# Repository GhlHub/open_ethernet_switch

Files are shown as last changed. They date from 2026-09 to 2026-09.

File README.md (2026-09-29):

# Open Ethernet Switch

A work-in-progress FPGA Ethernet switch for the AMD Kria KR260, with an initial R5
FreeRTOS control plane. The current RTL joins port adapters, MAC
learning/lookup/aging, and a shared DDR packet-buffer architecture under
the reusable blocks described in [`ip_repo`](ip_repo/README.md), with
`rtl/switch_top.sv` retaining the native simulation assembly.

The source now adds [classic STP/RSTP selection and persistent web controls](docs/spanning-tree.md).
Fabric/management 2.1 and the matching firmware are deployed with STP disabled;
STP/RSTP board qualification is deferred.

The current 2026-09-27 lab build uses fabric/management 2.1 and GEM 2.0,
with the switch fabric at 125 MHz. Independent statistics mailboxes provide
per-bank clock/freshness reporting (ABI 2). PL MAC 1.2 and PHY-management 1.1 support full-duplex
10/100/1000 Mb/s on both PL copper ports. SFP 1.1 remains 1G.
Production uses nine catalog instances from six reusable IP kinds.
It includes [CPU TX frame metadata](docs/cpu-tx-metadata.md), pipelined CPU DDR
writes and a [low-priority MAC-table dump master](docs/mac-table-dump.md).
The public `/mac-table` web page displays MAC addresses, ports and ages; its
**Refresh MAC table** button requests a scan. Opening/reloading the page uses
cached data; no automatic scans are scheduled. The latest firmware source also
adds [passive IPv4 discovery](docs/web-interface.md#passive-ipv4-discovery-2026-09-27-deployed)
to this page; it is deployed and verified on the board.

The matching FPGA and R5 firmware are deployed over JTAG at DHCP address
`10.0.1.104`. Routed timing passes (fabric +1.710 ns setup; overall +0.018 ns
setup / +0.010 ns hold). Earlier speed qualification passed both PL ports at
10, 100 and 1000 Mb/s. The current image adds stopped-clock isolation and
public SNMP/web bank availability reporting.
See [deployment evidence](docs/verification.md#2026-09-27-interrupt-driven-cpu-packet-dma)
and the [current backlog](docs/inventory.md#current-remaining-work).

CPU TX/RX completion is interrupt-driven, with blocked-task wakeups and bounded
RX batches. Hardware verification passed 2,000 CPU and 100 forwarded full-size
pings without loss, concurrent HTTP/SNMP, and zero DMA errors or TX timeouts.
The configuration page shows the active IPv4 address, netmask and default gateway
above the saved settings, and uses wider address and credential fields. See
[web interface](docs/web-interface.md).

A [screw-fastened KR260 clamshell](mechanical/kr260-enclosure/README.md) includes
print-ready STLs, assembly STEP, source and a measured carrier-fit report.
Its CAD checks pass; physical print fit and enclosed cooling remain untested.

The intended port map is two PS GEM ports, two PL Ethernet ports, one SFP port,
and one virtual CPU port. The default SFP build is 1G 1000BASE-X.
A [selectable 10GBASE-R MAC/PCS and 128-bit SFP datapath](docs/sfp-10g.md)
is available with `KR260_SFP_MODE=10g`. A [runtime dual-rate build](docs/sfp-dual.md)
uses `KR260_SFP_MODE=dual` for 1G/10G selection without reloading the FPGA.
The dual-rate image is currently running through volatile JTAG. Hardware tests
verified 1G forwarding, Auto recovery, and a hot swap to an XZSNET copper
module with a 10G host link through a 2.5G-capable switch. Small packet losses
also appeared on copper-only controls; loss-free operation, sustained rate
conversion and actual copper-rate confirmation remain open. See the
[verification record](docs/verification.md). Boot flash was not changed.

The board top includes automatic PL PHY initialization and link polling,
RGMII receive clock adaptation, calibration gating, link-event interrupts,
software-controlled port flushing, and SFP I²C/sideband control. The GEM bridges
carry whole 16-bit words across the clock boundary and use buffered TX start
permits. The switch fabric now runs at 125 MHz; MAC adapters transfer whole
words and the egress frame RAM is prefetched for continuous streaming. The board top connects the digital switch to the PS external GEM FIFOs,
DDR interconnect, CPU-facing AXI DMA, two RGMII ports, and the SFP GTH path.
Vivado build scripts and three IP configurations are included. Existing local
implementation reports show a generated bitstream and positive setup/hold
slack under the current constraints. R5 hardware bring-up now demonstrates UART, timers, DHCP acquisition and ping through all four copper Ethernet ports via
the fabric CPU port. Cable moves retained reachability at `10.0.1.214` on the
running debug image. See the [four-port results](docs/verification.md#four-copper-ports-passing-dhcp-address-ping-2026-09-20).
The SFP path now acquires the same DHCP address through an Ipolex copper SFP
and passes settled small/full-MTU ping tests on the debug image; startup loss
and isolated bring-up errors remain under investigation. The managed switch
RX-error counter subsequently remained stable at 803. Together with the
four copper-port results, this establishes the
`20260920-all_ports_passing_dhcp_ping` basic-connectivity milestone.
A subsequent intermittent-loss investigation captured SFP GTH decoder errors;
the receiver now explicitly uses LPM equalization. Initial LPM testing passed
300/300 full-MTU pings to an endpoint through GEM0 and 300/300 patterned
full-MTU CPU pings, with no SFP MAC receive errors. A brief post-boot
interruption in that debug run remains unexplained. The normal image now
runs without ILAs or a debug hub and includes ingress-port exclusion on MAC
lookup hits; it passed DHCP and 300/300 full-MTU pings to both CPU and GEM0
endpoint with zero SFP receive errors. See [SFP results](docs/sfp-debug.md).
**Sustained throughput, fault recovery, remaining CDC review and complete SFP
hardware validation remain pending.**

- [IP partitioning, packaging and verification](docs/ip-partitioning.md)
- [Architecture diagrams and packet flow](docs/architecture.md)
- [Memory map, cache policy and ownership](docs/memory-map.md)
- [Statistics and environmental monitoring](docs/statistics.md)
- [SNMP counter and sensor access](docs/snmp.md)
- [MAC-table dump registers, records and DMA ownership](docs/mac-table-dump.md)
- [Web port configuration, statistics and manual MAC-table view](docs/web-interface.md)
- [PL copper full-duplex 10/100/1000 implementation](docs/pl-ethernet-speeds.md)
- [PS Ethernet speeds and full-duplex advertisement](docs/ps-ethernet-speeds.md)
- [R5 FreeRTOS startup, timers and networking](software/r5/README.md)
- [Minimal A53 Linux boot alongside the R5 switch](software/linux/README.md)
- [Resume point for Linux and AI telemetry work](docs/resume-ai-telemetry.md)
- [Persistent settings and administrator authentication](docs/configuration.md)
- [Standalone R5 USB microSD storage](docs/usb-storage.md)
- [Source inventory and development backlog](docs/inventory.md)
- [Board wiring, clock plan, and integration gaps](docs/board-integration.md)
- [GEM1 ILA debugging and transmit fixes](docs/gem1-debug.md)
- [SFP module, GTH clock/reset and receive-status investigation](docs/sfp-debug.md)
- [Simulation and lint results](docs/verification.md)
- [CDC review and remaining assumptions](docs/cdc-review.md)
- [Imported source and license notices](docs/source-notices.md)

## Current management interface

The current DHCP address is **10.0.1.104**. Viewing
[port configuration](http://10.0.1.104/configuration) and
[live statistics](http://10.0.1.104/statistics) stays public; configuration
changes require administrator authentication (default `admin` / `admin`).
Statistics refresh every second and are also available through SNMP.
Settings are saved on the FAT32 microSD card through the standalone R5 USB
host stack. Missing cards or records select defaults; saves require a card.
See [configuration](docs/configuration.md) for the stored settings and
supported port capabilities.

The digital and PL PHY-management partitions are deployed with all counter
groups enabled. Both PL PHY controllers report successful initialization and
valid polling; live packet tests cover the connected GEM1 uplink and PL0 miner.
RGMII and SFP physical-shell packaging, complete CDC review and broader traffic
qualification remain pending. DHCP waits one second after admitted-link
readiness before its first attempt. Four HTTP workers handle concurrent clients.
See [startup and HTTP findings](docs/startup-and-http-investigation.md) and
[current verification](docs/verification.md) for historical issues and test limits.
See [interface contracts](ip_repo/INTERFACES.md),
[partitioning](docs/ip-partitioning.md) and
[verification](docs/verification.md) for scope and evidence.

## Source layout

| Directory | Contents |
| --- | --- |
| `ip_repo/` | Six IP manifests including PL PHY management, extracted fabric/GEM wrappers, packaging and validation scripts; generated catalog lives in `build/ip_catalog/` |
| `rtl/board/` | Static KR260 board top and PL assembly joining the generated PS block design |
| `rtl/switch_top.sv` | Compatibility wiring assembly around the fabric and physical endpoints |
| `rtl/ps_eth/` | PS GEM external-FIFO to/from AXI-Stream adapters |
| `rtl/pl_gmii/` | PL 1G MAC, stream/RGMII adapters, Clocking Wizard configuration and behavioral models |
| `rtl/sfp_pcs/` | 1000BASE-X PCS and auto-negotiation, SFP MAC/PCS wrapper, GTH wrapper/configuration and behavioral model |
| `rtl/mdio/` | Clause 22 MDIO master, automatic DP83867 setup, AXI-Lite wrapper and portable pin model |
| `rtl/mac_table/` | Header parsing, forwarding decisions, MAC learning, lookup, and aging |
| `rtl/buf_mgr/` | Buffer allocation, reference counts, and destination queues |
| `rtl/dma/` | Physical-port ingress/egress front ends and shared DDR DMA |
| `rtl/cpu_port/` | CPU stream port and dedicated switch-pool DMA |
| `rtl/common/` | FIFOs, reset and port-link synchronizers, and round-robin arbitration |
| `constraints/` | PL RGMII and SFP pins, primary clocks, and implementation CDC path bounds |
| `tb/` | Portable and XSim testbenches, including DMA pipeline/statistics regressions, and an AXI memory model |
| `build/` | Vivado block-design/synthesis/implementation scripts and digital-switch source list |
| `third_party/` | FreeRTOS-LTS submodule (`202604-LTS`), libpayload USB subset, FatFs and SHA-256; provenance retained with each dependency |
| `sim/Makefile` | Icarus simulation, Verilator lint, and XSim targets |

## Run the existing simulations

The inventory baseline was tested with Icarus Verilog 13.0. Run the 25 portable
testbenches from the repository root:

```bash
make -B -C sim sim-mac sim-bufmgr sim-ingress sim-egress \
    sim-ps-eth sim-integ sim-async-fifo sim-pl-gmii \
    sim-sfp-pcs sim-sfp-port sim-cpu-port \
    sim-mac-fwd sim-switch-top sim-gth-sim \
    sim-rgmii-sim sim-pl-clkgen-sim sim-mdio sim-autoneg \
    sim-mac-reset sim-rx-elastic sim-rx-diag sim-mac-adapters sim-pl-linerate
```

Check the final `=== ALL TESTS PASSED ===` or `PASS: errors=0` marker
without any `FAIL:` messages; compound targets must pass every subtest. The existing benches use `$finish` even on failure, so a zero process
exit status alone is not sufficient. Plain `make -C sim sim` runs only the MAC
table test.

The complete inventory includes 26 testbenches: 25 portable benches and one
XSim-only IDELAY calibration bench. See [verification](docs/verification.md)
for fresh results, vendor-FIFO checks and known lint warnings.
[Board build instructions](docs/board-integration.md#board-build-and-implementation-results)
cover Vivado; [third-party setup](third_party/README.md) covers recursive
FreeRTOS-LTS initialization.

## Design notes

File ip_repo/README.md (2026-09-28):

# Open Ethernet Switch IP repository

The eight `manifest.json` files are the source of truth for the reusable
digital blocks and PHY management. `board.json` lists the KR260 physical shell, vendor IP and
constraints. Paths are relative to the repository root. Existing leaf RTL
stays in `rtl/`; each dependency has one editable source copy.

The production fabric clock is 125 MHz. The production BD audit checks its
frequency metadata, and the routed audit checks the actual 8 ns period.
MAC aging remains 4 Hz. See [deployed validation](../docs/verification.md#2026-09-26-125-mhz-fabric-board-deployment)
the [selectable 128-bit 10G SFP interface](../docs/sfp-10g.md),
and the [runtime dual-rate SFP port](../docs/sfp-dual.md).

| Catalog IP (`ghlhub.org:ethernet:<name>:<version>`) | Top module | Responsibility |
| --- | --- | --- |
| `switch_fabric` (2.1) | `switch_fabric` | Five physical packet streams, CPU virtual port, forwarding, shared buffers, DDR masters, fabric counters |
| `gem_port` | `switch_gem_port` | One PS external-FIFO bridge, RX/TX CDC and local packet counters |
| `pl_port` | `pl_gmii_mac_top` | One GMII MAC, packet-stream adapters, local counters and AXI-Lite registers |
| `sfp_port` | `sfp_port_top` | Default 1000BASE-X MAC/PCS, negotiation, packet adapters and counters |
| `sfp_dual_port` (1.0) | `sfp_dual_port` | Runtime 1G/10G MAC/PCS selection, 128-bit streams, mode control and persistent counters; external shared GTH |
| `sfp_10g_port` (1.0) | `sfp_dual_port` (1.0) | `sfp_dual_port` | Runtime 1G/10G MAC/PCS selection, 128-bit streams, mode control and persistent counters; external shared GTH |
| `sfp_10g_port` | Optional 10GBASE-R MAC/PCS, 128-bit packet streams and counters; external GTH |
| `pl_phy_mdio` (1.1) | `switch_pl_phy_mdio` | One PL PHY: AXI-Lite MDIO, DP83867 initialization, link polling and reset-release CDC |
| `management` (2.1) | `switch_management` | Existing AXI-Lite configuration, link control, status and statistics mailbox |

The current partition retains RGMII I/O, GTH/clock generation and SFP
sideband handling in the board layer. These physical shells are **not yet
inside the port IPs**. The production `system.bd` instantiates nine catalog cells
through `production.tcl`. `rtl/switch_top.sv` remains the native simulation
assembly. Management 2.0 owns independent pending mailboxes for all 13 banks,
with source-clock activity monitoring. Fabric and GEM 2.0 use per-bank select
buses; PL MAC 1.2 and SFP 1.1 add clock-progress outputs. PL PHY management
remains 1.1. These source versions require matching statistics ABI-2 firmware;
the matching image and firmware were deployed and tested on 2026-09-26. See [interface contracts](INTERFACES.md).

## Generate and validate a catalog

Run from the repository root, with Vivado 2026.1 on `PATH`:

```sh
vivado -mode batch -nolog -nojournal -source ip_repo/package.tcl
python3 scripts/check_ip_catalog.py build/ip_catalog
vivado -mode batch -nolog -nojournal -source ip_repo/validate.tcl -tclargs build/ip_catalog
python3 scripts/check_ip_catalog.py build/ip_catalog --bd build/ip_refactor/partition_validation
python3 scripts/check_ip_equivalence.py --packaged-bd build/ip_refactor/partition_validation --catalog build/ip_catalog
```

Packaging produces relocatable `component.xml` files and source snapshots
under `build/ip_catalog/`. Add that generated directory to Vivado's
`ip_repo_paths`. Generated source copies are not editable inputs. Packaging
refuses to overwrite an existing catalog; supply a fresh output directory
with `-tclargs build/ip_refactor/catalog_name` when rebuilding it.

`validate.tcl` creates a separate `partition_validation.bd` with nine
instances (fabric, two GEM, two PL MAC, SFP, management and two PHY MDIO). All ten
physical packet-stream connections are present. The remaining interfaces
are exposed as external test boundaries. Its fabric uses both optional
counter groups and a short aging divider for the simulation fixture.
Its automatically assigned addresses and external clocks are **not a KR260
deployment configuration**.

## Build and simulation

```sh
python3 scripts/ip_sources.py --board-only
make -C sim sim-switch-top sim-ingress sim-bufmgr sim-statistics
make -C sim sim-ip-equivalence
KR260_PROJECT_DIR="$PWD/build/ip_refactor/production_bd/project" STATS_DDR=1 STATS_DEBUG=1 \
  vivado -mode batch -nolog -nojournal -source build/build_kr260.tcl -tclargs impl
vivado -mode batch -nolog -nojournal -source ip_repo/review_board.tcl -tclargs \
  build/ip_refactor/production_bd/project/kr260_switch.runs/impl_1/kr260_top_routed.dcp \
  build/ip_refactor/production_bd/reports
```

The board build checks catalog source hashes before using its staged RTL.
Only physical-shell RTL is added directly; digital
RTL comes from the catalog cells. Simulation resolves the same manifests.
`KR260_IP_CATALOG` selects an alternative generated catalog directory.
The board script retains its usual `build/vivado_kr260` default; the
explicit output override preserves the existing project during migration.
Firmware retains the existing matching `STATS_DDR`/`STATS_DEBUG` options
and register ABI. No firmware changes are required by this partition.

## Independent IP regression suites

Each package owns a `tests.json` list, run by `scripts/check_ip_tests.py`.
The runner compiles only that IP's manifest dependencies plus explicitly
listed test-boundary support. Suite-level `simulation_support` supplies only
external primitives (currently IOBUF) for public-top elaboration and tests;
these models are never packaged as synthesis RTL. It independently elaborates the public top,
then runs the behavioral cases. `--catalog` uses the staged RTL of that
specific package after auditing its metadata and source hashes.

```sh
# All six IPs, from editable sources:
make -C sim sim-ip-tests
# One IP while developing it:
python3 scripts/check_ip_tests.py --core gem_port
# Run against a generated catalog:
make -C sim sim-ip-tests-packaged IP_CATALOG=../build/ip_catalog
# Native + packaged suites, followed by all four whole-switch comparisons:
make -C sim sim-ip-regression
```

| Package | Behavioral coverage |
| --- | --- |
| GEM | Public wrapper packet/CDC regression at 125/25/2.5 MHz; RX/TX counter accounting |
| PL | Public MAC loopback/line-rate/counters; adapters, reset/reclock |
| SFP | Public MAC/PCS loopback; negotiation, clock correction, TX alignment, RX preamble |
| Fabric | DMA burst pipeline/backpressure/reset; buffer ownership; forwarding/learning/control traffic; CPU DDR transfers; AXI counters |
| Management | AXI-Lite controls/diagnostics; mailbox CDC, clear races, saturation, response backpressure and stopped-clock retry; public wrapper bank routing across all 256 indices |
| PL PHY MDIO | Actual IOBUF-backed controller; read/write/status; DP83867 setup, polling and recovery at PHY addresses 2 and 3 |

The 30 cases reuse the established self-checking benches. The GEM bench can
select the public `switch_gem_port` wrapper instead of its bridge leaf.
Fabric cases exercise constituent blocks; the retained whole-switch miter
checks their assembly. They do not constitute a new randomized six-port
concurrent scoreboard or physical timing/CDC sign-off.

Each compile/simulation has a wall-clock timeout. Nonzero exits, explicit
FAIL/FATAL/ERROR messages, failed test summaries and missing success markers
fail the runner, including legacy benches that report failure via `$finish`.
Per-case logs and a completion-marked JSON report live under
`build/ip_refactor/ip_tests/{native,packaged}/`. Running a selected core
replaces that mode's report with the selected run only.

The catalog audit checks VLNV identity, source contents and relocatable
paths, clock associations, complete AXI/AXI-Stream port mappings and modes,
and packet-stream widths/directions. Generate a fresh catalog using
`package.tcl` before testing changed RTL; stale snapshots deliberately fail.
The existing `validate.tcl` and generated-production-BD equivalence checks
remain integration gates after packaging or connectivity changes.

## Contracts and fresh acceptance flow

[Interface contracts](INTERFACES.md) define clock/reset ownership, packet and
DDR interfaces, register ownership, parameters, bank routing and versioning.
Management 1.1 replaces the old external raw mailbox with per-bank request,
acknowledgment and value pins; firmware addresses and bank numbers are unchanged.
Existing generated catalogs must be regenerated after this change.

From a checkout (the production fixture also reads historical board wiring),
Vivado 2026.1, Python 3 and Icarus Verilog available:

```sh
python3 scripts/verify_ip_flow.py
# Or: make -C sim verify-ip-flow
# Optionally include implementation, bitstream and routed reports:
python3 scripts/verify_ip_flow.py --implement
```

The default uses a new directory under `build/ip_refactor/acceptance_*` and
preserves existing projects/catalogs. `--output` accepts only a new directory;
`--vivado` selects the Vivado executable. It packages the catalog, audits it,
generates and audits the production BD with all counters, runs native and
packaged IP suites, and compares all four native counter combinations plus
the generated production datapath. Every stage has a log, a timeout and a
record in `results.json`; `complete` becomes true only after all stages pass.
Default execution stops before synthesis. The optional routed report stage
collects timing/CDC findings; report generation alone is not timing sign-off.
Board programming and traffic checks remain separate hardware acceptance.

## CPU TX ABI change (2026-09-26)

See [CPU transmit metadata](../docs/cpu-tx-metadata.md). Native counter-option
runs now exercise the current functional regression; generated/native assembly
miters compare the current contract. They do not claim raw-stream historical
equivalence across this intentional ABI change.

Fabric 1.2 adds a lowest-priority MAC-table dump writer on HP0 and a control
slave at 0x80110000. Both use the fabric clock. See the
[register, burst and ownership contract](../docs/mac-table-dump.md).

Fabric/management 2.1 add [STP destination gating, tag backpressure and capability identification](../docs/spanning-tree.md).
Version 2.1 was routed and deployed on 2026-09-27. Basic forwarding and management
were checked with STP disabled; protocol board qualification is deferred.

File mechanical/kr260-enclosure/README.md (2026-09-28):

# KR260 A02 screw-fastened clamshell — revision 2

This revision is built around the **supplied carrier STEP assembly**, including
its connectors, SOM, heatsink and fan. It replaces the previous adjustable-rail
prototype with four fixed PCB mounting posts, mostly closed side walls, measured
connector openings and a microSD finger recess.

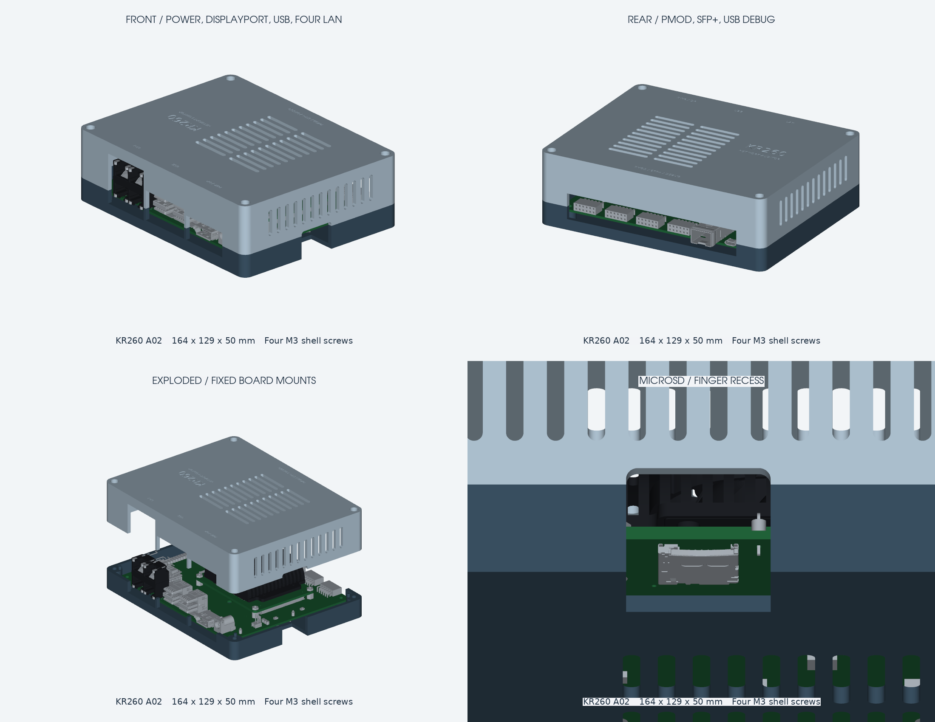
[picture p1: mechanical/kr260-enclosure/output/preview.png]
Enclosure and carrier, front, rear, exploded and microSD views


## Print files

| File | Use |
| --- | --- |
| [base.stl](output/base.stl) | Lower shell with four integral PCB mounting posts; print 1 |
| [lid.stl](output/lid.stl) | Upper shell, already rotated roof-down for printing; print 1 |
| [fit_frame.stl](output/fit_frame.stl) | Optional reduced-material check of the exact four mounting positions |
| [fit_coupon.stl](output/fit_coupon.stl) | Insert and screw-hole sizing sample; print first |
| [clamshell.step](output/clamshell.step) | Both shells in assembled coordinates, without vendor board geometry |
| [reference_measurements.json](output/reference_measurements.json) | Extracted source dimensions and interface bounds |
| [validation.json](output/validation.json) | Geometry, reference collision and exported mesh checks |
| [kr260-enclosure.zip](kr260-enclosure.zip) | Current print files, STEP, preview, source and this guide |

Only **two printed parts** are needed for the finished enclosure. There are no
sliding rails, loose spacers or hinge. The shells lift apart after removing four
screws. The old prototype is preserved in `archive/` and is not in the current ZIP.

## Geometry and connector access

* Body: **164 × 129 × 50 mm**, excluding feet and the projecting SFP cage.
* Walls, floor and roof: 3 mm; shell seam: z=16 mm.
* PCB top: z=12 mm; underside/support plane: z=10.414532 mm.
* PCB posts: 8.5 mm diameter, approximately 7.415 mm above the inside floor.
* Stock fan cover: z=40.75 mm; inside roof: z=47 mm, giving **6.25 mm clearance**.
* Four locating pins align the shells. Corner screw wells accept M3 socket heads.
* 22 roof slots over the fan, 18 floor slots and 13 exhaust slots on each side.

The edge with the barrel jack and RJ45s is called the **front** here; it is +Y in
CAD coordinates. The rear is the Pmod/SFP/debug edge. The SD edge is -X.

| Interface | Access provided |
| --- | --- |
| Four RJ45 network ports | One front opening around the measured 2 × 2 jack assembly, with extra vertical room for latches |
| Four USB-A ports | Front opening spanning both stacked USB housings, sized for an 18 mm plug-body width target |
| Power and DisplayPort | Shared front opening so the power plug body can enter the recessed jack |
| SFP, Pmods and micro-USB debug | Continuous rear service opening; the SFP cage projects through it |
| microSD | Dedicated left-side opening and a rounded recess through the floor below the socket, for finger access |

The rear SFP cage extends about 4.14 mm beyond the body. Its opening and the front
connector openings cross the seam, allowing vertical installation/removal of the
board. No cable needs to pass through a closed hole during assembly. The model
contains connector bodies, not your cable overmoulds, SFP module/bail or removable
SD card; check insertion, removal and latch operation with your actual parts.
Internal HAT/JTAG headers require lid removal.
The webs separating the three front openings remain at least 2 mm thick.

## Measured mounting pattern

The four carrier mounting holes have nominal diameter **3.4036 mm** in the STEP.
The following coordinates are preserved from the source instead of rounding the
pattern to a perfect rectangle:

| Hole | Source X / Y (mm) | Enclosure X / Y (mm) |
| --- | --- | --- |
| Rear left | 0 / 0 | 17 / 10 |
| Front left | 0 / 109.0000081 | 17 / 119.0000081 |
| Rear right | 130.0033011 / 0.0149860 | 147.0033011 / 10.0149860 |
| Front right | 130.0033011 / 108.9820528 | 147.0033011 / 118.9820528 |

The source PCB outline is approximately 140 × 119 mm with approximately 1.585 mm
thickness. The source origin is a mounting-hole centre, not the PCB corner. The
whole reference is translated by **(+17, +10, +12) mm**, without rotating or
rescaling it.

**Remove the four stock rubber bumpers before mounting the carrier.** They occupy
the same locations as the new integral PCB posts. The collision check explicitly
removes these four solids, and retains every other source solid. Leave the SOM,
heatsink, fan and their attachment hardware assembled.

## Hardware

| Quantity | Item |
| --- | --- |
| 4 | M3 × 10 mm socket-head screws, joining the shells |
| 4 | M3 × 6 mm screws, fastening the carrier to its posts |
| 4 | Thin insulating M3 washers for the carrier screws, about 0.5 mm thick |
| 8 | M3 heat-set inserts, nominal 4.5–4.6 mm OD × 5 mm long |
| 4 | Adhesive rubber feet, at least 3 mm tall, to let air reach the floor vents |

Four inserts fit the PCB posts; four fit the shell corner posts. The printed
pilot bores are **4.2 mm diameter × 6 mm deep**. Verify the bore size with the
coupon and your insert supplier's requirements; adjust `INSERT_BORE` before
printing if needed. In the coupon, x=8 is the blind insert hole and x=22 is the
3.4 mm through-hole for an M3 screw.

Shell screw heads sit on a 4 mm thick seat at z=20 mm, down a 6.6 mm diameter
well. Use a straight hex driver with at least 35 mm reach. With the stated screws,
there is 6 mm insertion below the shell seat and approximately 3.9 mm insertion
below the PCB and washer. Confirm actual screw lengths and insert seating; do not
bottom screws or distort the PCB.

## Print and assembly

1. Print the insert coupon. Optionally print the fit frame to check all four
   mounting points cheaply against your actual carrier. The frame is a test
   piece, not a part to install in the finished enclosure.
2. Print the base and lid using the supplied orientations: base floor-down and
   lid roof-down. The lid is rotated, **not mirrored**. Main port openings meet
   the seam; side vent bridges span only 3 mm.
3. Suggested starting settings: PETG, 0.2 mm layers, 0.4 mm nozzle, four walls,
   five top/bottom layers and 30% infill. Inspect the slicer preview, especially
   the engraved first layers of the lid and the small alignment pins.
4. Install the eight inserts with the carrier removed. Seat each flush with its
   post and let it cool completely.
5. Remove the four stock rubber bumpers. Lower the carrier onto the four PCB
   posts with the SFP cage pointing through the rear opening. Confirm all four
   holes align and the board sits flat before tightening the M3 × 6 screws with
   insulating washers. Do not disturb the SOM mounting hardware.
6. Fit your cables, SFP module and SD card and check their release mechanisms.
   The SD card should be reachable through the left opening and bottom recess.
7. Lower the lid onto the locating pins. Insert the four M3 × 10 screws down the
   corner wells and tighten gently. Add rubber feet near the underside corners.
8. Check fan operation and operating temperature under your intended workload.
   Printed fit, plug compatibility and enclosed thermal performance have not
   been physically tested.

## Source and validation

Reference: `KR260-startkit-A02.stp`, from the user-provided
`xtp744-kr260-carrier-card-3d-cad-model` package. Downloaded reference packages
are kept local and are not redistributed in this repository. To regenerate,
place that STEP at
`docs/xtp744-kr260-carrier-card-3d-cad-model/KR260-startkit-A02.stp`.
The exported enclosure STEP contains only the newly designed shells. The STEP
header is dated 2021-10-15 and identifies the KR260 starter-kit assembly. SHA-256:

```text
e0f0c13cc73c76044cc1f1fdcb342210f86a7b1b683ed856eb87fc75d8a040e0
```

`reference.py` extracts mounting circles from the PCB geometry, locates the four
rubber bumpers, and records connector bounds. The source hash guards the component
mapping against accidental use with a different STEP revision. Hole centres use
the analytic circle centre, not the centre of mass of a semicircular edge.

`build.py` checks:

* Valid, single-solid CAD parts and zero shell-to-shell intersection.
* No obstruction of the intended access-opening volumes by either shell.
* Each shell against **all 6,949 installed reference solids**. A conservative
  bounding-box filter excludes components wholly in free space; remaining
  candidates receive exact solid intersection checks. Only the four removed
  rubber bumpers are excluded. Intentional PCB contact on the standoffs has zero
  intersection volume.
* Watertight STL meshes, consistent winding, one connected component per part,
  positive volume, and correct placement on the print bed.

These are CAD fit checks against the supplied A02 assembly, not a physical fit
certification for another board revision. Small components may be omitted in the
preview for readability; they are still included in collision checking. The ZIP
and enclosure STEP do not duplicate the supplied vendor STEP geometry.

## Regenerate

Keep the supplied STEP in its current `docs` location, then run from the repo root:

```sh
python3 -m venv /tmp/kr260-cad
/tmp/kr260-cad/bin/pip install -r mechanical/kr260-enclosure/requirements.txt
/tmp/kr260-cad/bin/python mechanical/kr260-enclosure/build.py
```

The first run imports the 94 MB STEP and caches its BREP in the temporary
directory under a source-hash-specific filename. Regeneration exports the current
STLs, STEP, measurement report, validation report, four-view preview and ZIP.

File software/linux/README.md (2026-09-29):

# Minimal A53 Linux alongside the R5 switch

This is a **volatile JTAG development boot**, with an uncompressed arm64 kernel,
static BusyBox initramfs and a serial root shell. The RAM filesystem is disposable.
QSPI, microSD configuration, and the existing FPGA design are not changed.

Linux owns the four A53 cores, their GIC/timer, and UART1. R5-0 continues to own
switch management, GEM0/GEM1, the PL CPU DMA and MACs, USB0 storage, I2C1/sensors,
and TTC0/TTC1. R5-1 stays reset. Build R5 with `LINUX_CONSOLE=1` to relinquish
UART1: its wrapped output still goes to `board_log`, and its web interface remains
available. The default `LINUX_CONSOLE=0` keeps the existing standalone behaviour.

The deliberately small device tree omits R5-owned peripherals and Linux PS power
management. Clocks are established by the design's FSBL and left running. This
is a first-boot ownership contract, not a complete Linux board-support package.
It does not provide a Linux network interface, persistent storage, remoteproc,
RPMsg, telemetry DMA, CPU frequency scaling, or suspend. Adding those requires
an explicit ownership/power-management review; do not substitute a stock KR260
device tree because it would claim peripherals already used by R5.

## Memory and boot chain

Linux initially uses only the low 2 GiB of DDR. Both existing reservations are
marked `no-map`: the 512 KiB PL packet pool at `0x10000000`, and all 32 MiB of R5
DDR at `0x20000000` (including USB and Ethernet DMA regions).

| Payload | Load address | Lifetime |
| --- | --- | --- |
| Linux `Image` | `0x00200000` | Kernel; runtime extent checked against DTB |
| Device tree | `0x04000000` | Linux boot data |
| Compressed initramfs | `0x06000000` | Linux unpacks into RAM |
| BL33 entry shim | Entry `0x08000000` | Temporary; ELF LOAD includes header page below entry |
| TF-A BL31 | OCM, entry `0xFFFEA000` in tested build | Secure monitor/PSCI |
| R5 ELF | R5 local ATCM and reserved DDR | Existing application |

Boot order: system reset with temporary JTAG boot-mode override, PMU firmware,
the **current switch XSA's FSBL**, existing switch bitstream, halted R5 ELF,
Linux payloads, then TF-A. TF-A enters a tiny BL33 shim at EL2; it passes the DTB
and branches to Linux following the [arm64 boot protocol](https://docs.kernel.org/arch/arm64/booting.html).
R5 starts 15 seconds later. That delay is sequencing, not proof of Linux readiness;
the UART readiness marker and hardware checks below establish success. No U-Boot
is needed for this RAM-only experiment. The boot-mode override is restored on exit.

## Build and stage

Prerequisites: Vitis 2026.1 cross tools and XSDB, Python 3, `dtc`, host C compiler,
GNU make, curl, tar, and the existing R5 BSP/FSBL plus routed switch bitstream.

```sh
bash software/linux/build_busybox.sh /tmp/kr260-linux-boot
make -C software/r5 -j16 LINUX_CONSOLE=1 STATS_DDR=1 STATS_DEBUG=1
python3 software/linux/prepare.py \
  --kernel /path/to/Image \
  --atf /path/to/bl31.elf \
  --pmufw /path/to/pmufw.elf \
  --busybox /tmp/kr260-linux-boot/busybox-1.37.0/busybox \
  --r5 software/r5/out/kr260_r5.elf
python3 software/linux/verify.py
```

The statistics flags above match the current dual-rate FPGA image; always match
them to the chosen bitstream's capabilities. A mismatch disables statistics.

`prepare.py` takes external kernel/firmware explicitly and writes hashes and input
paths to `build/linux/manifest.json`. It requires a little-endian arm64 `Image`
with zero text offset, static BusyBox, and the Linux-console R5 ELF marker.
The preboot verifier checks hashes, memory reservations and payload placement.
BusyBox 1.37.0 is downloaded from its official site and SHA-256 checked before
building; the build script includes the AMD compiler-wrapper workaround.

The initial components come from locally built AMD EDF 2026.1 artifacts:

- Linux 6.18.10, `Xilinx/linux-xlnx` revision
  `4f7afe14f7246986ca858d9a0880f5db6ba02a4b`.
- TF-A 2.14.0, `Xilinx/arm-trusted-firmware` revision
  `501fae71936c40f59b493b76fb41f4d0fbb1b139`, built with
  `PLAT=zynqmp ZYNQMP_CONSOLE=cadence1 PRELOADED_BL33_BASE=0x08000000`.
- PMU firmware from `Xilinx/embeddedsw` revision
  `2177ef5d0e8bc6049d59034377c3c9afc9dbb21a`, with PM support enabled.

Their local deploy root is `/tmp/kv260-yocto-2026.1/tmp/deploy/images/`:
`amd-cortexa53-mali-common/Image`, and `k26-smk-kv-sdt/arm-trusted-firmware.elf`
plus `k26-smk-kv-sdt/pmu-firmware-k26-smk-kv-sdt.elf`. Only these components are
reused; the KV260 FSBL, board device tree and U-Boot are **not** used. The kernel
is an existing general AMD kernel; the userspace and exposed hardware are minimal.
Rebuilding that kernel/firmware uses their pinned EDF recipes, not this script.

## Boot and verify

Connect the UART bridge with `telnet 10.0.1.109 2323`, then run:

```sh
/tools/Xilinx/2026.1/Vitis/bin/xsdb software/linux/boot_jtag.tcl \
  tcp:10.0.1.109:3121 \
  build/ip_refactor/sfpdual_release3/project/kr260_switch.runs/impl_dual_timing2/kr260_top.bit
```

This replaces the running volatile session. Expect several minutes for JTAG
transfers. Success requires `KR260_MINIMAL_LINUX_READY` on UART, followed by:

```sh
uname -a
cat /sys/devices/system/cpu/online
cat /proc/meminfo
cat /proc/iomem
cat /proc/interrupts
```

Check four CPUs (`0-3`), both reserved memory ranges, shell input/interrupts,
and the R5 webpage/statistics while Linux runs. Test endpoint forwarding under
A53 memory/CPU activity. A boot message alone is not a coexistence test.
The console is an unauthenticated development root shell, not a deployed service.
Press Enter for the `~ #` prompt. To disconnect from the command-line Telnet
client, press Ctrl+] and enter `quit`. Linux has no SSH or network interface in
this image; `10.0.1.104` remains the R5 management address.

### Telnet inserts `?` before the next command

An older UART Telnet bridge forwards Telnet's `CR NUL` directly to the UART.
BusyBox then shows `~ # ?`, and the next command fails as `?command: not found`.
This was reproduced on the running board; it is a bridge input-decoding issue.

The fixed bridge has now been restarted on the Windows host, and the user
confirmed that the Linux console works correctly. No client workaround is needed
with the updated bridge.

For older bridge deployments, a workaround with the command-line Telnet client is
to press
**Ctrl+]**, enter `toggle crlf`, then press **Ctrl+C** at the Linux console to
clear the corrupted input. Subsequent commands work, though the old bridge may
show an extra blank prompt. Toggle only when needed: the client should report
`Will send carriage returns as telnet <CR><LF>`.

The permanent fix is in the separate `uart_telnet_bridge` project: retain
Telnet parsing state across TCP receives and convert both `CR NUL` and `CR LF`
to one UART CR. Updating/restarting that bridge does not require a Linux or
FPGA rebuild. The fix passed all ten bridge tests on 2026-09-28; deployment
to the bridge host is separate from the KR260 boot image.

## Hardware qualification — 2026-09-28

The final JTAG boot completed on the KR260 with Linux 6.18.10 and all four A53
cores online. `/proc/iomem` confirmed both `no-map` reservations. The serial
shell worked, and the interrupt report showed activity on all four CPUs with
`Err: 0`. Linux reported 1,946 MiB usable memory from the initial low-DDR bank.

While four CPU-pinned processes each hashed the same 128 MiB RAM file five
times, all **20 hashes matched** the host-computed value. All **16 concurrent
R5 statistics requests succeeded**; the statistics poll count advanced from
28 to 98 with zero read/release/response timeouts. Sensors remained valid with
zero reported errors. R5 configuration reported its saved settings present
and storage writable; no configuration write was performed.

| Full-size ICMP check | Result |
| --- | --- |
| R5 management `10.0.1.104`, during A53 load | 200/200 replies |
| SFP endpoint `10.0.1.135`, during A53 load | 200/200 replies |
| PL1 endpoint `10.0.1.140`, during A53 load | 199/200 replies |
| PL1 endpoint, subsequent idle-A53 control | 497/500 replies |

PL1's intermittent packet loss remains unresolved. Loss also occurred with
Linux idle; these short tests do not establish its cause or qualify line-rate
forwarding. The SFP host interface reported 10G; this does not measure the
copper module's cable-side negotiated rate.

Both R5 console variants built, the existing R5 regression suite passed, and
the boot checker rejected a standalone-console ELF, a changed kernel hash,
and a shortened R5 reservation. An initial boot exposed a statistics build-flag
mismatch and incorrect early-console baud programming; both were corrected
before the final boot and tests above.

Local evidence is under `build/linux/`: `boot-final.log`, `uart-final.log`,
`linux-final-check.log`, `live-results.json`, `stats-final-{before,after}.json`,
`http-during-load.json`, ping logs, and the artifact manifest. Final tested hashes:

| Artifact | SHA-256 |
| --- | --- |
| `Image` | `4e5ae9e5fb8f1f3317636ce2788af06ff91af514848a80527a7facaebefd3ddc` |
| `r5-linux.elf` | `97fd5b350fc455b3ab70fcf9b22c4e08aeacbcf6a3bdd6ff1c600869d095be28` |
| `system.dtb` | `593176acb5ca220a6c547e2dede07ef361a8215821ddfbda4c599effc7eab8a2` |
| `rootfs.cpio.gz` | `daf7a39d96a61e7739482bbe0d899c12ce2386961515b569e84a2315c59f7154` |

## Return to standalone R5

```sh
make -C software/r5 -j16 LINUX_CONSOLE=0 STATS_DDR=1 STATS_DEBUG=1
/tools/Xilinx/2026.1/Vitis/bin/xsdb software/r5/boot_jtag.tcl \
  tcp:10.0.1.109:3121 \
  build/ip_refactor/sfpdual_release3/project/kr260_switch.runs/impl_dual_timing2/kr260_top.bit
```

This resets the A53/Linux session and restores the R5 serial console without
writing persistent media.

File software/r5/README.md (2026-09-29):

# R5 FreeRTOS bring-up

Initial firmware for **R5-0 in split mode**. The kernel (11.3.1), GCC ARM_CR5
port and FreeRTOS+TCP come directly from the pinned `third_party/FreeRTOS-LTS`
checkout. The Vitis standalone BSP supplies startup, GIC/TTC drivers and formatting;
its FreeRTOS distribution is not linked. R5-1 must remain parked.

For the optional [A53 Linux JTAG boot](../linux/README.md), build with
`LINUX_CONSOLE=1`. R5 then leaves UART1 entirely to Linux and retains its RAM
diagnostic log and web interface. The default `LINUX_CONSOLE=0` preserves the
standalone console. Linux must reserve the R5/PL DDR ranges and leave all other
R5-owned peripherals untouched; use the dedicated minimal device tree.

Implemented:

- Hardware initialization of the RPU GIC, two TTC counters, fabric MACs,
  GEM external-FIFO mode, PS PHY management and CPU-port AXI DMA SG rings.
- TTC0 counter 0 (`0xff110000`, IRQ 68): 1000 Hz RTOS tick. TTC1 counter 0
  (`0xff120000`): continuous timestamp counter, input clock divided by 128.
  The generated BSP reports 100 MHz input, giving 781250 timestamp counts/s.
  `board_timestamp()` extends the 32-bit counter to 64 bits; the tick samples
  wraps without resetting it. Interrupts must not be masked for a full counter
  wrap (~91.6 minutes). Resolution is 1.28 microseconds, not one microsecond.
- A single `fabric0` network interface through virtual switch port 5 and AXI
  DMA at `0x80000000`. The GEMs are physical switch ports, not FreeRTOS NICs.
  RX uses 16 SG descriptors and interrupt-driven task notifications; TX uses
  two alternating descriptors and blocks on an interrupt semaphore (100 ms
  timeout). MM2S/S2MM use level-high GIC IRQs 127/128, priority `0xa0`,
  completion threshold one, with completion and error interrupts enabled. Buffers are copied; D-cache is enabled for application memory, while DMA
  descriptors and bounce buffers occupy a reserved non-cacheable MPU region.
- A 250 ms `vTaskDelayUntil` task samples all five physical ports. GEM0/GEM1
  DP83867 PHYs (addresses 4/9, verified on the development carrier) are read
  over GEM1's shared MDIO bus. PL0/PL1
  PHYs (addresses 2/3) are read through their hardware-maintained PHYSTS
  snapshots: the RTL pollers run about every 10 ms. Firmware pauses new polls
  and waits for idle before changing full-duplex advertisements. SFP uses PCS state and module/LOS/fault
  signals, since it has no copper MDIO PHY.
- GEM1 and both PL ports support 10/100/1000 full duplex; GEM0 and SFP
  admit only 1 Gb/s full duplex. PL rate changes quiesce and flush before
  selecting independent RX/TX byte pacing. PHY read
  failures disable the affected link; failed PL hardware polls now invalidate
  their cached state. PS PHY initialization failures are retried on later polls.
- Link-down writes `LINK_CLR` once per transition. Re-enable waits at least
  one poll interval and for flush busy to clear. The CPU port remains enabled
  while all physical ports are down. A DMA fault disables all destinations and
  requires reboot; descriptors possibly owned by DMA are never reused.
- DHCP starts after any admitted physical link has remained available for at
  least one second (evaluated on the 250 ms poll). This does not hold physical
  forwarding. FreeRTOS+TCP handles discovery, request, renewal and rebinding.
  Its maximum retransmission period is 32 seconds, allowing retries after the
  initial 5-second interval; the previous 8-second ceiling suppressed every
  Discover retransmission. After an acquisition attempt
  fails, the firmware waits **60 seconds from failure** and requests another
  attempt through `FreeRTOS_NetworkDown()` in task context. Each subsequent
  failure schedules another 60-second wait. No static fallback address is
  assigned (defaults are zero). The stack may report its default-address event;
  firmware does not treat that event as a DHCP lease. Link recovery starts a
  fresh attempt. Retry policy uses the stack's success/failure trace callbacks.

## Persistent settings

The CPU uses the first of five allocated board MACs, `00:0a:35:0f:37:45`.
microSD settings include the full allocation, administrator password verifier,
port preferences and DHCP/static IPv4. The configuration webpage and
`scripts/configure_switch.py` save them. See [configuration](../../docs/configuration.md)
for supported speeds, storage ownership, authentication status and recovery.
Build with `CONFIG_RECOVERY=1` only for a deliberate JTAG recovery session;
it bypasses saved settings without automatic card writes.

Storage stays entirely on R5: USB0 xHCI, the onboard hub/card reader, and FatFs.
No card or no valid configuration selects defaults; saves require a FAT card.
Viewing stays public, and configuration writes require `admin` / `admin` by
factory default. USB DMA has a separate 1 MiB non-cacheable reservation.
See [USB implementation and board verification](../../docs/usb-storage.md).
The saved DHCP configuration currently acquires `10.0.1.104`.

## Build

Vitis/Vivado 2026.1 and their R5 GCC toolchain are the tested tools. From the
repository root, with the existing Vivado board project generated:

```sh
git submodule update --init --recursive -- third_party/FreeRTOS-LTS
mkdir -p build/r5
source /tools/Xilinx/2026.1/Vivado/settings64.sh
vivado -mode batch -source software/r5/export_hardware.tcl -nolog -nojournal
/tools/Xilinx/2026.1/Vitis/bin/vitis -s software/r5/create_platform.py
make -C software/r5 -j8
make -C software/r5 test
```

Output: `software/r5/out/kr260_r5.elf` and `.map`. Generated XSA, BSP and FSBL
are under `build/r5/`. The platform script reuses its workspace and updates
its hardware on subsequent runs. `XILINX` and `BSP` can be overridden for Make.
The linker script is adapted from AMD's MIT-licensed `lscript_r5.ld.in`.

## Boot and memory contract

Boot through an appropriate ZynqMP FSBL/PMU firmware flow before starting the
ELF: PS clock/reset, DDR, MIO, PS-GTR and carrier PHY reset initialization must
already be complete, and the fabric must be programmed and clocked. Calling
`main()` alone on an uninitialized PS is not supported. Platform creation also
generates an FSBL, but this change does not package or flash a BOOT.BIN.

The development board's hardware server is `10.0.1.107:3121`; its UART telnet
bridge is `10.0.1.107:2323`. After building the platform, firmware and bitstream,
start a volatile JTAG session from the repository root:

```sh
/tools/Xilinx/2026.1/Vitis/bin/xsdb software/r5/boot_jtag.tcl tcp:10.0.1.107:3121 \
  build/ip_refactor/fabric125_impl/project/kr260_switch.runs/impl_1/kr260_top.bit
/tools/Xilinx/2026.1/Vitis/bin/xsdb software/r5/status_jtag.tcl
```

This resets the PS, runs the A53 FSBL, selects R5 split mode, programs the PL,
releases PS/PL isolation and starts R5-0. A53-0 stays halted and R5-1 stays in
reset. It replaces the current session but does not write flash. An optional
argument overrides the hardware-server URL. The temporary JTAG boot override
is restored even if FSBL initialization fails. Use `xsdb`; Vitis 2026.1 disables
the older `xsct` entry point.

The platform script selects UART1 for both the application BSP and FSBL BSP,
and refreshes the FSBL's local `psu_init.c/h` from the exported hardware.
Vitis hardware updates alone can retain stale FSBL initialization files.

Use a newly built bitstream containing `PCS_STATUS` at diagnostic offset
`0x20`; the previous bitstream reads zero there and cannot admit SFP traffic.
The exported XSA describes the BD; exporting it does not rebuild the PL RTL.

See the [complete memory map and ownership contract](../../docs/memory-map.md)
for DMA handoffs, register windows and internal FPGA memories.

| Region | Owner |
| --- | --- |
| `0x00000000–0x0000ffff` | R5-0 ATCM reset/startup vectors |
| `0x10000000–0x1007ffff` | Fabric packet pool, exclusively reserved |
| `0x20000000–0x21ff7fff` | R5 firmware and RTOS heap/stacks; cacheable DDR |
| `0x21ff8000–0x21ffffff` | 32 KiB DMA region; normal non-cacheable, shareable, execute-never |

Other processors, boot payloads and OS memory maps must reserve both DDR
reservations (the R5 reservation includes both cacheable and DMA subregions).
D-cache is enabled after a higher-priority MPU region is installed for
`.dma_nocache`. All 18 descriptors and 18 bounce buffers live there, aligned
to 64 bytes; driver state, FreeRTOS heap and stacks retain the BSP's cacheable
DDR mapping. MMIO retains the BSP's non-cacheable attributes.
The DMA section is NOLOAD and explicitly cleared after DMA reset, before
ownership is handed to hardware. The driver still uses memory barriers;
per-packet cache maintenance is unnecessary because DMA never accesses the
cacheable application buffers directly. Instruction caching is unchanged.
The ELF audit checks DMA placement/alignment and application-memory separation.
Startup checks read back MPU registers and confirm SCTLR MPU/D-cache enable bits.

**Future work: review the DMA descriptor and packet-buffer cache policy.**
Keeping both non-cacheable is the initial implementation, not a final performance
decision. Measure CPU cost and throughput, then evaluate descriptor and payload
policies separately, including keeping descriptors uncached while caching packet
buffers. Any cached DMA storage requires explicit clean/invalidate operations at
ownership transfers, cache-line isolation, and tests for ring reuse, reset and
error recovery. Retain the current policy until a replacement is validated.

JTAG reads through the PSU see DDR, not necessarily dirty R5 cache contents.
Values such as `xTickCount`, driver state and the UART software log can therefore
appear stale in `status_jtag.tcl`. Use UART output and live network traffic for
firmware liveness; MMIO and the non-cacheable DMA region remain directly readable.

Board CPU MAC: `00:0a:35:0f:37:45`; use a separate allocation per board before
connecting multiple boards. DHCP transaction/TCP sequence randomness is a
noncryptographic timestamp-seeded PRNG; do not use it for security keys.
The regenerated design enables **PS UART1 at `0xff010000`**, on MIO36/MIO37
through the carrier FTDI console. The platform script selects UART1 for BSP
stdin/stdout. Firmware initializes it to **115200 baud, 8 data bits, no parity,
one stop bit, no hardware flow control** before other board initialization.
Use the carrier UART serial device with those settings.

`console.c` wraps `outbyte` to send output to UART1 and mirror every character
into the 4096-byte RAM log. UART writes use bounded polling; characters that
cannot be sent within the polling limit increment `board_uart_dropped` and
remain in RAM. Before UART initialization, logging uses RAM only. Inspect
`board_log` and `board_log_written` with the debugger (oldest character after
wrap is at `board_log_written & 4095`). The firmware rejects an outdated BSP
that does not select UART1 at build time. Regenerate the XSA/BSP and use the
matching FSBL so the MIO routing, UART reference clock and resets are configured.
Fatal assertions park the CPU and
log the source location; exception vectors park at `r5_fault_handler` for
inspection in a debugger.

## Validation and remaining work

The R5 ELF cross-compiles and links against the generated board BSP. A link-time
audit checks the entry point, ATCM IRQ/SVC targets, resolved symbols and DDR
load ranges. Host tests
exercise link admission/flush delay, tick wrap, DHCP retry scheduling, DMA
padding, descriptor rotation, RX ring wrap, malformed RX, and fail-closed TX
error/timeout behavior. These tests model registers and descriptors, not AXI
hardware or DHCP packets. RTL diagnostics/PHY benches test the read-only PCS
register and poll-failure invalidation/recovery.

JTAG bring-up on 2026-09-20 demonstrated FSBL/DDR initialization, R5 split-mode
startup, physical UART output, advancing RTOS/timestamp counters, both PS PHY
initializations, GEM1 link admission and reception of real Ethernet packets
through the fabric CPU port. A five-second JTAG sample measured 5024 ticks and
3925577 timestamp counts (5041 ms wall time, including read skew), consistent
with the configured rates; this is not precision clock calibration. The PL PHYs
were initialized but disconnected; SFP was absent.

GEM1 ILA debugging corrected the PS FIFO clock selection and a spurious
underrun on the read immediately after EOP. The R5 acquired DHCP address
`10.0.1.214`; five host pings succeeded with zero loss, and GEM1 reported four
successful TX frames and zero underruns before the ping test. See
[ILA captures and regression](../../docs/gem1-debug.md). Sequential cable moves to GEM0, PL1 and PL0 also passed ping at the same
address (15/15, 20/20 and 20/20 in the final samples). See the
[four-port results](../../docs/verification.md#four-copper-ports-passing-dhcp-address-ping-2026-09-20).
Lossless handover, minute-retry timing on the wire, lease renewal, and DMA
stress remain pending.
The JTAG session runs without PMU firmware (the FSBL reports this); full boot
packaging and power-management integration are still pending. PS PHY strap/SGMII and
RGMII delay assumptions require board confirmation. Existing SFP negotiation
simulation-scale timers and interoperability gaps remain; do not treat this
firmware as SFP hardware sign-off. The unacknowledged link-flush protocol still
needs stronger RTL completion semantics; the current guard assumes a running
125 MHz fabric. DMA automatic restart, cache-enabled throughput and production
entropy provisioning are later work.

Register references: [AMD GEM external FIFO register](https://docs.amd.com/r/en-US/ug1087-zynq-ultrascale-registers/external_fifo_interface-GEM-Register),
[AMD TTC driver](https://xilinx.github.io/embeddedsw.github.io/ttcps/doc/html/api/index.html),
and the generated BSP headers/configuration tables. The upstream kernel/TCP
sources in `third_party` define the RTOS port and network-interface contracts.

## SNMP

Read-only SNMPv2c on UDP 161 exposes all compiled-in counters and environmental
readings. Default lab community: `public`; example PEN: `32473`. Configure
`include/snmp.h`; see [SNMP documentation](../../docs/snmp.md) and the supplied
[MIB](../../docs/mibs/KR260-SWITCH-MIB.txt). `make test` exercises the BER engine
and MIB with all four statistics build combinations.

## Statistics and sensors

The standard firmware reads per-port packet/byte counters every 250 ms and
accumulates 64-bit totals. `STATS_DDR=1` and `STATS_DEBUG=1` enable the optional
DDR and debug collectors; use matching FPGA synthesis options. An ABI/options
mismatch disables collection with a UART diagnostic. A separate task samples
PS/PL SYSMON and the carrier's INA260 SOM power monitor every second.

See [statistics.md](../../docs/statistics.md) for the counter definitions,
register protocol, widths, ownership, snapshot API, build examples and
validation limits. The all-counter build was loaded through JTAG on 2026-09-21;
DHCP and full-MTU pings to the R5 and forwarded endpoint passed.

## Web management

The firmware serves `/configuration` and `/statistics` on HTTP port 80.
Viewing is public; configuration changes require administrator credentials
and persist on microSD. Statistics refresh every second. Four HTTP workers
with independent buffers serve parallel browser requests; USB-backed
configuration operations remain serialized.
See [web interface](../../docs/web-interface.md) for API, behavior, and tests.

GEM1 (right lower, RGMII) supports 10/100/1000 full duplex with selectable
PHY advertisement on the web page. GEM0 (right upper, PS SGMII) remains
1000-only due to the PS interface restriction. Both interfaces report
physical speed via HTTP and SNMP. PL0/PL1 also support selectable 10/100/1000
full duplex; see [PL speeds](../../docs/pl-ethernet-speeds.md). See [PS speeds](../../docs/ps-ethernet-speeds.md).

Startup timing and the confirmed HTTP connection-capacity limitation are
documented in [the investigation](../../docs/startup-and-http-investigation.md).

## CPU TX stream ABI

This firmware requires fabric 1.1 / management 1.2. Every CPU DMA transfer
includes a private two-byte header, constructed atomically with the frame.
Directed sends use `fabric_dma_send_directed()` rather than arming a register.
See [metadata contract and matching-image requirement](../../docs/cpu-tx-metadata.md).

The 2026-09-26 deployment uses `STATS_DDR=1 STATS_DEBUG=1`, includes the
pipelined CPU DDR writer, and passed DHCP, CPU/forwarded ping and HTTP tests.
See [deployment evidence](../../docs/verification.md#2026-09-26-cpu-tx-metadata-and-dma-pipeline-board-deployment).

The current board runs the 125 MHz build. `FABRIC_HZ` is exposed through HTTP
`fabric_hz` and SNMP `krFabricHz`; DDR/debug cycles are 8 ns. MAC aging remains
250 ms and the TTC timestamp stays at 781,250 Hz. See [125 MHz board validation](../../docs/verification.md#2026-09-26-125-mhz-fabric-board-deployment).

CPU DMA interrupt diagnostics can be read while R5 runs with
`xsdb software/r5/dma_status_jtag.tcl tcp:10.0.1.109:3121`. The script uses
the current ELF to locate non-cacheable IRQ, completion, drop and timeout
counters; use the ELF actually deployed. DMA errors wake both packet tasks
and fail closed without restarting hardware or reusing outstanding buffers.

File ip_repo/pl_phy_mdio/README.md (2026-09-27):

# PL PHY MDIO management

`ghlhub.org:ethernet:pl_phy_mdio:1.1` packages one independent PHY-management
bus. The public top is `switch_pl_phy_mdio`; `manifest.json` owns its source
closure. It includes the real IOBUF, Clause 22 master, register shim and
DP83867 startup/link-polling sequencer.

Connect `s_axi`, `clk` and `rst_n` to the same control domain. Connect
`phy_reset_released_i` to the board's PHY-reset-release request; the IP owns
the two-stage crossing into `clk`. Keep `mdio_io` bidirectional through the
board top and route `mdc_o` to its PHY. Board pin assignments and external
MDIO timing budgets belong to the board constraint set. The package does
not generate RGMII clocks or drive the PHY reset pin.

KR260 uses one instance per PL port, at PHY addresses 2 and 3. Default
startup and polling counts assume the existing 142.857 MHz control clock;
review these parameters and the software-programmed MDC divider when
reusing the block at another frequency. The initializer specifically
configures the DP83867; it is not a generic PHY initialization sequence.

Version 1.1 adds poll hold at `0x18` and resolved link status at STATUS bit 10.
Software pauses polls, waits for idle, performs its transactions, and resumes
polling on both success and failure. This supports R5 full-duplex capability
selection without racing the hardware poller.

See the [interface contract](../INTERFACES.md#pl-phy-management-pl_phy_mdio-11)
and [MDIO register map](../../docs/board-integration.md#mdio-management-interface).

Run the actual public-wrapper tests with:

```sh
python3 scripts/check_ip_tests.py --core pl_phy_mdio
python3 scripts/check_ip_tests.py --core pl_phy_mdio --catalog build/ip_catalog
```

Only the pad primitive is modeled for simulation. The controller and
sequencer under test are the same source files packaged for synthesis.

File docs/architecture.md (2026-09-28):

# Overall architecture

The latest source adds [STP/RSTP and safe port-state integration](spanning-tree.md),
superseding the historical partial-STP description below. It requires a new
fabric/management 2.1 bitstream and is not yet deployed.

The digital modules now have [IP repository boundaries](ip-partitioning.md)
with an extracted `switch_fabric`, local GEM counters and reproducible
Vivado packaging. The diagram below shows the board-level packet flow;
`switch_top` is the compatibility wiring assembly around these blocks.

Production assembly updated: 2026-09-26. The design is a store-and-forward switch
using a shared PS DDR packet pool. PS GEM traffic enters PL through the GEM
external FIFO interface, bypassing the GEM's built-in DMA. The switch's own
PL DMA engines then store packets in DDR.

The source now also includes a [low-priority MAC-table dump DMA](mac-table-dump.md)
inside fabric 1.2. It reads table port A in 16-entry chunks and writes 256-byte
bursts to host DDR through HP0. Its CPU control slave is at 0x80110000. This
addition is deployed with the public manual-refresh web view. The current
125 MHz image includes full-duplex PL 10/100/1000 operation;
see [deployment results](verification.md#2026-09-26-pl-101001000-implementation-validation).

## System view

The board assembly and generated block design now connect the port hardware,
switch, and PS memory interfaces. The nine catalog cells are inside
`system.bd`; physical shells remain outside. A connection means wiring exists,
not that every operating condition has been verified on hardware. Remaining
packaging and verification work is listed in [partitioning](ip-partitioning.md).

```mermaid
flowchart TB
    subgraph board[kr260_top — board assembly]
        subgraph shell[kr260_pl_top — physical shell]
            RGMII[Two multirate RGMII adapters and RX FIFOs]
            GT[GTH, SFP sideband and status]
            CLOCK[PL and SFP clocks, GEM reset synchronizers]
        end
        subgraph bd[system.bd — production IP Integrator assembly]
            PS[Zynq PS: GEM0, GEM1, R5 and DDR]
            GEM[gem_port ×2]
            PL[pl_port ×2]
            MDIO[pl_phy_mdio ×2: MDIO, PHY initialization and polling]
            SFP[sfp_port: 1000BASE-X MAC and PCS]
            FAB[switch_fabric: forwarding, buffer manager,<br/>ingress/egress DMA, CPU virtual port and MAC dump]
            MGMT[management 1.2: registers, snapshot mailbox and bank decoder]
            CTL[Control SmartConnect]
            HP0[DDR SmartConnect → PS HP0]
            DMA[CPU AXI DMA]
            HP1[DMA SmartConnect → PS HP1]
            IIC[SFP I2C and interrupt aggregation]
            PS <-->|GEM external FIFOs| GEM
            GEM <-->|16-bit AXI-S| FAB
            PL <-->|16-bit AXI-S| FAB
            SFP <-->|16-bit AXI-S| FAB
            FAB <-->|Four 128-bit AXI masters| HP0
            HP0 <--> PS
            FAB <-->|16-bit CPU streams| DMA
            DMA <--> HP1
            HP1 <--> PS
            PS --> CTL
            CTL -->|MAC dump commands| FAB
            CTL --> MGMT
            CTL --> PL
            CTL --> SFP
            CTL --> DMA
            CTL --> IIC
            MGMT <--> GEM
            MGMT <--> PL
            MGMT <--> SFP
            MGMT <--> FAB
            MGMT <-->|Link, forwarding and CPU controls| FAB
        end
        RGMII <-->|GMII| PL
        GT <-->|16-bit decoded data and K flags| SFP
        GT <--> MGMT
        RGMII -. diagnostics .-> MGMT
        CTL --> MDIO
        MDIO -. link events .-> MGMT
        CLOCK -. clocks and resets .-> bd
    end
    PHY[Two PL copper PHYs] <--> RGMII
    PHY <--> MDIO
    CAGE[SFP cage] <--> GT
    CAGE <--> IIC
    RTOS[R5 FreeRTOS: network stack, SNMP, web and USB storage] -.-> PS
```

The preceding native assembly passed board DHCP, CPU ping, settled endpoint
forwarding, SNMP/web and SD-storage checks. The production catalog assembly
has separate build and simulation evidence in [verification](verification.md)
and has passed JTAG deployment and settled GEM1/PL0 connectivity checks.
Complete external timing, CDC sign-off and
all-port concurrent traffic qualification remain pending.

## Physical-port boundaries

| Index | Port | Digital-switch boundary and board connection |
| --- | --- | --- |
| 0–1 | PS GEM0 / GEM1 | External FIFO signals, separate RX/TX clocks and synchronized resets per GEM; connected to PS FIFO ports by the block design and static top |
| 2–3 | PL GMII0 / GMII1 | Paced GMII to two 10/100/1000 RGMII adapters; each has a local 125 MHz MAC clock, PHY RX clock, MDIO controller and reset request |
| 4 | SFP 1G | Decoded 16-bit GTH interface; board wrapper joins the transceiver and a new 125/62.5 MHz PCS clock generator |
| 5 | Virtual CPU | 16-bit AXI-S pair connected to vendor AXI DMA MM2S/S2MM |

`switch_fabric` exposes four AXI masters: physical ingress writes,
physical egress reads, the combined CPU pool write/read interface, and the
low-priority MAC-table dump writer.
They connect directly to `sc_ddr` inside the block design.
The separate CPU-facing AXI DMA has three memory masters through `sc_dma`.
Both paths reach PS DDR, through HP0 and HP1 respectively.

The control interconnect has nine targets: three MACs, two MDIO controllers,
CPU DMA, SFP IIC, diagnostics and MAC-table dump control. Eight MAC/DMA interrupts use PS IRQ0;
IIC uses IRQ1 bit 0; link events use IRQ1 bit 1. `default_age_i` remains tied to its package default.
SFP sync/negotiation status drives LEDs; sideband status and laser force-off/
fault-lockout controls are CPU-accessible. See the [register map](board-integration.md).

Each MDIO controller runs an automatic DP83867 initialization sequence after
PHY reset release. The RGMII RX data/control pins have 700 ps (PL0) and 750 ps (PL1)
IDELAYE3 delays;
the 300 MHz clock outputs now supply active delay calibration. PHY internal
RX/TX delays are configured for 2.00/1.75 ns. The optional FPGA RX-clock delay
remains disabled because its IDELAYE3-to-BUFG path cannot be implemented.

`rgmii_rate_adapter` reconstructs received bytes at all three copper rates
and transfers valid bytes plus explicit frame-end/error tokens through a
2048-entry FIFO36E2. Independent receive/transmit byte strobes keep the MAC
and fabric clocks at 125 MHz. The legacy matched-rate elastic module remains
for its older tests; production no longer uses it. Overflow reaches the
sticky diagnostic; empty between received bytes is normal, so underrun is
held zero. See [PL speed control and verification](pl-ethernet-speeds.md).

`async_fifo` now selects XPM in synthesis and the portable Gray-pointer model
otherwise. Their reset/capacity details differ. The MAC now synchronizes resets
per domain and publishes data read pointers one word per clock. See
[CDC review](cdc-review.md) for assumptions and remaining verification.

The SFP uses 1000BASE-X at 1.25 Gb/s serial rate. Its 125 MHz codec and
62.5 MHz gearbox clocks now come from one MMCM driven by GTH TXUSRCLK2.
The gearbox now transfers complete words across these related clocks and
passes four-phase simulation. GTH startup is verified; receive clock correction
and hardware packet operation are under [investigation](sfp-debug.md). This is not a 10G datapath.

Experimental Clause 37 negotiation overrides transmitted MAC symbols and
exports link/duplex/pause/fault status. It does not gate frame admission;
frames accepted during negotiation/restart can be lost or truncated. The board
overrides short simulation timers with 10 ms restart and 10 ms acknowledge/idle
intervals; compatibility, fault, idle stability and pause rules remain incomplete. Two-PCS tests share clocks and the same RTL; they
do not establish independent-peer interoperability. See the
[development backlog](inventory.md#modules-and-integration-still-pending).

## Packet lifetime

1. A port adapter supplies a frame to `ingress_port_wr` over 16-bit AXI-S.
   The frame is collected in local RAM. An error on the final transfer drops
   it before allocation. Only one frame is in flight per front end.
2. The front end allocates a buffer ID from `buf_mgr_core`. The appropriate
   write DMA copies the frame into `DDR_BASE_ADDR + bufid * BUFFER_BYTES`.
3. In parallel with frame reception, each `mac_addr_resolver` snoops accepted
   words to capture destination/source MACs and request lookup/learning. A hit
   returns the learned mask with the ingress port removed; a same-port-only
   hit drops the frame rather than flooding. A miss floods all other ports
   (including CPU for physical ingress).
   `mac_forwarding_top` supplies `dest_mask_i` / `dest_mask_valid_i`; ingress
   waits for a valid decision before enqueue. Learning currently precedes
   final frame validation; see the [resolver gaps](inventory.md#known-gaps-in-existing-rtl).
4. `queue_mgr` masks the forwarding decision with the CPU-maintained link-up
   bits, then records the length and links the buffer ID into each selected
   destination queue. `free_list_mgr` tracks the number of destinations. A
   zero mask frees the allocation without forwarding.
5. Each egress front end dequeues a buffer ID and uses its read DMA to copy
   the frame into local RAM. It releases its reference to the DDR slot once
   that copy completes, then streams the local copy to its MAC or CPU endpoint.
6. The shared DDR allocation returns to the free list after the final
   destination releases it. Multicast therefore shares one stored payload,
   with a separate read and local copy for each destination.

The CPU port uses the same front ends and buffer manager, but dedicated
`cpu_dma_wr` / `cpu_dma_rd` engines. The block design instantiates a separate AXI DMA
SG block to move data between FreeRTOS-owned buffers and this port's streams.
MM2S/S2MM completion and error interrupts (GIC 127/128) wake the sending
task and RX service respectively; packet completion is not periodically polled.
The current CPU design therefore copies between software buffers and the
switch pool; it is not a direct zero-copy software interface to pool buffers.

## Current interface contract

| Interface | Current RTL contract |
| --- | --- |
| Switch packet streams | 16-bit `TDATA`, two-bit `TKEEP`, `TVALID`, `TREADY`, `TLAST`; low byte first |
| Partial final word | `TKEEP=01`; otherwise `TKEEP=11`. Sparse/empty keep patterns are not supported by the front ends. |
| Ingress error | `TUSER` sampled on the accepted final transfer; PL MAC adapters currently tie it low because the MAC filters bad frames. |
| Frame content | Ethernet header and payload; FCS excluded from switch streams. PS GEM receive configuration must match this convention. |
| Physical DDR access | One shared 128-bit write engine and one shared 128-bit read engine, each arbitrating five ports and allowing one outstanding frame burst |
| CPU switch-pool access | Dedicated 128-bit write/read engines; same pool geometry as physical ports |
| Port mask | Six bits in the buffer manager; eight bits in MAC-table results. `mac_forwarding_top` uses bits 0–5 and disables request ports 6–7. |

The GEM RX bridge packs bytes before crossing into the fabric; TX unpacks
after crossing into the GEM clock domain. TX starts after 128 words or the
frame's final word is buffered. Both PL/SFP adapters now transfer one 16-bit
word per cycle, with 256-word (512-byte payload) FIFOs. The physical ingress
DMA now sustains one 128-bit beat per cycle after pipeline fill when AXI
is ready. Two buffered words with reserved space for each pending RAM read
keep data stable during backpressure. CPU ingress remains three cycles per
beat. Egress
prefetches the next RAM beat to stream without the former beat-boundary gaps.

## Port state and link-down handling

`rx_diag_regs` resets the six-bit link mask to CPU-only (`0x20`): **all physical
ports are excluded as enqueue destinations until software marks them up**.
MDIO polls report physical link, speed and duplex; SFP sources report changes.
These events raise a maskable interrupt but do not automatically modify the
software link mask. Firmware must evaluate status and use LINK_SET/LINK_CLR.

`port_link_ctrl` synchronizes levels/toggles into the fabric and delays each
flush pulse four cycles. `queue_mgr` masks new destinations and drains queued
references through the free-list arbiter. The MAC-table sweep removes the
port's bits and expires entries whose masks become empty. Already-dequeued
frames and MAC/GEM FIFO contents are not aborted; ingress and learning are
not disabled by this output mask. Busy is status, not a command acknowledgement.
Rapid repeated toggles, link-up before flush completes, ongoing learning and
in-flight traffic need further testing. The register map is in
[board integration](board-integration.md#link-control-and-events).

### Control-protocol hooks (STP/LACP/LLDP) and the STP implementation

The hardware traps and gates traffic needed to run STP (and, generically,
any other IEEE 802.1D "Slow Protocol" that addresses frames to the reserved
Bridge Group block) as protocol-agnostic primitives — none of the hardware
described in this subsection parses a BPDU, elects a root, or runs a timer.
As of 2026-09-23 those primitives ARE used by a real classic (802.1D-1998,
not RSTP/MSTP) STP implementation in firmware (`software/r5/src/stp.c` +
`stp_task.c`), described in its own subsection below. LACP and LLDP remain
unimplemented; the same hooks are available for a future task to use the
same way.

**Reserved address trap.** Each per-port `mac_addr_resolver` instance
(inside `mac_forwarding_top`) compares every frame's destination MAC
against the fixed 44-bit prefix `01:80:C2:00:00:0x` (IEEE 802.1D's
Bridge Group Address block, covering STP/RSTP/MSTP, LACP/OAM Slow
Protocols, LLDP nearest-bridge and others in one compare). A match forces
`dest_mask` to the CPU port only, regardless of the MAC table, and asserts
a per-port `ctrl_frame_o`. This trap is unconditional — not gated by
`fwd_en_i`/`learn_en_i` below, and not software-disableable — since the
reserved range has no legitimate reason to ever be flooded or forwarded to
another port.

**`fwd_en_i` / `learn_en_i` (per physical port, `mac_forwarding_top` /
`switch_top`).** These add the two 802.1D port-state gates the existing
`link_up_i`/link-flush mechanism above does not provide:

- `fwd_en_i[n]=0` makes port `n`'s resolver return an empty `dest_mask` for
  ordinary traffic (nothing is relayed from or to that port), independent
  of physical link state.
- `learn_en_i[n]=0` suppresses `learn_req_o` for that port (source MACs
  are not entered into the table), also independent of link state.
- Both gates are bypassed for control-block frames — a "blocking" port
  under `fwd_en_i=0` still delivers its BPDUs/LACPDUs/LLDPDUs to the CPU,
  which is required for STP to ever transition a blocked port back to
  forwarding.

Firmware controls these through four new `rx_diag_regs` write-1-to-set /
write-1-to-clear registers (`FWD_SET`/`FWD_CLR`/`LEARN_SET`/`LEARN_CLR` at
offsets `0x38`/`0x3C`/`0x40`/`0x44`) and reads combined status back from
`PORT_CTRL_STATUS` (`0x48`). Both default to all-ports-enabled out of
reset, so the system behaves exactly as before this feature on any
firmware that never touches these registers. The bits cross into the
fabric clock domain through a plain double-flop synchronizer (level
signals, not pulsed), matching this design's existing CDC conventions —
see [cdc-review](cdc-review.md).

**CPU TX destination metadata (`switch_fabric` 1.1).** Every CPU MM2S
frame now carries a private two-byte header identifying ordinary forwarding
or a software-selected physical destination mask. `cpu_tx_framer` strips the
header before Ethernet parsing, statistics and DDR storage, and holds its mask
until enqueue completes. The next header is backpressured until then. This
replaces the separate CSR arm and metadata CDC; no legacy transmit mode is
supported. Management 1.2 exposes the ABI identifier checked by firmware.
See [CPU TX metadata](cpu-tx-metadata.md) for the format and reset contract.
This revision was rebuilt and deployed with matching firmware on 2026-09-26;
see [board verification](verification.md#2026-09-26-cpu-tx-metadata-and-dma-pipeline-board-deployment).

**Firmware plumbing (`software/r5/src/pstate.c`, `pstate.h`).** Thin
register-access wrappers only — `pstate_fwd_set/clear`,
`pstate_learn_set/clear`, `pstate_get`, and `pstate_cpu_tx_raw` (calls
`fabric_dma_send_directed`, with header and payload under one TX mutex). `network.c`'s RX
loop pre-filters frames addressed to the reserved block before they reach
`eConsiderFrameForProcessing` (which would otherwise silently discard
them, since they don't match the board's own MAC or IP/ARP EtherTypes) and
hands them to a weak, default-no-op hook, `fabric_ctrl_frame_rx` — now
overridden by `stp_task.c` (see below); LACP/LLDP remain unimplemented and
would need their own override of the same weak hook.

**CPU RX ingress-port tag.** The one hardware gap STP genuinely needed:
the CPU's inbound frame path (`buf_mgr_core`/`queue_mgr` → `egress_top` →
the shared CPU AXI DMA) had no way to tell software which of the 5
physical ports a delivered frame actually arrived on — all of them funnel
into one shared CPU RX queue. `buf_mgr_pkg`'s per-buffer metadata (already
carrying `length` end-to-end) now also carries a 3-bit ingress-port tag,
set to each physical port's own fixed `PORT_ID` at enqueue time
(`ingress_top.sv`) and read back at CPU dequeue time. `switch_top.sv`
pushes it into a small `async_fifo` (`clk` → `axis_clk`, depth 16, one
entry per frame handed to the CPU, in delivery order) that
`rx_diag_regs`'s new `CPU_RX_TAG` register (`0x50`) pops on every read.
`fabric_dma.c` reads this register exactly once per RX descriptor it
retires (well-formed or not) to stay in lockstep, and exposes it as
`fabric_dma_last_rx_tag()`. This is a generically useful hook (works for
any CPU-delivered frame, not just trapped control-block ones), not
STP-specific.

#### STP implementation (firmware, 2026-09-23)

`software/r5/src/stp.c`/`include/stp.h` implement the classic 802.1D-1998
Spanning Tree Protocol: Config/TCN BPDU encode-decode, the fixed-
configuration root/designated/blocking election (comparing
{root ID, root path cost, sender bridge ID, sender port ID} tuples), and
the Blocking → Listening → Learning → Forwarding progression driven by the
four standard timers (Hello 2s, Max Age 20s, Forward Delay 15s, inherited
from the root once one is known). It has no `board.h`/FreeRTOS dependency
— host-testable like `policy.c`. A three-bridge triangle regression
(`tests/test_stp.c`) elects one root and blocks one port in that topology;
this does not establish general protocol conformance. A deliberate
simplification: TCN BPDUs are counted but not propagated (no network-wide
fast-aging on topology change) — see `stp.h`'s header for why.

`stp_task.c` is the hardware glue: a 1 Hz FreeRTOS task that polls
`board_ports_get()`/`board_ports_snapshot()` for per-port admission and
speed (mapped to 802.1D path cost: 4/19/100 for 1000/100/10 Mb/s), drives
`FWD_EN`/`LEARN_EN` through `pstate.c` from each recompute's desired mask
(diffed against the last-applied mask, so an unchanged port is never
re-written — `FWD_CLR`/`LEARN_CLR` also flush the port, so a spurious
repeated write would flush it every second and prevent MAC learning from
ever settling), and transmits BPDUs via `pstate_cpu_tx_raw`. It supplies
the strong override of `fabric_ctrl_frame_rx`, reads the frame's ingress
port via `fabric_dma_last_rx_tag()`, and feeds it to `stp_rx_bpdu()`. Live
status (bridge/root IDs, root path cost, and per-port role/state/BPDU
counters) is exposed through `/api/statistics`'s new `"stp"` JSON object
and rendered on the web statistics page — the way to visually confirm STP
is running and converged on real hardware.

**Defaults disabled (2026-09-23).** `stp_task.c`'s `stp_enabled` static
starts `false` and there is currently no web control or persistent
configuration to change it (both explicitly future work) — the only way
to turn it on today is editing that initializer and rebuilding. While
disabled the task touches no hardware at all (no `FWD_EN`/`LEARN_EN`
writes, no BPDU transmit/receive processing), ordinary forwarding remains enabled, while reserved control frames
are still trapped to the CPU and discarded; `stp_get_enabled()`/
`stp_set_enabled()` exist as the entry point the pending web control will
call, restoring all-enabled hardware state on disable and reinitializing
the engine fresh on enable. A real bug was found exercising this feature
against a genuine STP-speaking neighbor switch and is worth knowing about
if extending `stp_task.c` further: `fabric_dma_send()` needed a mutex once
a second CPU-TX caller (BPDU transmission) existed alongside the IP
stack's own output path — see [verification](verification.md)'s
"real bug: CPU TX race" entry.

The separate TX-override serialization/CDC path is removed by the new stream
ABI. Shared STP task-state and CPU RX tag risks remain recorded in [verification](verification.md#2026-09-23-check-in-review-remaining-stp-limitations).

## Switch-fabric bandwidth limitations and areas to investigate

Status: updated 2026-09-26 for the pipelined physical and CPU ingress write
engines (one beat per cycle after fill). Fabric clock is 125 MHz, and per-port stream
stages transfer one word per cycle. **The DDR throughput estimates below are analytical, not measured system
performance.** A single-port MAC loopback bench measures frame integrity and
GMII gaps; no bench exercises sustained traffic on several ports through a
realistic shared-memory model. The previous 100 MHz estimates based on an
assumed fixed 30-cycle memory latency are retired: DDR and interconnect delays
must be remeasured at 125 MHz rather than presumed to shrink with the clock.

### Raw capacity (128-bit AXI, 125 MHz fabric)

| Path | Data-phase ceiling | Notes |
| --- | --- | --- |
| HP0 port, per direction | 16 Gbit/s (2 GB/s) | Shared by ingress writes, egress reads and the CPU-port master; DDR is also shared with the PS |
| Ingress write master | 16 Gbit/s (2 GB/s) | 1 cycle per 16-byte beat after pipeline fill, with AXI ready; one burst outstanding |
| Egress read master | 16 Gbit/s | 1 beat per cycle; one burst outstanding |
| Per-port egress stream out of `egress_port_rd` | 2 Gbit/s | One word per cycle; the next 128-bit beat is prefetched while the current one drains (it was 8 words per 10 cycles) |
| PL/SFP port adapters, each direction | 2 Gbit/s | Word-wide FIFOs (`switch_egress_to_mac_txd.sv`, `mac_rxd_to_switch_ingress.sv`): one 16-bit word per fabric cycle on the fabric side and per MAC-clock cycle on the MAC side (2.3 Gbit/s). This replaced a byte-serial version that limited each port to 0.8 Gbit/s (0.5 Gbit/s at 62.5 MHz). |
| CPU-port AXI DMA (32-bit) | 4 Gbit/s | Separate HP1 path |
| `cpu_dma_wr.sv` | 16 Gbit/s | Two-word read pipeline; 1 cycle per 16-byte beat after fill, with AXI ready; one burst outstanding. Simulation verified and board deployed 2026-09-26 |
| Aggregate offered load | 5 Gbit/s | 5 physical ports at 1 Gbit/s; flooded frames multiply the egress side |

### Ingress limitations

0. **(Fixed) byte-serial MAC receive adapter**: `mac_rxd_to_switch_ingress.sv` used to
   move one byte per cycle (0.8 Gbit/s per port at 100 MHz, 0.5 at 62.5 MHz) and could
   not sustain the wire rate. It is now word-wide, and `tb_mac_adapters.sv` checks one
   word per fabric cycle. The MAC's data path itself is 32 bits at 142.86 MHz.
1. **Store-and-forward, one frame in flight per port** (`ingress_port_wr.sv`):
   `s_axis_tready` is low from the end of a frame until its DMA and enqueue finish.
   The adapter FIFO (`mac_rxd_to_switch_ingress.sv`) holds 256 16-bit words
   (512 payload bytes, about 4.1 us at 1 Gb/s), in addition to the MAC
   packet/descriptor storage. A minimum-size frame is 0.67 us on the wire, and the port's turnaround
   (buffer allocation, waiting for the shared write master, the burst, the write
   response, the enqueue) is likely several us when other ports are also waiting,
   so back-to-back small frames or a busy master can exhaust the available
   receive buffering. The adapter honors full by deasserting MAC-stream ready;
   validate the MAC's whole-frame drop behavior once its own storage fills.
2. **One shared write master** serves all five ports and holds the bus for a whole
   frame burst; other ports wait. One burst outstanding means every frame pays the
   write-response latency.
3. **Beat cadence (improved)**: the physical ingress engine now transfers one
   beat per cycle after filling its two-word buffer, rather than alternating
   RAM read and AXI write cycles. For 1,500 bytes (94 beats), the no-stall
   simulation measures 96 cycles from AW acceptance to the final W handshake,
   versus 188 before. This excludes address waiting, response latency and
   frame arbitration/enqueue overhead. Small-frame throughput remains sensitive
   to these fixed costs; sustained multiport bandwidth remains unmeasured.
4. **Buffer pool**: `NUM_BUFFERS = 256` buffers of 2 KiB (512 KiB). The buffer test verifies all 256 slots can be allocated after flush/release
   races. Sustained traffic through pool exhaustion and recovery remains untested.
5. **Serialized control plane**: `queue_mgr` and `free_list_mgr` each process one
   operation at a time (enqueue, dequeue, flush, alloc, release). My estimate is
   about 8 cycles for a unicast enqueue plus about 3 per extra flood destination.
   At small-frame line rate with flooding this may not keep up; unmeasured.
6. **MAC table**: one lookup engine, one learn engine; a link-down flush sweeps all
   four banks (about 2,950 cycles) and an aging tick arriving meanwhile is skipped.

### Egress limitations

0. **(Fixed) byte-serial MAC transmit adapter** (`switch_egress_to_mac_txd.sv`) and
   two idle cycles between 128-bit beats in `egress_port_rd.sv`: both are gone. The
   adapter is word-wide and the port streams one word per cycle with the next beat
   prefetched (`tb_egress_top.sv` case C and `tb_mac_adapters.sv` check the rate).
   `tb_pl_mac_linerate.sv` runs the real MAC in GMII loopback with back-to-back
   frames at wire rate (12 x 1518 B, 24 x 64 B, 60 x 100 B): every frame arrives
   intact and the gap between frames on the GMII pins stays at 14 clocks or less
   (the MAC's own inter-frame gap is 12).
1. **Store-and-forward, one frame per port** (`egress_port_rd.sv`): the next
   frame is not fetched until the current one has been streamed out.
2. **Transmit buffering** (PL and SFP ports): the fabric stream goes through the
   256-word (512-byte payload) FIFO in `switch_egress_to_mac_txd.sv` and into the MAC's own
   4 KiB transmit buffer (1024 x 32-bit, up to 8 frame descriptors), and the MAC
   starts a frame on the wire only once the whole frame has been committed (TLAST).
   So the MAC's buffer decouples the wire from the fetch: the next frame can be
   fetched and streamed while the current one is on the wire, as long as the buffer
   has room for it (about two maximum-size frames). PS GEM ports have only the
   512-byte bridge FIFO (`axis_to_gem_tx_r.sv`) with its start-permit scheme.
   (An earlier version of these notes predicted a gap between back-to-back large
   frames from the 128-byte FIFO alone; that ignored the MAC's buffer and is
   withdrawn.)
3. **One shared read master, one burst outstanding**: each frame pays the full read
   latency. The idealized frame rate is fabric frequency divided by the sum
   of data beats, memory latency cycles and state overhead. Small frames remain
   especially sensitive to memory latency and flooding; sustainable throughput
   at 125 MHz must be measured.
5. **Shared HP0**: ingress, egress and the CPU-port master contend for one HP port
   and for DDR with the rest of the PS.

### Areas for investigation and improvement, roughly by expected value

1. **Measure first.** Add an AXI memory model with realistic read/write latency to
   the integration benches; run sustained five-port line-rate traffic (large, small
   and mixed sizes, with floods); add hardware counters (ingress FIFO overrun,
   no-buffer stalls, per-port frames and bytes, master busy cycles) readable over
   AXI-Lite; capture with an ILA on the AXI masters.
2. **Ingress buffering**: double-buffer the port frame RAM and/or deepen the MAC-side
   RX FIFO so a port can receive while the previous frame drains; define and test
   overflow behaviour (clean drop plus a counter).
3. **Ingress write engine**: physical-port beat pipelining is implemented and
   simulation-tested. Allowing several bursts in flight to hide response latency
   remains future work and requires updating the statistics monitor
   single-outstanding contract. The CPU write engine uses the same two-word pipeline.
4. **Egress read engine**: allow several outstanding reads and overlap the next
   frame's fetch with the current stream (double-buffered frame RAM or a larger
   transmit FIFO). Beat-boundary prefetch is already implemented.
5. **Control plane**: pipeline `queue_mgr` and `free_list_mgr` or split enqueue and
   dequeue engines if the counters show them saturating; check flood cost.
6. **Memory system**: consider a second HP port for egress (HP0 is shared by four
   masters), larger bursts across frames, cache/DDR-controller QoS settings, and the
   pool location relative to other PS traffic.
7. **Clock**: the source fabric target is now 125 MHz. Review per-domain timing and
   resource use before any further increase; global routed slack is dominated
   by other paths and does not establish performance headroom.

8. **High-speed SFP trunk:** widen the SFP packet interface to **128 bits**,
   including byte enables and packet boundaries, for the eventual
   1/2.5/5/10 Gb/s trunk. The current 16-bit interface has only 2 Gb/s raw
   capacity at 125 MHz; 128 bits provides 16 Gb/s before overhead. This requires
   adapting the SFP ingress/egress buffering, parser and DDR transfer boundaries,
   plus revisiting statistics widths for higher byte rates. Higher-rate MAC/PCS,
   transceiver configuration and module interoperability are separate future work.

### Bug found while building the wire-rate test

`open_eth_mac_1g_switch.sv` (the MAC fork) computed "descriptor ring full" as
`(wr_bin - rd_bin) == DEPTH` for both the transmit ring (depth 8) and the receive
ring (depth 16). That expression is evaluated in 32 bits, so once the write pointer
had wrapped past the read pointer the difference went negative and "full" was never
detected: an unsent transmit descriptor could be overwritten (frames on the wire
carried a later frame's data). It only appears with the ring nearly full after
16 descriptors, i.e. sustained bursts of small frames. Both compares now use the
pointer width. The frames-at-wire-rate bench exposes it and passes after the fix.

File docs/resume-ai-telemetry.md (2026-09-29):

# Resume point: A53 Linux and AI traffic telemetry

Saved after the minimal Linux boot and Telnet console fix. No telemetry hardware
or Linux DMA driver has been implemented yet. The user requested this handoff
note; the next implementation step was recommended but has not yet been started.

## Intended direction

Monitor switch traffic with FPGA header parsing and flow statistics, then use
inference/anomaly detection to identify interesting conversations and trigger
selective captures. A53 software performs correlation, baseline/model updates,
and postprocessing. Keep monitoring off the forwarding critical path: a full
telemetry queue or stopped Linux reader must never stall normal forwarding.

The K26 has four A53 cores and two R5 cores. The selected architecture is Linux
on the A53 cluster alongside the existing R5-0 FreeRTOS switch application.
Inference applies a model; learning/model updates are a separate activity.
Start with flow features and a software baseline before selecting a PL model.

## Completed and checked in

- Main repository: `/raid/work/kr260-smart-network-auditor`.
  Commit `a6b7f26`: minimal A53 Linux JTAG boot alongside R5 switch firmware.
- Bridge repository: `/raid/work/uart_telnet_bridge`.
  Commit `638c1fb`: stateful Telnet input decoding and carriage-return fix.
- These two commits were **not pushed**. The main worktree was clean after
  committing; this handoff note is a subsequent documentation change.
- The bridge repository has unrelated untracked `node_modules/`, `package.json`,
  `package-lock.json`, and `__pycache__/`; do not include or delete them as part
  of this work.

See [Linux boot instructions and qualification](../software/linux/README.md)
and [memory ownership](memory-map.md) for authoritative details.

## Last verified hardware state

- Linux 6.18.10 booted on all four A53 cores, with a static BusyBox RAM filesystem.
- R5-0 continues running FreeRTOS; R5-1 remains reset.
- Existing dual-rate SFP FPGA image is retained. SFP host link reported 10G;
  the attached unmanaged switch has a 2.5G-capable port. Cable-side negotiated
  speed has not been independently measured.
- Volatile JTAG boot only; QSPI and microSD contents were not changed.
- UART console: `telnet 10.0.1.109 2323`, then Enter for `~ #`.
  No login is required. Ctrl+] then `quit` disconnects the Telnet client.
- Linux has no network interface or SSH yet. R5 management is `10.0.1.104`.
- Hardware server: `tcp:10.0.1.109:3121`.
- The Windows-hosted UART bridge serves one client: a new connection disconnects
  the existing console client. Warn before reconnecting during user interaction.
- The bridge previously passed Telnet `CR NUL` through to BusyBox, causing `?`
  before the next command. The fix handles `CR NUL`, `CR LF`, and fragmented
  negotiation. All ten bridge tests passed. The user restarted the bridge in
  Windows Terminal and confirmed it works. No workaround is now needed.

This describes the last observed state; check board liveness before assuming
that the volatile image survived a later reset or power cycle.

## Ownership and boot constraints

- Linux currently sees only low 2 GiB DDR. Its device tree reserves, with
  `no-map`, the PL packet pool `0x10000000–0x1007FFFF` and the entire R5 region
  `0x20000000–0x21FFFFFF`.
- R5 owns switch management, GEM0/GEM1, PL MAC/control/DMA, USB0 storage,
  I2C1/sensors, and TTC0/TTC1. Linux owns UART1 in the coexistence build.
- R5 build must use `LINUX_CONSOLE=1 STATS_DDR=1 STATS_DEBUG=1` with the currently
  deployed dual-rate bitstream. Incorrect statistics flags disable collection.
  `LINUX_CONSOLE=0` restores standalone UART ownership.
- The minimal Linux DT omits R5-owned peripherals and Linux PS power management.
  FSBL establishes clocks, which remain running. Do not substitute a stock board
  DT or enable clock/power management without reviewing ownership.
- No Linux remoteproc/RPMsg, telemetry driver, coherent DMA, persistent rootfs,
  or suspend support has been added.
- Current packet DMA uses noncoherent HP0 (fabric) and HP1 (R5 CPU-port DMA).
  R5 DMA buffers retain their existing noncacheable policy.

## Build and evidence locations

- Checked-in boot/staging sources: `software/linux/`.
- Checked-in R5 build/console changes: `software/r5/Makefile`, `src/console.c`.
- Generated payloads and evidence: ignored `build/linux/`, including
  `manifest.json`, `boot-final.log`, `uart-final.log`, `linux-final-check.log`,
  `live-results.json`, statistics snapshots, and ping logs.
- BusyBox source/build: `/tmp/kr260-linux-boot/busybox-1.37.0`.
- External kernel/TF-A/PMU artifacts: local AMD EDF 2026.1 deploy directory
  `/tmp/kv260-yocto-2026.1/tmp/deploy/images/`. Source revisions and exact input
  paths are documented in the Linux README. Temporary inputs may need rebuilding
  if cleaned; the scripts do not build the full EDF kernel/firmware themselves.
- Use the switch's own FSBL and PS initialization, not KV260 board boot files.
- Bitstream:
  `build/ip_refactor/sfpdual_release3/project/kr260_switch.runs/impl_dual_timing2/kr260_top.bit`.
- Tools: `/tools/Xilinx/2026.1/`. XSDB is available; the older XSCT entry point
  is disabled in this release. JTAG Linux transfers took several minutes.

## Verification already completed

- Both R5 console configurations built; existing R5 regression suite passed.
- Boot checker validated hashes, ELF load extents and PL/R5 reservations, and
  rejected corrupted hashes, undersized reservations, and a standalone-console
  R5 ELF.
- Linux reported CPUs `0-3`; `/proc/iomem` confirmed both reservations.
- Four CPU-pinned processes hashed a 128 MiB RAM file five times each: 20/20
  matched the host-computed hash. Linux interrupt error count was zero.
- During that load, all 16 R5 statistics HTTP requests succeeded; statistics
  advanced with no read/release/response timeouts. Sensors reported no errors.
- Full-size concurrent pings: R5 `.104` 200/200; SFP endpoint `.135` 200/200;
  PL1 endpoint `.140` 199/200. An idle-A53 PL1 control returned 497/500.
- Intermittent PL1 packet loss remains unresolved. These tests neither establish
  its cause nor prove line-rate forwarding. Do not attribute it to Linux solely
  from this observation; losses existed before the Linux work too.

## Recommended next milestone

Build and verify a **synthetic FPGA-to-Linux telemetry channel first**, then
attach the real header parser/flow tracker. On a user instruction to continue:

1. Review the current block design, PS configuration, address map and minimal
   Linux DT. Define a new analytics-owned DMA interface, interrupt, DDR buffer
   allocation, and software ownership contract without disturbing R5 resources.
2. Add a bounded synthetic record generator with sequence number, timestamp,
   and known test pattern. Specify overflow behaviour and counters. Its output
   must be independent of switch forwarding backpressure.
3. Route analytics DMA through `S_AXI_HPC0_FPD` or HPC1. Hardware coherency needs
   correct AXI attributes, CCI snooping and software memory/DMA configuration;
   merely wiring HPC or setting `dma-coherent` does not establish coherency.
   Review the currently minimal firmware/clock setup before adding Linux drivers.
4. Implement the Linux DMA/ring driver and userspace reader, with interrupts,
   explicit producer/consumer ownership and barriers. Validate data while the
   A53 caches are enabled and under CPU/memory load.
5. Verify sequence integrity, throughput, overruns, ring wrap, reader stop/start,
   and that stopping Linux consumption cannot stall forwarding. Preserve R5
   web/statistics/USB operation during these checks.
6. Replace the generator with bounded Ethernet/VLAN/IPv4/TCP/UDP parsing and
   bidirectional flow aggregation. Handle fragments and unsupported headers
   explicitly. Use flow statistics rather than exporting every packet to Linux.

Later work: statistical baseline/model evaluation, selective capture into a
separate bounded DDR ring, then optional FPGA inference acceleration based on
measured workload. Pre-trigger capture requires a history buffer. The existing
512 KiB forwarding pool is recycled and cannot retain captures indefinitely.

Continue tracking the independent PL1 loss issue before treating traffic-loss
features as reliable training data. Do not begin AI/model work by changing the
forwarding datapath or allocating from R5/PL reserved memory.

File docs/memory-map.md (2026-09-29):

# Memory map, usage and ownership

Updated 2026-09-28 for the R5-0 split-mode FreeRTOS firmware with data cache
enabled, the normal FPGA image without ILAs, and optional minimal A53 Linux.

This document describes the application's memory contract and the register
windows it uses. It is not a complete Zynq UltraScale+ address map. R5-1 is
held in reset; the A53 runs the FSBL during JTAG initialization and is then
left stopped in the standalone boot flow. The optional
[minimal Linux JTAG boot](../software/linux/README.md) starts Linux on the four
A53 cores, reserves both PL/R5 DDR regions below as `no-map`, and transfers
UART1 ownership to Linux using an R5 build with `LINUX_CONSOLE=1`. Its initial
device tree exposes only A53-owned devices and uses the low 2 GiB of DDR.
Any second R5 application or other boot payload must honor these reservations.

Addresses are hexadecimal; range endpoints are inclusive unless explicitly
identified as end symbols. MiB/KiB mean powers of two.

## Reserved memory

| Address range | Size | Usage | Owner and access rules |
| --- | ---: | --- | --- |
| `0x00000000–0x0000FFFF` in the R5-0 local view | 64 KiB | ATCM vectors, boot code and boot data | R5-0 startup and exception handling. This is local TCM, not a DMA buffer address. |
| `0x10000000–0x1007FFFF` in DDR | 512 KiB | Switch packet pool: 256 slots × 2048 bytes | PL buffer manager owns allocation and lifetime. PL ingress/egress and CPU-port RTL DMA engines access payloads through HP0. R5 firmware does not directly access this pool. |
| `0x20000000–0x21DFFFFF` in DDR | 30 MiB | R5 code, constants, data, FreeRTOS heap, stacks and driver state | R5-0 application reservation. The unused portion is reserved capacity, not available to other software without changing this contract. |
| `0x21E00000–0x21EFFFFF` in DDR | 1 MiB | USB host heap, rings, contexts and DMA bounce buffer | R5 USB stack; separate non-cacheable, shareable, execute-never MPU region, single owner; PS USB0 DMA accesses it |
| `0x21F00000–0x21FF7FFF` in DDR | 992 KiB | Reserved gap | Not allocated by firmware |
| `0x21FF8000–0x21FFFFFF` in DDR | 32 KiB | CPU virtual-port AXI DMA descriptors and RX/TX bounce buffers | R5 DMA driver controls ownership transfers to/from AXI DMA. AXI DMA accesses this storage through HP1. |
| Other DDR addresses | Not assigned here | Outside the application's explicit reservations | Do not assume these are free: boot software, other processors and future operating systems require their own allocation review. |

The last two rows of allocated DDR form one contiguous 32 MiB R5 reservation,
`0x20000000–0x21FFFFFF`. The linker excludes the separate fabric packet pool.

R5 local address zero resolves to ATCM for this firmware. It must not be
interpreted as the same storage seen by a PL AXI master at address zero.
DMA pointers are identity-mapped DDR addresses; descriptors never point into
R5-local TCM.

The linker does not allocate R5 BTCM, other-core TCM or OCM for application
sections. Their absence from the linker does not establish that they are
unused by boot software or available for shared DMA storage.

## Cache and memory attributes

| Region | R5 policy |
| --- | --- |
| Application DDR | BSP normal, non-shareable, write-back/write-allocate mapping; D-cache enabled |
| DMA DDR reservation | Higher-priority MPU override: normal, shareable, non-cacheable, execute-never, full read/write access |
| PL register windows | BSP strongly ordered, non-cacheable mapping |
| PS peripheral registers used below | BSP device, non-cacheable mapping |
| Fabric packet pool | No dedicated R5 MPU override; falls within the general DDR mapping, but R5 does not access it |
| ATCM | Tightly coupled storage; not serviced as cached DDR |

Startup flushes/disables D-cache before installing the DMA override, checks
the actual MPU registers, then enables D-cache. The verified boot used MPU
region 10 with attributes `0x0000130C`; the region number is allocated by the
BSP and is not a fixed software interface.

The MPU policy controls R5 accesses. It does not restrict the addresses that
a PL DMA master can generate, and shareable memory does not make the R5 cache
hardware-coherent with DMA. Application-level reservation and ownership rules
remain necessary.

DMA descriptors and payloads are non-cacheable, so the current driver needs
ownership barriers but no per-packet cache clean/invalidate operations.
Cacheable FreeRTOS packet buffers are copied into/out of the DMA buffers;
their addresses are never handed directly to AXI DMA.

**Future work:** review descriptor and payload cache policies separately
after measuring CPU cost and throughput. Cached DMA storage would require
cache-line isolation, explicit maintenance at ownership transfers, and
ring-reuse/reset/error-recovery verification.

PSU JTAG reads see DDR and may miss dirty R5 cache contents. Reading a stale
`xTickCount` or software diagnostic variable through JTAG does not prove the
R5 has stopped. MMIO and the non-cacheable DMA region remain directly readable.

## R5 application allocations

Within cacheable DDR, the linker places executable code and constants,
initialized data, BSS, a C-library heap, and startup/exception stacks.

| Allocation | Current configured size | Usage and ownership |
| --- | ---: | --- |
| FreeRTOS `ucHeap` | 512 KiB | Static array in BSS used by `heap_4`; supplies dynamic RTOS allocations, task stacks and network buffers. Owned by the RTOS allocator and its clients. |
| Linker C-library heap | 16 KiB | Separate from `ucHeap`; reserved for C-library allocation support. |
| Main/startup stack | 16 KiB | R5 startup/application execution before or outside task stack use, as defined by the startup code. |
| IRQ, abort, FIQ and undefined-mode stacks | 1 KiB each | R5 exception-mode storage. |
| Supervisor-mode stack | 2 KiB | Supervisor-mode exception/startup storage. |

Task stacks are not separate fixed DDR address windows: FreeRTOS allocates
them from its heap. Exact code, data, heap and stack addresses change when
the firmware is linked. The authoritative current layout is
`software/r5/out/kr260_r5.map`; the reservation boundaries above are fixed
by the checked-in linker script.

## Non-cacheable DMA allocation

The driver has 16 RX descriptors, two TX descriptors, and one 1536-byte
bounce buffer per descriptor. Each descriptor occupies 64 bytes; all arrays
are 64-byte aligned. Total allocated storage is 28,800 bytes, leaving
3,968 bytes reserved within the MPU region.

This is the allocation in the cache-enabled ELF verified on 2026-09-21.
Individual array addresses can change with compiler/linker layout; software
uses symbols, not these literal addresses.

| Address range | Bytes | Object | Usage |
| --- | ---: | --- | --- |
| `0x21FF8000–0x21FF8BFF` | 3,072 | `tx_data[2][1536]` | CPU writes outgoing frames; DMA reads them |
| `0x21FF8C00–0x21FFEBFF` | 24,576 | `rx_data[16][1536]` | DMA writes received frames; CPU reads them after completion |
| `0x21FFEC00–0x21FFEC7F` | 128 | `tx[2]` | TX descriptor rotation |
| `0x21FFEC80–0x21FFF07F` | 1,024 | `rx[16]` | RX descriptor ring |
| `0x21FFF080–0x21FFFFFF` | 3,968 | Reserved slack | Not allocated to ordinary application data |

The section is `.dma_nocache (NOLOAD)`, outside startup BSS clearing.
After successfully resetting AXI DMA, `fabric_dma_init` explicitly clears
descriptors and buffers, initializes links/control fields, and publishes them
to DMA. This prevents stale contents from a prior boot becoming valid work.
ELF checks enforce array placement, alignment and separation from BSS/stacks.

## Packet ownership and data flow

The fabric pool and R5 DMA buffers are separate stores, connected by the
CPU port's AXI streams:

```mermaid
flowchart LR
    P["Physical ports"] <--> F["PL switch and CPU-port RTL"]
    F <-->|"HP0: RTL DMA"| D["DDR fabric packet pool<br/>0x10000000–0x1007FFFF"]
    F <-->|"CPU AXI streams"| A["AXI DMA<br/>MM2S / S2MM / SG"]
    A <-->|"HP1"| B["Non-cacheable R5 DMA storage<br/>0x21FF8000–0x21FFFFFF"]
    B <-->|"CPU copies"| N["Cacheable FreeRTOS buffers<br/>R5 application DDR"]
```

The CPU-port RTL reads/writes the fabric pool through HP0. The vendor AXI DMA
reads/writes R5 descriptors and bounce buffers through HP1. Neither the
FreeRTOS allocator nor the vendor AXI DMA owns fabric-pool allocation.
PS GEMs use external FIFO interfaces; their internal DMA engines do not
manage these DDR regions.

### Fabric packet pool

1. An ingress engine obtains a buffer ID from the PL free-list manager.
2. The payload is written at
   `0x10000000 + buffer_id × 2048`.
3. Queue metadata records frame length and destinations. A flooded frame
   shares one payload slot among its destination queues.
4. The slot remains allocated while destinations retain references.
   Completion or queue flush releases references; the free-list manager
   returns the slot when no references remain.

A CPU-originated frame also obtains a fabric-pool slot. A frame delivered
to the CPU is copied from the pool over AXI-stream into an R5 RX buffer.
These ownership transitions are distinct from the R5 DMA ring lifecycle.

### R5 transmit

1. R5 places the private two-byte CPU TX metadata header and Ethernet frame
   in an available TX bounce buffer, padding the Ethernet portion to 60 bytes.
   DMA length includes the header; fabric DDR storage excludes it. See
   [CPU transmit ABI](cpu-tx-metadata.md).
2. It initializes the TX descriptor, executes the ownership barrier and
   writes AXI DMA's tail descriptor register.
3. DMA owns the submitted descriptor/buffer until completion. The sending
   task blocks on a binary semaphore signaled by the MM2S completion/error
   interrupt (GIC IRQ 127), with a 100 ms timeout. It never overwrites
   submitted data while DMA may own it.
4. After completion and error checks, the driver can reuse the storage.
   Two descriptors alternate so consecutive submissions have different
   tail addresses. This driver sends synchronously.

### R5 receive

1. R5 submits initialized RX descriptors/buffers to DMA.
2. DMA fills a buffer, writes completion/status, and raises S2MM IRQ 128.
   The ISR acknowledges the interrupt and notifies the network service task.
3. The notified task drains completed descriptors (including malformed ones),
   executes the barrier, validates status/length,
   and copies the packet into software-owned storage. The network service
   then allocates/copies into the FreeRTOS network buffer.
4. R5 clears status and republishes the descriptor after a barrier.
   DMA can reuse the buffer only after that handoff.

RX notifications coalesce: the descriptor ring remains the source of truth.
The task drains at most 16 descriptors per batch and yields one tick only
when more work remains, allowing link management to run under load. While
idle it blocks on notifications; a one-second timeout services DHCP policy
without polling packet descriptors. Initial draining covers arrivals before
the task handle exists.

A DMA error or TX timeout masks both DMA interrupt sources and marks the driver failed. It does not reuse storage
that hardware might still own. Firmware disables ports; automatic DMA restart
remains future work.
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

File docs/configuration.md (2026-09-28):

# Persistent board configuration

The R5 configuration record reserves five permanent MAC addresses for this board:

| Use | Address |
| --- | --- |
| CPU management interface and STP bridge identity | `00:0a:35:0f:37:45` |
| Reserved | `00:0a:35:0f:37:46` |
| Reserved | `00:0a:35:0f:37:47` |
| Reserved | `00:0a:35:0f:37:48` |
| Reserved | `00:0a:35:0f:37:49` |
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

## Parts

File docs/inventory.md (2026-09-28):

# Design inventory and pending development

## Current remaining work

This list is the current backlog; dated sections below preserve earlier
milestones and may describe issues subsequently fixed.

| Priority | Work | Completion criteria |
| --- | --- | --- |
| 1 | Timing and CDC closure | [Current review](timing-cdc-review-20260928.md): routed setup margin is 18 ps under a provisional RGMII model. Complete carrier/connector/PHY bounds and reconcile XTP688 package delay; define a stable supported MDIO divider and constrain its read/write paths; qualify coordinated reset recovery across SmartConnect and fabric targets. Mailbox delays reviewed; Gray audit expanded to all 196 bits, including six optimized MSBs previously missed. |
| 2 | Sustained-load qualification | Exercise simultaneous ports, minimum-size frames, flooding and buffer exhaustion. Measure throughput, latency and loss, plus MAC-dump completion time and forwarding impact under contention. Add pool occupancy/high-water marks, per-ingress allocation waits/failures, and DMA request-to-completion latency including arbitration. Dump starvation under continuous traffic is permitted by its priority policy. |
| 3 | Recovery and fault injection | Extend the passing GEM1 stopped/resumed-clock test to cable flaps and other banks; test independent resets, AXI errors, queue flushes and recovery without reboot. A timed-out dump must retain buffer ownership until hardware completion or coordinated reset. |
| 4 | Remaining physical IP partitioning | Package RGMII and SFP transceiver/clock/reset shells with owned constraints, reset contracts and reusable verification. |
| 5 | Speed expansion | PL copper 10/100/1000 full-duplex functional qualification passes on both ports (see [speed support](pl-ethernet-speeds.md)). Widen the SFP packet interface to 128 bits before faster MAC/PCS/transceiver development for 1/2.5/5/10G. GEM0 remains board-limited to 1G. |
| 6 | STP completion | STP/RSTP engine, single-owner task, persistent web controls, destination blocking and RX-tag backpressure are deployed with matching fabric/management 2.1; basic forwarding/management checks passed. Qualification of loops, topology changes and mixed vendors on hardware is deferred. The running image remains STP-disabled. See [spanning tree](spanning-tree.md). |
| 7 | Boot and storage reliability | Package persistent boot artifacts and validate cold boot, restart, SD removal, failed writes and interrupted saves. Current FPGA/firmware deployment is volatile JTAG. |
| 8 | DMA cache optimization | Measure CPU cost/throughput before revisiting the non-cacheable HP1 descriptors and packet bounce buffers. Validate ownership, cache-line isolation, ring reuse and error recovery for any change. |

Completed: CPU TX frame metadata/override CDC removal, pipelined CPU DDR writes,
125 MHz fabric, HTTP worker concurrency, MAC dump DMA, and the manual-refresh
MAC-table web page, packaged PL PHY management, and full-duplex PL 10/100/1000.
Both PL ports pass CPU/forwarded ping, HTTP and SNMP checks at every speed;
long-duration, congested mixed-speed and simultaneous-all-port qualification
remain open. Unplugged GEM1 RX timeouts are consistent with intermittent receive-clock
pauses. Independent-bank mailboxes, Gray clock-progress monitoring, and R5 /
SNMP / web availability reporting are deployed as ABI 2. Full-board
implementation and routed timing review pass. Controlled GEM1 PHY power-down
confirms that bank 2 becomes stale while the other twelve banks continue, then
recovers without reboot. Both the CPU and forwarded miner passed 450/450
full-size pings across linked, stopped-clock and recovered windows. See
[statistics](statistics.md) and [deployment evidence](verification.md#2026-09-26-independent-statistics-bank-mailboxes-deployed). Broader management
features such as LLDP/LACP and SNMPv3 are separate feature work.

## CPU interrupts, configuration display and enclosure (2026-09-27)

CPU packet TX/RX now use DMA completion/error interrupts. A fresh FPGA build,
routed timing checks and hardware deployment passed; 2,000 CPU and 100 forwarded
full-size pings had no loss and DMA counters reported no errors/timeouts.
The configuration page displays active IPv4 settings separately from saved
preferences and has readable address and credential fields on desktop/mobile.
See [verification](verification.md#2026-09-27-interrupt-driven-cpu-packet-dma).

The [KR260 clamshell](../mechanical/kr260-enclosure/README.md) provides fixed
mounts, screw closure and measured port/SD access from the supplied A02 carrier
assembly. Geometry/interference and STL checks pass. Printed fit, cable release
access with actual plugs and enclosed thermal testing remain outstanding.

## Passive IPv4 discovery (2026-09-27 deployed)

The R5 and MAC-table web page now support passive ARP sender observations,
multiple IPv4 addresses per MAC, observation age, and stack ARP-cache fallback.
Host/browser tests and the all-counter firmware build pass. The firmware is
deployed; live discovery identifies the workstation, miner and other observed
ARP senders. There are no RTL changes.
See [web behavior](web-interface.md#passive-ipv4-discovery-2026-09-27-deployed).

## PL PHY-management catalog partition (2026-09-26 deployed)

`pl_phy_mdio` 1.0 packages the real MDIO controller, DP83867 initializer,
link poller, IOBUF and two-stage PHY-reset-release crossing. Production
`system.bd` now contains nine custom catalog cells from six IP kinds.
The two instances retain PHY addresses 2/3 and CPU windows 0x80010000/0x80020000.
No firmware change is required. Native/packaged regressions and synthesis/PNR
pass; setup WNS is +0.019 ns, hold +0.010 ns. JTAG deployment passed DHCP,
1,000/1,000 full-size pings each to the CPU and PL0 miner, HTTP concurrency,
SNMP and manual MAC-table refresh. Both packaged PHY controllers report
successful initialization and valid polling. RGMII I/O, clocks, physical reset requests,
GTH and SFP sideband remain in the board shell. External MDIO timing and
broader physical-shell migration remain pending. See [partitioning](ip-partitioning.md)
and [interface contract](../ip_repo/INTERFACES.md#pl-phy-management-pl_phy_mdio-11).

## MAC-table dump DMA and manual web view (2026-09-26 deployed)

Fabric 1.2 adds a fourth HP0 master and a CPU AXI-Lite command window at
0x80110000. It scans all MAC entries and ages into a caller-owned 32 KiB DDR
buffer using 16-beat bursts, yielding to packet DMA and table learning/aging.
The R5 helper handles cache ownership. The public `/mac-table` page provides
manual refresh only, with no startup/page-load/periodic scan. The design is
routed and deployed: +0.018 ns setup / +0.010 ns hold; simultaneous CPU/miner
pings each passed 1,000/1,000, with live manual dumps and HTTP tests passing.
See [deployment evidence](verification.md#2026-09-26-mac-table-dma-and-manual-web-view-deployed). See [interface contract](mac-table-dump.md).

## 125 MHz fabric and trunk preparation (2026-09-26 deployed)

The fabric target is now 125 MHz, with 250 ms MAC aging preserved. The hardware
frequency register drives new HTTP/SNMP frequency reporting. Current counter
widths still cover half a second at the higher rate. The 125 MHz build passes
routed timing (fabric +1.655 ns setup; overall +0.018 ns setup / +0.010 ns hold)
and is deployed with matching R5 firmware. DHCP, HTTP/SNMP frequency reporting,
and 1,000 full-size pings each to CPU and forwarded miner passed. See
[board validation](verification.md#2026-09-26-125-mhz-fabric-board-deployment).

Future work: **widen the SFP packet interface to 128 bits** for a high-speed
1/2.5/5/10 Gb/s trunk. Keep byte enables and frame boundaries, adapt buffering
and parsing, revisit byte-counter widths and qualify DDR throughput. The current
SFP remains 1 Gb/s; its 16-bit fabric interface is limited to 2 Gb/s raw at
125 MHz. Faster MAC/PCS and transceiver support remain separate work.

## CPU TX metadata and pipelined CPU DDR writes (2026-09-26 deployed)

Fabric 1.1 / management 1.2 replace the CPU override CDC/register with a
mandatory per-frame DMA header. Firmware uses one atomic header/payload send
path and rejects mismatched hardware. See [contract and validation](cpu-tx-metadata.md).
The matching FPGA/firmware, including the two-word CPU write pipeline, are
now deployed over JTAG. Fresh route passes +0.018 ns setup / +0.010 ns hold;
CPU and forwarded miner tests each passed 1,000 full-size pings with no loss.
See [deployment evidence](verification.md#2026-09-26-cpu-tx-metadata-and-dma-pipeline-board-deployment).
The previous routed review below remains historical evidence.

## Routed timing and CDC review (2026-09-26)

Fresh reports confirm setup WNS +0.018 ns and hold WHS +0.010 ns. All 2,632
CDC-1 rows trace to statistics selector logic and require the documented
mailbox protocol, rather than blanket waivers. The CPU TX override crossing
was subsequently removed. MDIO timing, RGMII board/PHY margins and reset
recovery remain sign-off items.
See [review and closure order](timing-cdc-review-20260926.md). RTL, constraints
and the running board image were not changed by this review.

## Management 1.1 and interface contracts (2026-09-25)

Current source packages the statistics decoder inside management, with a
versioned `switch_management` top and unchanged firmware ABI. The fresh
acceptance flow passes catalog/BD audits, 20 focused native and packaged cases,
and whole-switch comparisons. [Interface contracts](../ip_repo/INTERFACES.md)
now define ownership and integration requirements. This source revision has
passed synthesis, PNR and bitstream generation (WNS +0.018 ns, hold
+0.010 ns) and was downloaded with matching firmware. Sustained GEM1/PL0
CPU/endpoint pings and SNMP passed. The DHCP single-Discover failure is fixed
with a readiness delay and corrected retransmission ceiling. Intermittent R5
and forwarded endpoint ping loss remains unresolved. HTTP now uses four workers with independent
buffers and serialized configuration access; parallel-client/browser tests
pass. See [startup investigation](startup-and-http-investigation.md) and
[verification](verification.md).
Physical copper/SFP packaging remains pending.

## IP repository verification suites (2026-09-25)

All five digital packages own focused test manifests. The runner checks
native or packaged dependencies, elaborates public tops and rejects legacy
simulator failure messages as well as nonzero exits and timeouts. Catalog
audits also check identity, relocation and bus mappings. Whole-switch
counter-option equivalence remains required. See
[IP repository commands and coverage](../ip_repo/README.md#independent-ip-regression-suites).

## IP repository partitioning (2026-09-25)

Five digital IP manifests and reproducible Vivado packaging now live in
[`ip_repo`](../ip_repo/README.md). The extracted fabric owns shared buffer
management, forwarding and DDR engines; GEM endpoints own their local
counters. All four counter-option combinations pass the old/new RTL
comparison. See [partitioning](ip-partitioning.md) for the diagram, interfaces,
validation evidence and remaining physical-shell migration. Production
`system.bd` now instantiates all seven catalog cells directly; that newer
assembly passed generated-datapath simulation and bitstream generation
(WNS +0.018 ns, hold +0.011 ns) and passed JTAG deployment with matching
R5 firmware, settled GEM1/PL0 connectivity, SNMP and HTTP checks.
The preceding native all-counter image was routed and loaded over JTAG with matching
R5 firmware. DHCP assigned `10.0.1.104`; CPU and settled endpoint pings,
web access and SNMP passed on the connected GEM1/PL0 path. Initial DHCP
and endpoint losses recovered but remain unexplained. Routed WNS is
+0.018 ns and hold slack is +0.010 ns; CDC sign-off remains incomplete.

## Persistent configuration (2026-09-24, save/reload verified on board)

Added five permanent board MACs (`00:0a:35:0f:37:45` through `:49`), first-MAC
CPU/STP identity, an admin/admin password verifier, and redundant microSD configuration files.
The web form saves copper/SFP preferences and DHCP/static IPv4 for next startup.
Port admission follows current hardware support; this does not implement PL
10/100 or SFP rates above 1G. Configuration writes now require administrator authentication; viewing stays public. See
[configuration](configuration.md) for storage layout, recovery and validation.
R5 USB0 host/hub/mass-storage and FAT support are deployed. FAT-card detection,
authenticated save/readback and retention across full PS resets passed. All
ports are restored enabled; DHCP is `10.0.1.104`. USB2244 unsupported cache flush
is handled by a guarded write-through compatibility path. Physical power-cycle
and hotplug checks remain pending, as does investigation of a transient ping
outage that self-recovered. See [USB storage](usb-storage.md).

## 2026-09-23 counter observation and open issues

The 30-second SNMP observation found no packet/AXI errors or collector
timeouts; physical ingress still recorded two write-data stall cycles per
burst. See [verification](verification.md) for measurements and the pending
STP TX-override, task-serialization, CDC and RX-tag alignment issues. These
remain open with STP disabled by default.

## 2026-09-23 STP defaults disabled; web control and persistence pending

Real-hardware testing against a genuine adjacent STP switch surfaced a real
concurrency bug (see verification.md) and confirmed classic-BPDU interop
works. Per direction, STP now defaults OFF (`stp_task.c`'s `stp_enabled`
starts `false`; no hardware is touched while disabled) until web control
and persistent configuration exist -- both explicitly noted as pending,
not yet implemented. `stp_get_enabled()`/`stp_set_enabled()` are the entry
point for that future work.

## 2026-09-23 STP protocol implementation

Building on the same-day hooks below, `software/r5/src/stp.c`/`include/stp.h`
now implement an initial subset of classic 802.1D-1998 STP (BPDU codec, root/designated/
blocking election, Blocking→Listening→Learning→Forwarding timers), exercised
with a three-bridge triangle-topology host test that elects one root and
blocks exactly one port (`tests/test_stp.c`). `stp_task.c` is the hardware
glue (1 Hz task, drives FWD_EN/LEARN_EN and CPU TX via `pstate.c`, overrides
`fabric_ctrl_frame_rx`). A new hardware feature was needed to make this
correct: a per-frame CPU RX ingress-port tag (`buf_mgr_pkg`'s per-buffer
metadata, `switch_top.sv`'s `cpu_rx_ingress_*` ports, `rx_diag_regs`'s new
`CPU_RX_TAG` register at `0x50`) — see
[architecture: STP implementation](architecture.md#stp-implementation-firmware-2026-09-23).
Live status is on the web statistics page (`/api/statistics`'s `"stp"`
object). LACP/LLDP remain unimplemented hooks only.

## 2026-09-23 STP hardware/software hooks (no protocol logic)

Added hardware and firmware hooks for future control-protocol support
(STP, and generically LACP/LLDP/other 802.1D Slow Protocols), without
implementing any protocol itself. `mac_addr_resolver.sv` now traps the
reserved `01:80:C2:00:00:0x` block to the CPU port unconditionally;
new per-port `fwd_en_i`/`learn_en_i` inputs (threaded through
`mac_forwarding_top.sv` and `switch_top.sv`) add forwarding/learning gates
independent of physical link state; trapped control frames bypass forwarding
but source learning remains gated; a new CPU TX destination override lets firmware target one
specific egress port for a single CPU-originated frame via a new generic
`ctrl_value_xdomain.sv` CDC module. Six new `rx_diag_regs` registers
(`0x38`-`0x4C`) expose these to software; `software/r5/src/pstate.c`
provides thin register wrappers and a weak `fabric_ctrl_frame_rx` RX hook
that `network.c` calls for reserved-block frames instead of dropping them
in the IP stack. See
[architecture: control-protocol hooks](architecture.md#control-protocol-hooks-stplacplldp-no-protocol-logic)
and [cdc-review: STP/control-protocol hardware hooks](cdc-review.md#stpcontrol-protocol-hardware-hooks-2026-09-23).
This describes the initial hooks stage. The STP implementation above now
supersedes its original scope; LACP/LLDP algorithms remain unimplemented.

## 2026-09-22 PS Ethernet speed control

R5 firmware now supports selectable 10/100/1000 full-duplex advertisement on
GEM1 (right lower, RGMII), speed-aware MAC/clock changes after a port flush,
and physical speed reporting in HTTP/SNMP. GEM0 remains 1000-only: the PS
SGMII path does not support lower rates. The web page disables unsupported
GEM0 options and validates that GEM1 retains at least one advertised speed.
Sensor voltages and current display three decimal places and temperatures one.
GEM1 passed full-MTU pings at all three speeds using the managed-switch
uplink; GEM0 connects to the gigabit-only endpoint and SFP is disconnected.
See [PS speed implementation and limitations](ps-ethernet-speeds.md).

## 2026-09-22 R5 web management

`software/r5/src/web_task.c` serves HTTP port 80; `web_protocol.c` provides
bounded request parsing and snapshot JSON serialization. The embedded
`software/r5/web/index.html` has separate configuration/statistics pages,
initially unauthenticated port controls, and one-second statistics refresh. The link
task combines an administrative mask with observed PHY/PCS links and controls
MAC receive enables. That deployed version has volatile settings; the pending
2026-09-23 build adds authenticated, persistent settings. See
[web-interface.md](web-interface.md).

Deployed at `http://10.0.1.214/`. Browser polling, GEM0 disable/enable,
management continuity over SFP, and restored endpoint pings passed. The user
confirmed the SFP uplink and GEM0 endpoint connections were unchanged at
that validation; the later speed tests above moved the uplink to GEM1. All ports
were left enabled. Persistent configuration and automatic SFP startup recovery
remain future work.

## 2026-09-22 timeout location diagnostics

Added per-bank/slot counters for both timeout classes and the latest snapshot
index plus release active/target indices. SNMP provides a two-index timeout
table and three new health scalars; the reader script labels nonzero locations.
Host tests verify attribution when active and next indices differ, a nonzero
DDR bank/slot response timeout, retry behavior, and table walking for all build
options. The all-counter R5 application is built and deployed on the existing
bitstream; live SNMP queries and full-MTU pings pass. Hardware signal capture
and root-cause diagnosis remain future work.

## 2026-09-22 physical ingress DMA pipeline

The shared physical-port write DMA now overlaps packet-RAM reads and AXI writes
using a two-word buffer with explicit reservation for in-flight reads. It
sustains one accepted 128-bit beat per cycle after fill with WREADY high,
while retaining one outstanding frame burst. The dedicated
`tb_ingress_dma_pipeline.sv` covers all 1–2,048-byte lengths, five ports,
backpressure, delayed AW/B handshakes and reset recovery. Existing ingress,
switch forwarding and statistics regressions pass before hardware build.
The all-counter bitstream and XSA are built with WNS +0.018 ns and WHS
+0.010 ns. The optimized image is now loaded and passed DHCP, SNMP, and
100/100 full-MTU pings to each of the R5 and GEM0 endpoint. See
[verification](verification.md) for measured cycle counts and build results.

## 2026-09-22 timeout diagnostics

The R5 collector now separates mailbox-release wait timeouts from hardware
snapshot-response timeouts, preserving the combined total. Both are exposed
as additional SNMP health scalars and by the reader script. Timeout bank/index
logging is now implemented (see the location diagnostics above); root-cause
diagnosis remains pending. A later live query recorded
one snapshot-response timeout and zero mailbox-release timeouts. This firmware change requires
no FPGA rebuild and does not alter the deadlines or retry behavior.

## 2026-09-21 SNMP management

Read-only SNMPv2c now exposes all compiled-in counters, collection health,
link status and environmental readings. Added a bounded BER engine, R5 UDP
agent, custom [MIB](mibs/KR260-SWITCH-MIB.txt), [query guide](snmp.md), and
host tests for all four counter builds. The
[reader script](../scripts/read_snmp_counters.py) provides labeled snapshots,
periodic polling and JSON output. Net-SNMP GET, GETNEXT and GETBULK
work on the board; SET is rejected. All sensors report valid samples.
The current all-counter firmware passed repeated walks and full-MTU pings.
Follow up the SFP negotiation stall after JTAG boot (recovered with a
TX_DISABLE pulse) and recurring statistics mailbox timeouts (2 since restart
at the latest observation, with no increase during the 30-second sample).
Timeout bank/index and reason diagnostics are now implemented; short samples show no packet
or AXI errors, but sustained-load validation remains pending. SNMPv3 and traps remain unimplemented; the example PEN is for
this lab only. See [verification](verification.md).

## 2026-09-21 statistics extension

Added standard per-port read/clear packet/byte counters; optional `STATS_DDR`
and `STATS_DEBUG` monitors; R5 250 ms collection into 64-bit DDR totals; and
PS/PL SYSMON plus INA260 SOM power sampling. Definitions, build options and
register ownership are in [statistics.md](statistics.md). This extension is
implemented through place-and-route/bitstream generation with all counters
enabled (WNS +0.018 ns, WHS +0.010 ns), with matching R5 firmware built;
JTAG deployment, DHCP and full-MTU ping checks passed. SNMP now verifies
live increasing totals and numerical sensor readings; detailed accuracy,
sustained-load and fault-injection validation remain pending. Earlier
board-test results below apply to the previous image.

Baseline: 2026-09-22. The repository contains **67 SystemVerilog files under
`rtl/`** (63 logical modules, including four simulation-only behavioral models --
GTH, RGMII, PL Ethernet clock generation, and MDIO -- and four packages),
**35 testbenches** (34 portable and one XSim-only), one AXI memory BFM, three Vivado IP `.xci` configurations
(GTH, PL Ethernet clocks and SFP PCS clocks), four XDC constraint files,
seven Vivado Tcl scripts, a paired-ILA capture analyzer, one synthesis source list and `sim/Makefile`. The inventory follows actual module instantiations and
interfaces; some source comments describe older stages of development.

The target software environment is **FreeRTOS**. Existing CPU-port comments
mention Linux socket buffers. The FreeRTOS-LTS source reference is now present,
and an initial [R5 firmware](../software/r5/README.md) now builds with a generated
standalone BSP, upstream kernel/TCP, TTC timers and virtual-port DMA driver.
Initial JTAG execution now verifies UART, timer progress, all four copper links and
CPU-port reception/transmission, DHCP acquisition and same-address ping after cable moves (see
[verification](verification.md#first-live-r5-bring-up-2026-09-20)). Counts above exclude
the third-party checkout.
The initial driver implements that interface with copied DMA buffers.
The `20260920-all_ports_passing_dhcp_ping` milestone adds SFP DHCP and settled
small/full-MTU ping to the earlier four-copper-port results. The managed
switch RX-error counter remained at 803 on the operator's follow-up check;
startup losses and isolated bring-up errors remain documented in
[verification](verification.md#all-ports-passing-dhcp-and-ping-milestone-2026-09-20).

See the [overall architecture diagrams](architecture.md) and the
[verification report](verification.md). "Present" below means source exists;
it does not mean the block is integrated on the board or production-ready.

The copper-tested milestone is `29aea8f`. The subsequent [SFP investigation](sfp-debug.md)
adds module/PHY IIC diagnostics, two SFP ILAs and capture scripts, a GTH receive-flag
wiring regression, corrected RXCTRL mapping and TX-derived common user clocks.
RTL module counts are unchanged. PL1 RX IDELAY is 750 ps; PL0 source remains
700 ps, with a 900 ps override in the earlier copper-tested/debug images.
The current normal image uses the source's 700/750 ps delays, explicitly
selects GTH LPM equalization and contains no ILAs or debug hub. It also
excludes the ingress port from destination lookup hits. Setup/hold slack
is +0.018/+0.010 ns; DHCP and 300/300 full-MTU pings to each of the CPU and
GEM0 endpoint passed, with zero SFP receive errors. See
[normal-image validation](verification.md#normal-image-without-debug-ilas-2026-09-21).
The optional debug scripts and historical captures remain available.
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

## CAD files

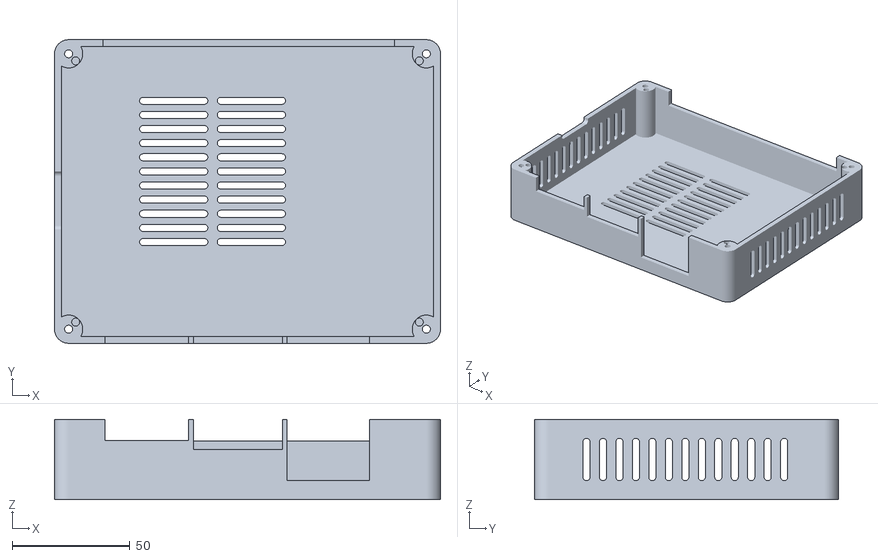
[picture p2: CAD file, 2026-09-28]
mechanical/kr260-enclosure/output/lid.stl
164.0 x 129.0 x 34.0

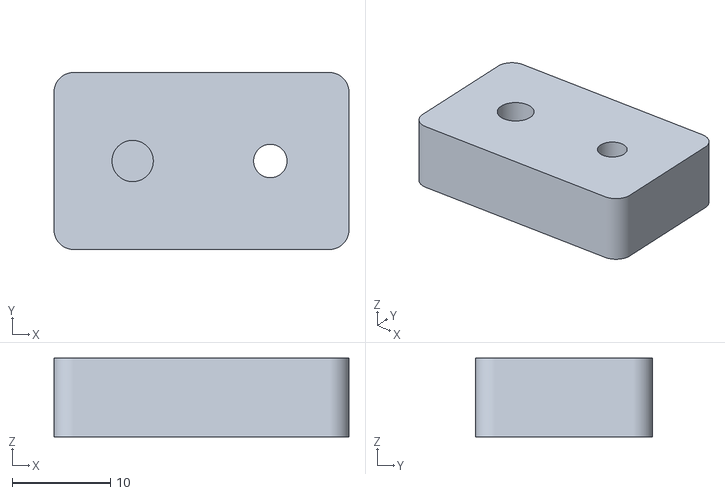
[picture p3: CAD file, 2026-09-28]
mechanical/kr260-enclosure/output/fit_coupon.stl
30.0 x 18.0 x 8.00

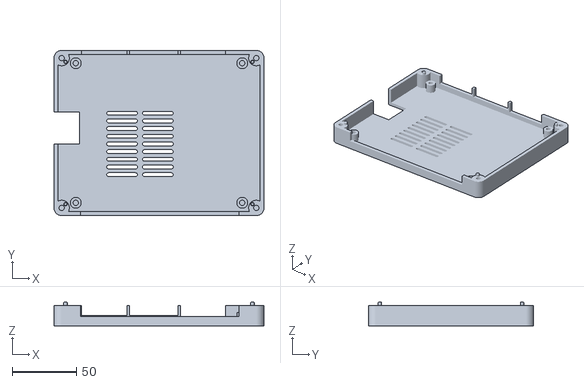
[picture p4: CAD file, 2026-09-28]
mechanical/kr260-enclosure/output/base.stl
164.0 x 129.0 x 18.6

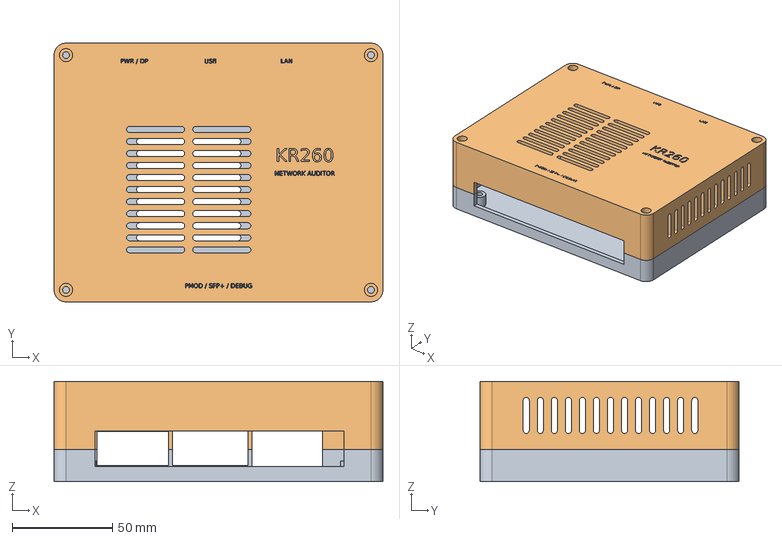
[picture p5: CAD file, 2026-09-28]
mechanical/kr260-enclosure/output/clamshell.step
164.0 x 129.0 x 50.0 mm

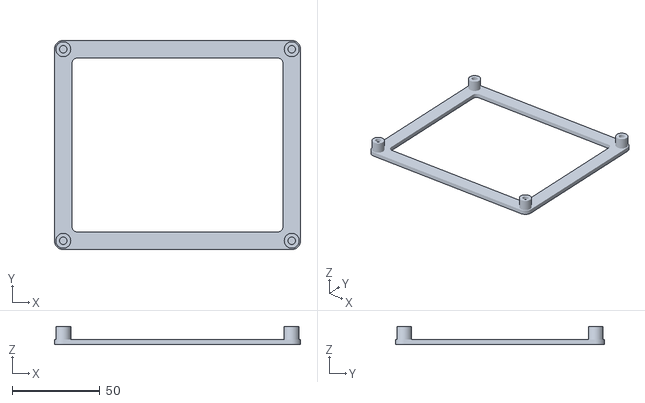
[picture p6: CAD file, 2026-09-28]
mechanical/kr260-enclosure/output/fit_frame.stl
140.0 x 119.0 x 10.4

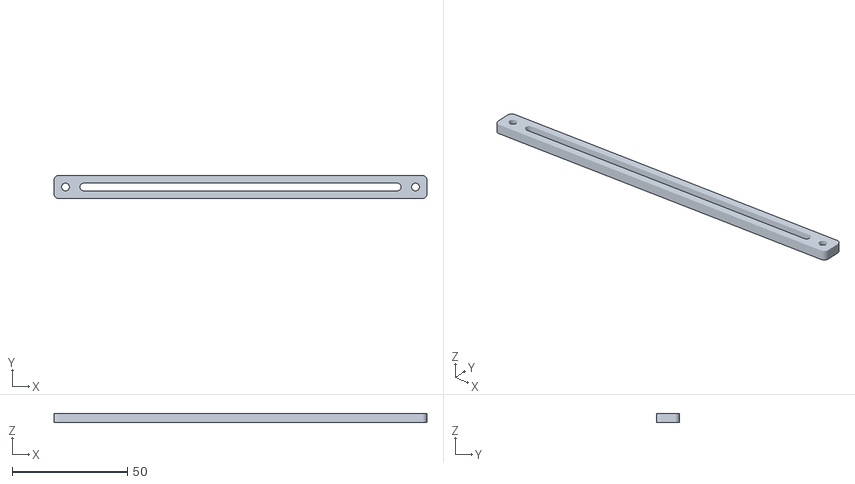
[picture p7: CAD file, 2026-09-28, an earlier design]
mechanical/kr260-enclosure/archive/v1-output/mounting_rail.stl
162.0 x 10.0 x 4.00

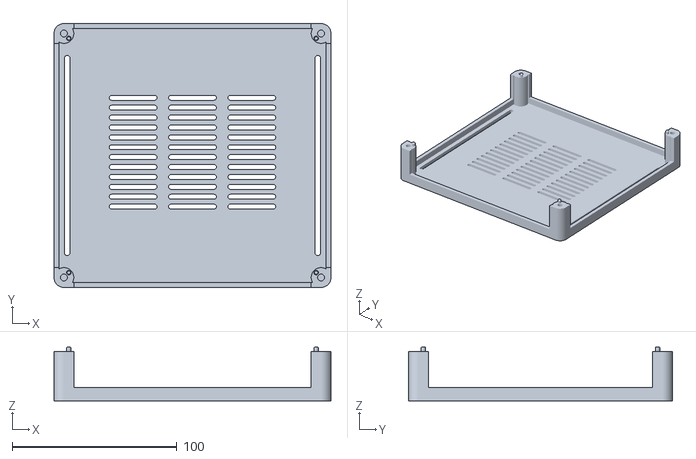
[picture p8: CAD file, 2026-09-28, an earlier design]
mechanical/kr260-enclosure/archive/v1-output/base.stl
168.0 x 160.0 x 32.6

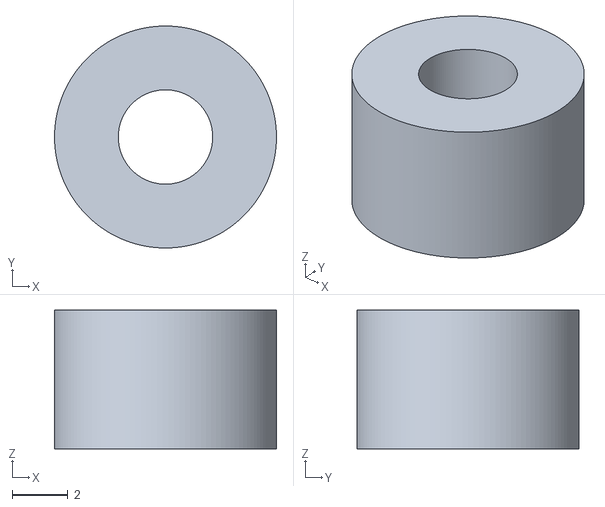
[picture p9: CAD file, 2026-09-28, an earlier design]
mechanical/kr260-enclosure/archive/v1-output/rail_spacer.stl
8.00 x 8.00 x 5.00

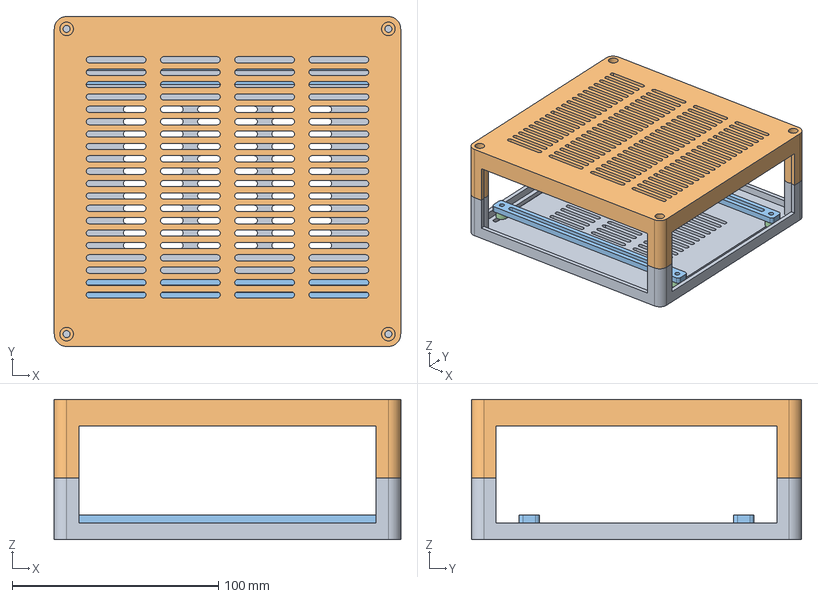
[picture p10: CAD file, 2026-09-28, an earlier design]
mechanical/kr260-enclosure/archive/v1-output/clamshell.step
168.0 x 160.0 x 68.0 mm

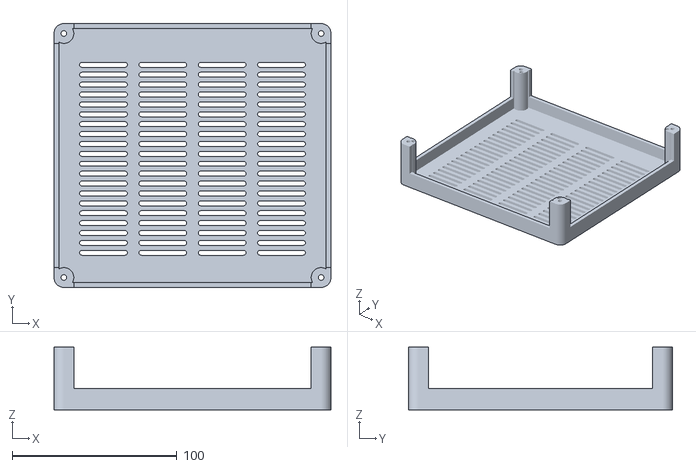
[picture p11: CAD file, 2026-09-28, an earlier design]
mechanical/kr260-enclosure/archive/v1-output/lid.stl
168.0 x 160.0 x 38.0

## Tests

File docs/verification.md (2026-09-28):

# Design inventory verification

## 2026-09-28 Timing and CDC review

Reviewed the deployed CPU-interrupt routed checkpoint with Vivado 2026.1.
Existing constraints pass at +0.018 ns setup and +0.010 ns hold. Corrected
the custom Gray audit to include six optimized binary/Gray MSBs omitted by
the old source-name filter; all 196 first-stage bits pass the expanded check.
The final audit also rejected injected missing `ASYNC_REG`, failing maximum
delay, and false-path conditions. Evidence is under
`build/ip_refactor/timing_cdc_20260928/`.

The supplied XTP688 reference was reviewed and remains a local download,
consistent with other vendor timing references. It includes package plus SOM
trace delay and excludes connectors; carrier routing data is unavailable.
RGMII physical/PHY timing, MDIO timing constraints and coordinated reset
recovery remain open. No RTL, numeric implementation constraints or deployed
image changed. See the [full review](timing-cdc-review-20260928.md) for results,
assumptions and closure steps.

## 2026-09-27 Current IPv4 panel and credential widths

Added public `GET /api/network`, taking a coherent snapshot of the running
FreeRTOS endpoint's IP address, netmask, gateway, up state and boot-selected
DHCP/static mode. The configuration page shows these at the top and refreshes
once per second without replacing pending form edits. Username/password fields
now use 26ch widths (about 223 px) and wrap on mobile; passwords remain masked.

The all-counter firmware rebuild and browser regression passed, including
DHCP address changes, network-down display, static mode, and saved settings
remaining separate from the active address until restart. Deployed through
JTAG with the accepted CPU-interrupt bitstream. Live Chromium checks at 1280 px
and 375 px confirmed `10.0.1.104`, `255.255.255.0`, gateway `10.0.1.1`, readable
credential fields, preserved edits across refresh, and unchanged saved settings.
Logs/screenshots are under `build/cpu_irq/current_ipv4/`. The deployed ELF SHA-256
is `f11af9a99f98736bff1e3a21959dbdfa04cf873c179b3894f1b96df3d707d254`.

## 2026-09-27 IPv4 configuration field widths

Widened the IP address, netmask and default-route inputs from the inherited
20 px checkbox width to 18ch (about 163 px), with monospace text and wrapping
labels. Rebuilt the all-counter R5 firmware and deployed it through JTAG using
the accepted `build/cpu_irq/acceptance_2026/` bitstream. Chromium checks against
`http://10.0.1.104/configuration` at 1280 px and 375 px verified that all three
fields display `255.255.255.255` completely and remain inside the viewport.
The test values were only placed in the browser DOM; no settings were saved.
Build/deployment logs and screenshots are in `build/cpu_irq/ipv4_fields/`.
The deployed ELF SHA-256 is
`4ea71a1f8819cfa7b757316cb00a0005ad742b1f07367bc11d1088447e982844`.

## 2026-09-27 Interrupt-driven CPU packet DMA

Replaced CPU packet completion polling with AXI DMA interrupts, rebuilt the
complete FPGA design and all-counter R5 firmware, and deployed both through
`10.0.1.109:3121`. UART capture used `10.0.1.109:2323`. The KR260 regained DHCP
address `10.0.1.104`; PL0 (uplink) and PL1 (downstream `10.0.1.140`) remained at
1 Gb/s full duplex. This is a **volatile JTAG deployment**. Active/saved
configuration matched the pre-deployment JSON exactly; STP remained disabled.

### Change and ownership contract

- The existing MM2S/S2MM wires on PL IRQ0 bits 6/7 now drive enabled, level-high
  GIC IRQs 127/128 at priority `0xa0`. The production-BD audit checks these wires.
  The SDT SPI-relative IDs are converted to raw GIC IDs with a checked `+32`.
- DMA completion/error interrupts are enabled with completion threshold one.
  The ISR acknowledges W1C status and wakes tasks; it does not copy packets.
  FreeRTOS assembly retains responsibility for GIC acknowledgement/EOI.
- TX retains the mutex shared by IP and directed/STP senders, and blocks on a
  binary semaphore until interrupt completion or a 100 ms timeout. A completed
  descriptor without an interrupt fails closed instead of silently falling
  back to polling. Errors mask both DMA interrupt sources and retain ownership
  of potentially outstanding buffers.
- RX uses task notifications and drains completed descriptors in bounded
  batches, including malformed descriptors followed by valid frames. Initial
  draining covers arrivals before task creation; pending notifications cover
  arrivals between draining and blocking. Only a remaining backlog causes a
  one-tick fairness delay. The one-second idle timeout services DHCP policy
  without polling packet descriptors.
- `software/r5/dma_status_jtag.tcl` reads interrupt/completion counters from
  non-cacheable DDR while R5 runs. These IRQ counters are incremented by the
  interrupt handlers, not by packet tasks. The RPU-local GIC itself is not
  readable through the PSU debug AP.

### Build and host verification

Commands used:

```sh
make -C software/r5 test
make -C software/r5 -j8 STATS_DDR=1 STATS_DEBUG=1
python3 scripts/verify_ip_flow.py \
  --vivado /tools/Xilinx/2026.1/Vivado/bin/vivado \
  --output build/cpu_irq/acceptance_2026 --implement
```

The host suite passed. The expanded DMA model's nine modes cover early,
delayed and premature interrupts; missing completion and missing interrupt;
descriptor errors; incompatible ABI; and errors on either DMA channel while
TX waits. It also checks concurrent ordinary/directed senders, descriptor
rotation, RX ring wrap, a full RX batch with a malformed first frame, W1C
acknowledgement, and exactly one ingress-tag pop per consumed descriptor.
The model asserts if the packet driver calls `vTaskDelay`. Final targeted DMA
checks and the ELF memory-layout checks passed after the last driver change.

The fresh FPGA acceptance flow passed all 13 gates, including 31 native and
31 packaged IP cases, all four counter configurations, production equivalence,
synthesis, routing, bitstream generation and routed physical/CDC audits.
Final setup WNS is **+0.018 ns**, hold WHS **+0.010 ns**, with zero failing
endpoints; 125 MHz fabric setup slack is **+1.710 ns**. DRC has no errors and
two `REQP-1935` advisories in the vendor AXI DMA FIFOs. An initial build picked
up Vivado 2024.1 from PATH and stopped during BD generation; the successful
fresh build explicitly used 2026.1 as shown above.

### Final-image hardware results

The following ran against the rebuilt bitstream and final ELF:

- Four concurrent streams of 500 full-size, DF-set pings to R5: **2,000/2,000**.
  A simultaneous full-size stream through the switch to the downstream device:
  **100/100**. No packet loss.
- HTTP concurrency: 120 mixed requests across six clients, maximum response
  21 ms; idle-client, authentication-rejection and overload-recovery checks
  passed, with administrator settings unchanged.
- SNMP readout succeeded. All implemented statistics banks remained fresh over
  61 samples/30 seconds and 120 polls, with no new faults, late polls or
  saturation. UART reported DHCP success and no fatal/DMA fault message.

| Non-cacheable DMA counter | Before traffic | After traffic |
| --- | ---: | ---: |
| TX interrupts | 11 | 3,992 |
| RX interrupts | 114 | 4,559 |
| TX completions | 11 | 3,992 |
| RX descriptors consumed | 114 | 4,616 |
| Error interrupts | 0 | 0 |
| Malformed RX descriptors | 0 | 0 |
| TX timeouts | 0 | 0 |

RX interrupt notifications may coalesce; the ring is drained independently of
the interrupt count. Both channel control registers read `0x00015003`, with
completion/error IRQ enables set. DMA error and timeout injection was covered
by host tests, not injected into the live forwarding setup. Disconnected
GEM/SFP ports were not exercised by this hardware run.

Artifacts are under ignored `build/cpu_irq/`: `tests.log`,
`dma_tests_final.log`, `firmware_final.log`, `acceptance_2026/results.json`,
`acceptance_2026/reports/`, and `deploy/` (JTAG/UART logs, IRQ snapshots, ping,
HTTP/SNMP/statistics results, unchanged configuration and `verification.json`).
The previous ELF is retained in `baseline/` and the deployed ELF in `deploy/`.

Deployed SHA-256 hashes:

- Bitstream (`acceptance_2026/project/kr260_switch.runs/impl_1/kr260_top.bit`):
  `45df14179d03242efee1deb1193497bca48291d538063b89c8b9f1cc7f20b589`
- R5 ELF (`software/r5/out/kr260_r5.elf`):
  `3bf20b16c48cb55558eef77638e08105d2ca8263f1a929318762525095f811ed`

## 2026-09-27 Fabric/management 2.1 board deployment (STP disabled)

Built the simulation-validated `build/rstp/acceptance/project/` through synthesis,
placement, routing and bitstream generation, then loaded that bitstream and the
matching all-counter R5 ELF through JTAG at `10.0.1.109:3121`. UART capture used
`10.0.1.109:2323`. This is a volatile JTAG deployment.

Routed setup WNS is **+0.018 ns**, hold WHS **+0.010 ns**, and 125 MHz fabric
intra-clock setup WNS **+1.710 ns**. Setup/hold TNS are zero. DRC has no errors
and only the two existing RAMB36E2 collision advisories. CDC retains 2,632 CDC-1
and two CDC-11 critical classifications; the destination/source-register groups
match the previous mailbox image, with no new critical groups. Existing bundled
mailbox-data/reset findings remain unwaived. Clock, RGMII-instance, MDIO/reset
and PL rate-control structural checks pass. Reports are in `build/rstp/reports/`.
Utilization: 30,982 LUTs, 39,769 registers, 51.5 BRAM tiles, zero URAM/DSPs.

Basic board verification:

- SD settings loaded unchanged; DHCP reacquired **10.0.1.104**. PL0 uplink and
  PL1 miner are both 1 Gb/s. GEM0, GEM1 and SFP are down, matching the baseline.
- STP stayed **disabled** throughout; selected protocol is RSTP, inherited by
  migration from the existing record. No configuration save or STP enable was
  performed. No BPDUs were transmitted. Protocol board tests are explicitly
  deferred at the user's request.
- Read-only JTAG confirms `STP_ABI=0x53545002` and forwarding/learning register
  `0x00000fff` (all six ports enabled, still subject to link admission).
- Simultaneous 1,472-byte-payload pings returned **99/100** from the R5 and
  **100/100** from the miner at `10.0.1.140`. The R5 missed sequence 64 during
  concurrent browser/statistics/SNMP/JTAG checks. A subsequent R5 run returned
  **200/200**; the isolated loss is not attributed to a proven cause.
- SNMP reads succeeded; the final snapshot reported no bad packets or AXI
  errors. A 30-second statistics observation advanced 119 polls without new
  faults, late polls or saturation; sensors remained valid.
- Live Chromium verified public configuration showing STP disabled, one-second
  statistics refresh, manual MAC-table refresh and IPv4 observations without
  JavaScript errors. The command-line cached MAC-table check also passed.

Build logs: `build/rstp/implementation.log`, `routed_review.log`. Deployment
logs, before/after configuration, UART, pings, statistics, SNMP and screenshots:
`build/rstp/deploy/`. Artifact SHA-256:

- Bitstream: `6ffcc424084a950f927612fab7f9e61c6e42802ebaddc57fc08be9bdccf0bf5f`
- R5 ELF: `3bedfd8ac7e221e67e877f15804ebb8e289f2f34b1309cd3363516642e79e111`

## 2026-09-27 Selectable STP/RSTP (source validation before deployment)

The partial classic-STP engine has been replaced by pinned `mstp-lib`, with
classic STP (version 0) and RSTP (version 2) selectable through authenticated
web configuration. Enable/version settings persist in v2 SD records; v1 records
load with spanning tree disabled and RSTP selected. See
[spanning-tree.md](spanning-tree.md) for protocol and hardware contracts.

Sanitized host tests pass for a three-bridge RSTP triangle, link failure and
recovery, transition-time loop checks, FDB flush callbacks, malformed BPDUs,
classic STP and mixed neighbors. Task tests pass for single-owner queued RX,
drop reporting, runtime enable/disable/version changes and fail-closed handling
of incompatible hardware. Configuration tests cover both protocols, record
migration, authorization and unavailable storage. Chromium tests pass for
enabling classic STP, selecting RSTP, disabling spanning tree, and existing
statistics/configuration/MAC-table behavior. The all-counter R5 ELF builds
and passes reserved-memory and non-cacheable DMA-region checks.

The all-counter RTL regression passes blocked ingress/control-frame delivery,
blocked destination filtering with directed CPU bypass, and saturation/recovery
of the 16-entry CPU ingress-tag FIFO with 17 ordered packets. The expanded
testbench uses 32 buffer slots and mirrors only completed DDR bursts; its former
16-slot memory model was too small for the added packet sequence.

Fresh IP catalog packaging, production block-design generation/audit, and all
31 IP cases in both native and packaged form pass. All four counter-build
regressions pass. The generated-production/native equivalence comparison passes
138,188 clock samples, 133 outputs and 257 snapshots. The complete acceptance
report is `build/rstp/acceptance/results.json`; this run did not request synthesis
or implementation.

Logs and generated artifacts are under `build/rstp/`: `tests.log`,
`config_tests.log`, `task_tests.log`, `all_firmware_tests.log`,
`browser.log`, `final_build.log`, and `rtl_check.log`. This source requires management/fabric
2.1 and a newly routed bitstream. Subsequent basic board deployment is recorded
above. Live redundant-link, cable-flap and independent STP/RSTP-peer tests remain
pending.

## 2026-09-27 Passive MAC-to-IPv4 discovery (deployed)

R5 firmware now observes ARP sender mappings and adds up to four IPv4
addresses plus observation ages to each web MAC-table row. The existing
FreeRTOS ARP cache supplies a fallback with an unknown observation age.
Hardware MAC dump format and manual-only refresh remain unchanged.

Host tests pass under AddressSanitizer/UndefinedBehaviorSanitizer for truncated
and malformed frames, request/reply learning, duplicates, timestamps, multiple
addresses, reassignment, expiry and bounded eviction. MAC web tests cover
unknown/cache fallback results and full 128-row pages with four addresses per
row within the 24 KiB response buffer. Web protocol tests pass in all four
statistics configurations. Chromium tests pass for multiple addresses, unknown
values, observation ages, navigation and no automatic hardware scans.

The all-counter R5 ELF builds and passes memory-layout checks. Logs:
`build/r5/ip_discovery_tests.log`, `ip_discovery_browser.log` and
`ip_discovery_build.log`.

Deployed over JTAG on 2026-09-27 using the station at `10.0.1.109:3121`
(UART `10.0.1.109:2323`; the previously used `.107` was unreachable). The
existing verified ABI-2 bitstream was reused with the new R5 ELF. Saved SD
settings loaded, DHCP reacquired `10.0.1.104`, and physical/forwarding masks
returned to `0x0e` (GEM1 100 Mb/s; PL0/PL1 1 Gb/s).

The live browser passed IPv4/observation-age rendering, unknown entries,
manual-only refresh and JavaScript-error checks. One hardware dump captured
34 MAC rows, with 13 MAC-to-IP mappings observed in the subsequent API read,
including `02:00:00:10:04:00` → `10.0.1.140` on PL1 and the workstation
at `10.0.1.24` on PL0. The updated command-line MAC-table checker passed.
Deployment logs, snapshots and screenshot are in
`build/r5/ip_discovery_deploy/`. R5 ELF SHA-256:
`7747b2eb35d7b558e72f867caa37d5e60f68e9c8fb671b442da1b12bd8ab91a4`.
Both CPU and forwarded-miner destinations passed 100/100 full-size pings
(1,472-byte ICMP payload). All 13 statistics banks stayed fresh over 30 seconds
and 120 polls, with no new faults, late polls or saturation. Port settings
matched the pre-deployment values. Deployment remains volatile JTAG.

## 2026-09-26 Independent statistics-bank mailboxes (deployed)

Statistics ABI 2 (`0x53540200` plus capability bits) replaces the single
outstanding read with thirteen independent source transactions. A stopped bank
retains its slot, request and captured result while other banks continue. A
registered Gray progress counter identifies lack of source progress, including
a held source reset. R5 reports stale-bank age and clock-unavailable episodes
separately from active-clock faults through SNMP table 7 and the public web page.
Firmware has no software BUSY loop and retries unavailable banks every 250 ms.

Focused management simulations pass at both the original test clock and a
2.5 MHz source with the production 4,095-cycle deadline. They cover stopped
clock before request, attempts to retarget the pending slot, healthy-bank
collection while another is stopped, recovery without duplicate/lost counts,
and a clock stopping after capture with ACK release still blocked. AXI response
backpressure, saturation, simultaneous increment/clear, all 256 indices and
optional-counter configurations remain covered.

R5 tests pass in all four counter configurations, including startup with a
captured hardware result, five consecutive unavailable polls, active-clock
release/response fault attribution and exact accumulation through recovery.
SNMP tests validate new health values and complete sorted walks. Net-SNMP parses
the updated MIB. Browser tests pass with the new stale-bank status table and
existing one-second refresh. The all-counter R5 firmware builds and passes ELF
memory-region checks. Standalone management-IP synthesis passes (784 LUTs,
981 registers for the entire management IP, not whole-board utilization).

Fresh catalog and production BD generation, source/interface-width checks, and
31 native plus 31 packaged IP tests pass. Whole-switch regressions pass in
all four counter configurations. Generated production/native datapath comparison
also passes (133 outputs and 257 statistics requests). All eleven acceptance
gates pass. Artifacts are in
`build/ip_refactor/mailboxes_final/`; firmware/browser/MIB and management-synthesis
logs use the `build/ip_refactor/mailboxes_*` prefix.

Full-board synthesis, place-and-route and bitstream generation pass. The
all-counter R5 ELF was rebuilt and deployed with the matching image over JTAG
using `10.0.1.107:3121`. The SD configuration loaded and DHCP reacquired
`10.0.1.104`. Hardware and firmware both report ABI/capabilities `0x53540207`.
GEM1 links at 100 Mb/s to the isolated endpoint; PL0 uplink and PL1 miner link
at 1 Gb/s. This remains a volatile JTAG deployment.

Routed results (`build/ip_refactor/mailboxes_final/reports/`):

| Check | Result |
| --- | --- |
| Overall setup / hold | +0.018 / +0.010 ns; TNS and THS zero |
| Fabric 125 MHz setup | +1.236 ns |
| PL0 TX to forwarded TX clock | +0.018 ns (worst setup path family) |
| PL1 TX to forwarded TX clock | +0.053 ns |
| Bus skew | All 31 checks pass; minimum margin +5.802 ns |
| Resources | 30,848 LUTs; 39,769 registers; 51.5 BRAM tiles |
| Bitstream generation | Zero errors and critical warnings |

CDC review is not a blanket clean report. Compared with the prior PL multirate
image, CDC-10 falls from 13 to zero and CDC-12 from eight to zero. Existing
2,632 CDC-1 held bundled-data classifications and two CDC-11 reset fan-out
classifications remain. The 13 additional CDC-6 warnings correspond to the new
registered four-bit Gray progress buses with two-stage ASYNC_REG synchronizers.
Their worst routed datapath is 0.707 ns, within the 7 ns constraint and fastest
8 ns source period. Select, request, snapshot-data and acknowledgement families
all have positive constrained slack (minimum 3.386 ns). The select/result
stability protocol was reviewed with the request/ACK sequencing. External
MDIO/RGMII timing budgets and reset fan-out remain backlog items.
`ip_repo/review_timing_cdc.tcl` now reports the independent-mailbox paths.

The bitstream SHA-256 is
`c31ffd3d17cbdc87a36d4360dfec56aefff5f0a69243cdd7a8dbcdc827b758f0`;
the R5 ELF SHA-256 is
`6495c808de155d77675dead3a2999e05df6dede51596963338f49372d66f89c3`.
Both are recorded in `build/ip_refactor/mailboxes_final/artifacts.sha256`.

Board qualification uses `scripts/check_statistics_banks.py`, a read-only
HTTP monitor that checks bank freshness, unavailable states, collector progress,
and fault/late-poll/saturation deltas. For example:

```sh
python3 scripts/check_statistics_banks.py 10.0.1.104 --source 10.0.1.24 \
  --seconds 60 --unavailable-bank 2 --output /tmp/stopped-banks.jsonl
```

Omit `--unavailable-bank` when all implemented banks should be fresh. The
checker does not change PHY state or read destructive hardware counters.

Live board checks passed:

- Linked baseline: 30 seconds / 120 collector polls; all 13 banks fresh.
  100/100 full-size pings each to the R5 and forwarded miner.
- Controlled GEM1 PHY power-down: PHY 9 BMCR changed from `0x1000` to
  `0x1800`, with the R5 briefly stopped at the link task's MDIO entry to avoid
  concurrent MDIO access, then resumed. This is volatile and leaves SD settings
  unchanged. The [DP83867 datasheet](https://www.ti.com/lit/ds/symlink/dp83867cs.pdf)
  documents BMCR power-down with MDIO access retained. Bank 2 reported no source
  progress, state 2 and one unavailable episode; its stale age advanced from
  20.449 to 80.448 seconds during the monitored window. All other banks stayed
  fresh through 60 seconds / 240 polls, with no new active-clock faults,
  saturation or late polls. R5 and miner each answered 250/250 full-size pings.
- Restored original BMCR plus autonegotiation restart: register settled back
  to `0x1000`, GEM1 recovered at 100 Mb/s and bank 2 returned to current state
  without a reboot. The recovery monitor passed 30 seconds / 120 polls with all
  13 banks fresh; unavailable episode count remains one and active-clock
  timeout count remains zero. Both destinations answered
  another 100/100 full-size pings after recovery.
- Live SNMP walks showed the new bank-health rows in stopped and recovered
  states. Chromium showed 13 bank rows with one-second refresh and no JavaScript
  errors while GEM1 was unavailable. HTTP concurrency passed 120 mixed requests
  from six clients, service alongside two idle clients, authentication rejection
  isolation and overload recovery. Port configuration matched its pre-test state.

Across the three traffic windows, both destinations answered 450/450 full-size
pings (1,472-byte ICMP payload). Debugger halt/PHY transitions were excluded
from these traffic windows. Each debugger pause caused one late-poll increment
(two total); no late polls occurred during the steady-state observation windows.
Snapshot-response and release timeout counters remain zero. Exact destructive
counter retention around every request/ACK phase is simulation coverage, not
proven by these live traffic measurements. The controlled power-down establishes
stopped-clock isolation/recovery, not the cause of every historical cable-unplug
timeout. Broader cable-flap, independent-reset and saturated-load testing remain.
Logs and JSON captures are under `build/ip_refactor/mailboxes_final/`.

Independent source resets during a destructive read still require coordinated
recovery; this change specifically handles stopped/resumed clocks.
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

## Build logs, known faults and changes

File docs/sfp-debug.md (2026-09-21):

# SFP hardware investigation (2026-09-20)

The module fitted after the four-copper-port test is an Ipolex ASF-GE-T,
1000BASE-T RJ45 SFP. Its EEPROM at I2C address `0x50` identifies vendor `OEM`
and part `SFP-GE-T`. The PHY at `0x56` returns ID words `0x0141:0x0cc1`.
EEPROM and PHY reads through the PL AXI IIC at `0x80030000` work on hardware.
The identification transactions only select register offsets and read data;
no EEPROM contents were programmed. `software/r5/sfp_status_jtag.tcl` repeats
these reads without stopping R5; the current firmware leaves the IIC core
unused, so it is available exclusively to the diagnostic script.

[Ipolex's datasheet](https://m.media-amazon.com/images/I/91ze2PnD7DL.pdf)
lists ASF-GE-T as the 1000 Mb/s SERDES variant, distinct from the SGMII
multirate variants. Its TX_DISABLE resets the module, TX_FAULT is tied low,
and LOS can be tied low. Consequently, SFP_STATUS=0 proves presence and
that the host permits operation, but does not establish a working link.

## Initial evidence

The running copper-test image reports SFP_STATUS=0, PCS_STATUS=0 and
LINK_STATUS=0x20. Firmware leaves only CPU port 5 enabled because neither
PCS synchronization nor negotiation link is asserted. Both PL PHYs report
link down and the R5 timers continue advancing. This failure precedes DHCP. PHY status `0xbc00` indicates resolved 1 Gb/s
full duplex on the copper side. Register 27 is `0x8088`: mode 8 corresponds
to copper-to-1000BASE-X with negotiation, consistent with the
[Linux Marvell PHY driver definitions](https://github.com/torvalds/linux/blob/master/drivers/net/phy/marvell.c).

## Confirmed receive-status wiring defect

The GTH wrapper incorrectly used RXCTRL2 as RXCHARISK and RXCTRL0 as
RXDISPERR. According to [AMD UG576, RX 8B/10B decoder ports, Table 4-27](https://docs.amd.com/api/khub/documents/X8hVhAx~JVBkxiZRAjsdRg/content):

| GTH output | Meaning | Correct PCS destination |
| --- | --- | --- |
| RXCTRL0 | K/control-character indication | `rxcharisk_o` |
| RXCTRL1 | Disparity error | `rxdisperr_o` |
| RXCTRL2 | Comma indication | Unused by wrapper |
| RXCTRL3 | Invalid code | `rxnotintable_o` |

The old mapping falsely reports control characters as errors and fails to
identify non-comma K characters. `gth_sfp_wrapper.sv` now uses the documented
mapping. `make -C sim sim-gth-rx-mapping` tests all combinations of K,
disparity, comma and invalid flags on both byte lanes using the actual wrapper
and an interface stub. It fails on the old RTL and passes on the correction.
This is a wiring regression, not an analog transceiver model. Existing PCS
and SFP port simulations also pass; their previous behavioral models bypassed
the synthesis wrapper and therefore could not catch this defect.

A routed-checkpoint ECO changed only the two receive-status connections per
byte lane, then rerouted and produced `build/gem1_debug/sfp_mapping.bit`.
Setup/hold slack remains +0.018/+0.010 ns under existing constraints. The
corrected image was loaded through volatile JTAG; no flash was written.
PCS_STATUS remains zero, so this confirmed bug is not the only blocker.

## Additional instrumentation

`build/debug_sfp.tcl` builds two ILAs from a fully linked synthesis checkpoint
with implementation constraints and regenerated option-2 GTH IP. It also binds the two PCS receive-status
register inputs to the corrected GTH outputs, supporting the earlier local
checkpoint. Outputs are under ignored `build/gem1_debug/sfp/`.

- `ila_sfp_status`: 50 MHz always-running clock, 1024 samples. GTH power-good,
  CPLL lock/reference loss, TX/RX reset done, PMA reset done, byte alignment,
  comma detect, GT reset inputs, SFP MMCM lock and wrapper reset release.
  The fresh build additionally probes CPLL reset/power-down, TX/RX user-ready
  and TXOUTCLK selection.
  Negotiation state, transmitted ability/ACK and restart/link timers are also
  captured. Asynchronous status samples are diagnostic snapshots, not timing evidence.
- `ila_sfp_data`: GTH 62.5 MHz user clock, 2048 samples. RX data, K/disparity/
  invalid flags, RX buffer status, TX data/K flags and comma indications.

`build/capture_sfp.tcl` snapshots both cores on a running board. A stopped
GTH clock may prevent the data capture; the independent status core can
still identify reset/clock problems. The script restores the JTAG frequency
on completion or failure.

## Clock/reset capture

The SFP ILAs confirm GTH power-good and CPLL lock are asserted, but TX/RX
RESETDONE are zero, RX PMA reset is incomplete, GTRXRESET is high, the SFP
MMCM is unlocked and the wrapper remains in reset. Hardware Manager reports
the data ILA's GTH user clock stopped. The 50 MHz status capture contains
1024 consistent samples. This identifies a startup failure before symbol
reception, not evidence of a receive-buffer overflow.

The generated IP for `ENABLE_COMMON_USRCLK=1` selects RXOUTCLK for **both**
user-clock networks (`C_TX_USER_CLOCKING_SOURCE=2`, RX source 0). Both networks
also use the RX PMA reset-done qualifier. The reset controller waits for TX
startup before releasing RX, leaving TX without its required user clock.
The old wrapper comment incorrectly described option 1 as TX-derived.

Regenerating the IP with `ENABLE_COMMON_USRCLK=2` selects TXOUTCLK for both
networks (TX source 0, RX source 2), with TX PMA reset-done qualifying clock
release. The repository XCI source has been updated from the Wizard-generated
configuration. The first in-place clock ECO failed routing validation and was not loaded.
A subsequent fully routed topology experiment passed DRC and setup/hold
(+0.018/+0.011 ns), but its hardware capture still showed stopped clocks,
with both GT resets asserted. This experiment did not establish successful
startup. The debug flow now requires a freshly synthesized, regenerated
Wizard configuration rather than approximating its clock/reset/calibration
connections through checkpoint rewiring. A top-level re-synthesis initially
reused the old `gth_sfp_ip.dcp` even after `generate_target all`; netlist tracing
confirmed both user BUFGs still used RXOUTCLK. Explicitly reset and run
`gth_sfp_ip_synth_1` when changing this IP. The debug script now rejects an
input checkpoint with no user-clock load driven by TXOUTCLK. The original copper-test image is
preserved under ignored `build/gem1_debug/copper_passing/`.

The CPLL reference-loss probe reads high but its lock-detection reference-clock
input was not configured for that monitor; UG576 requires CPLLLOCKDETCLK for
valid reference-loss indication. Do not interpret this probe as proof that
the board oscillator is missing; CPLLLOCK is high.

## Startup verified; gearbox correction

After explicitly rebuilding the GTH synthesis run, the hardware capture shows
TX/RX reset done and PMA reset done high, TX/RX user-ready high, MMCM locked,
wrapper reset released, and RX byte alignment established. Both ILAs capture.
The image meets setup/hold at +0.018/+0.010 ns under the existing constraints.

The raw RX stream contains valid `/C1/` and `/C2/` words advertising `0x4020`
(full duplex, ACK set), without disparity or invalid-code errors. RX buffer
status is zero in this capture. Our transmitter still advertises `0x0020`;
PCS_STATUS is `1` (synchronized, negotiation incomplete), and 10 pings receive
no replies. This narrows the next blocker to the digital PCS rather than the
module's copper link or GTH startup.

The PCS test originally selected a favorable clock phase and explicitly
avoided coincident edges. At a coincident edge, the RX word register can
change between reading its low and high bytes, reversing/mixing the symbol
sequence presented to negotiation. The old RTL reproduces hardware's symptom:
sync succeeds, negotiation times out, and packet tests receive no data.

The corrected gearbox commits complete TX words and retains the corresponding
RX high byte when consuming a low byte. `sim-sfp-pcs-phases` checks negotiation,
packet contents, error propagation and resynchronization at four clock phases
(4, 8, 12 and 16 ns first GTH edges) and both receive byte alignments.
All eight cases pass; the old RTL fails the first phase. The SFP port, two-partner negotiation and switch tests also pass.
These remain related-clock transfers requiring setup/hold closure.

For the next hardware image, the board supplies 10 ms restart and 10 ms
acknowledgement/idle timers at 125 MHz through newly exposed SFP/switch
parameters. The prior source comment confused this with the 1.6 ms SGMII
link timer; [AMD PG047 describes the distinction](https://docs.amd.com/r/en-US/pg047-gig-eth-pcs-pma/Using-the-SGMII-MAC-Mode-to-Interface-to-an-External-BASE-T-PHY-with-SGMII-Interface).
Generic module defaults remain short for simulation. The regenerated
GTH configuration enables clock correction on `/I2/` (K28.5,D16.2) and the
`/C1/` prefix (K28.5,D21.5), with a full RX buffer and comma-alignment reset.
These sequences follow [AMD PG047](https://docs.amd.com/r/16.2-English/pg047-gig-eth-pcs-pma/Clock-Correction-Sequences-in-Device-Specific-Transceivers).
`sim-autoneg-clock-correction` verifies that fragments alone do not negotiate,
and intact configurations still complete negotiation amid inserted/deleted
prefixes. Sustained frequency-offset operation and buffer-error recovery
remain to be validated. The gearbox/timer/correction image established link
(PCS_STATUS=7, LINK_STATUS=0x30) after a module restart, but DHCP still failed.

## Receive preamble and negotiation restart corrections

With link established, the SFP MAC counted 381 received frames and 402 FCS
errors. A GTH capture contained a complete incoming frame with a valid FCS
(`0xe1222695`), but only five preamble bytes after `/S/`, followed by the SFD.
The old receiver assumed six bytes and synthesized an SFD: it consumed the
actual SFD as preamble and discarded the first destination-address byte.
[AMD PG047 documents this permitted preamble shrinkage](https://docs.amd.com/r/en-US/pg047-gig-eth-pcs-pma/Preamble-Shrinkage).

`gmii_1000base_x_rx.sv` now forwards the received preamble and transitions on
the actual SFD. `sim-sfp-rx-preamble` checks every byte and FCS of a synthetic
frame with both five and six post-`/S/` preamble bytes. The old RTL fails the
shortened case; the corrected RTL passes both.

Negotiation also accepted an all-zero restart configuration as an ability,
and advertised its normal ability during its own restart interval. The FSM
now transmits zero during restart, advertises its ability after the restart
timer, rejects zero as an ability and restarts if zero arrives while waiting
for acknowledgement. The clock-correction regression now checks this case:
the old RTL incorrectly acknowledges zero; the new RTL does not.

The PCS phase matrix, SFP port, two-peer negotiation and switch regressions
pass with both corrections. The image meets setup/hold at +0.016/+0.010 ns.
A fresh JTAG boot negotiates automatically without manually resetting the
module: PCS_STATUS=7, LINK_STATUS=0x30. The first MAC snapshot has 195 good
received frames and zero FCS errors. Incoming network frames also appear
correctly in R5 DMA buffers. DHCP still fails.

## Transmit ordered-set alignment

A subsequent GTH capture contains a 318-byte DHCP Discover (including FCS)
with valid CRC `0x52f19a99`. However, the TX state machine can start `/S/`
in the odd position, interrupting an idle ordered set, and always appends
one `/R/` regardless of the termination position. Its previous comments
incorrectly described these choices as harmless simplifications.

The transmitter now completes an idle pair before starting `/S/`, discarding
one preamble byte on an odd GMII start. It preserves even/odd parity through
the frame and emits one or two `/R/` symbols to restore an even-position
idle comma. See AMD PG047's [start encoding](https://docs.amd.com/r/en-US/pg047-gig-eth-pcs-pma/The-Odd-Transmission-Case?contentId=FMfrN19njQuZUaeW~MZ6Bw)
and [end encoding](https://docs.amd.com/r/en-US/pg047-gig-eth-pcs-pma/The-Odd-Transmission-Case).
`sim-sfp-tx-alignment` checks both GMII start phases and both frame-length
parities, including payload preservation. The old RTL fails the alignment
check; the correction passes. The PCS phase matrix accepts only the two
legal preamble lengths and still compares packet contents exactly. PCS,
SFP port, two-peer negotiation and switch regressions pass.

The alignment-only build was stopped before programming to incorporate
idle-disparity selection. Reading the module's fiber register bank twice
showed BMSR `0x0149`, partner advertisement `0x4020` and PHY status `0xa410`.
The page selector was restored to zero after each diagnostic read. These
were initially interpreted as incomplete serial-side negotiation, but the
same values persist while DHCP and ping work. Do not use these fiber-bank
bits as a link-admission criterion in this module's SFP converter mode.

The GTH word output now tracks 8b/10b running disparity across both AN and
frame symbols. It replaces an `/I2/` candidate with `/I1/` when the preceding
comma started at positive disparity, returning subsequent idles to negative
disparity. The test `sim-sfp-tx-idle` uses canonical subcode tables and bit
population counts as an independent oracle: all 256 data values, AN-like
words and both idle word alignments pass, exercising 244 `/I1/` and 268 `/I2/`
selections. The old output stage fails this test. Existing PCS/port/AN/switch
tests also pass.

## Hardware traffic result

The first combined image remained synchronized but exchanged zero restart
configurations; a module TX_DISABLE restart did not recover it. A subsequent
build adds state, advertisement and restart/link timer probes to the status
ILA. This image meets setup/hold at +0.018/+0.012 ns after the same 900 ps
PL0 IDELAY override used for the copper milestone. It boots, negotiates and
acquires DHCP address `10.0.1.214` automatically through the SFP.

The status capture shows `S_LINK_OK`, transmitted full-duplex ability and ACK,
and both timers stopped at `0x001312d0` (1,250,000 cycles). Raw RX/TX idles
are correctly paired, with no sampled decoder errors and RX buffer status
zero. Initial ping runs lost 19/20 small packets and 6/20 full-MTU packets;
a later settled-link test passed 60/60 small and 30/30 full-MTU pings.
The cause of the initial losses is not established. Do not infer managed
switch forwarding delay without its port state/configuration.

The managed-switch operator observed its cumulative RX-error count move
from 802 to 803 during bring-up. The operator subsequently confirmed that
the counter remained at 803, with no further increments since the previous
check. This is an operator observation without a timed soak interval.
The KR260 MAC accumulated one RX FCS/error
count among 1,325 accepted frames, with no overflow, during the first run.
That counter combines CRC failure, GMII RX error and short frames; it is
not a pure CRC-only measurement. Sustained error-free operation and reliable
startup across implementations remain open checks. The additional probes
change placement; success of the instrumented image does not explain the
previous image's restart loop.

A second fresh JTAG boot of the instrumented image again acquired
`10.0.1.214`. Its small-ping run received 50/60: sequence 1 worked, 2–11 were
lost, and 12–60 all worked. The following full-MTU test passed 30/30. At the
end, PCS_STATUS=7 and LINK_STATUS=0x30; MAC counters showed 653 accepted RX
frames, zero RX FCS/error counts, zero overflow, and 129 TX frames. No manual
module reset was needed on either successful boot. The board is left running
this image; persistent boot flash was not modified.

Local ignored evidence is under `build/gem1_debug/sfp/`: `an_debug_uart.log`,
`reboot_uart.log`, `pass_ping_settled.log`, `pass_ping_large_settled.log`,
`reboot_ping_small.log`, `reboot_ping_large.log`, `pass_mac_final.log`,
`reboot_mac_final.log`, ILA CSVs and timing/DRC reports. The matching bitstream,
probes and routed checkpoint are preserved under `basic_connectivity/`.
The source, tests, debug scripts and documentation are recorded in the
`20260920-all_ports_passing_dhcp_ping` milestone. Generated hardware artifacts
and raw captures remain local and ignored.

## Rebuilding after changing the GTH XCI

`generate_target all` alone did not refresh the local out-of-context GTH
checkpoint during this investigation. In an existing project, explicitly
rebuild that run before linking the board synthesis result:

```tcl
open_project build/vivado_kr260/kr260_switch.xpr
set_property CONFIG.ENABLE_COMMON_USRCLK 2 [get_ips gth_sfp_ip]
set_property CONFIG.RX_EQ_MODE LPM [get_ips gth_sfp_ip]
generate_target all [get_ips gth_sfp_ip]
reset_run gth_sfp_ip_synth_1
launch_runs gth_sfp_ip_synth_1 -jobs 8
wait_on_run gth_sfp_ip_synth_1
```

Re-synthesize the board when RTL has changed. Open the board synthesis run,
read the implementation-only clock and RGMII constraints, and write a linked
checkpoint for `build/debug_sfp.tcl`. It verifies TXOUTCLK drives the user
clock helper before adding the ILAs. Use the resulting matching `.bit` and
`.ltx` files for programming and capture. The normal clean-project build
imports the repository XCI; this caveat concerns reuse of the local project.

## Intermittent packet loss with an attached endpoint

After the milestone, the operator reported a stall followed by spontaneous
recovery. The SFP remained the uplink and right-upper GEM0 connected to endpoint
`10.0.1.140`, not to the same managed switch. The CPU retained `10.0.1.214`.
R5 tick/timestamp counters advanced, DMA showed no errors, and GEM0 reported
no TX underrun, RX FCS error or RX overrun. Both links stayed active
(`LINK_STATUS=0x31`, `PCS_STATUS=7`).

Small CPU pings passed 120/120, but full-MTU loss varied widely: separate
CPU runs received 2/30, 149/150, 137/180 and 180/300. The forwarded endpoint
received 11/30 full-MTU pings. The SFP MAC RX error counter increased while
its overflow counter remained zero. This is evidence of intermittent receive
corruption rather than a confirmed processor or fabric hang.

Raw GTH ILA captures caught expected payload byte `0x73` decoded as `0x93`,
with RXCHARISK, RXDISPERR and RXNOTINTABLE asserted on that byte. It occurred
in both low and high byte lanes in separate captures. RXBUFSTATUS stayed
zero throughout those corrupt captures. Other captures contained complete
1518-byte ICMP requests with valid CRCs. Thus at least part of the loss
originates at the serial receiver/decoder, before PCS frame parsing.

The Wizard's previous `RX_EQ_MODE=AUTO`, with a 20 dB insertion-loss
assumption, generated DFE mode (`RXLPMEN=0`).
[AMD UG576, RX equalizer](https://docs.amd.com/v/u/en-US/ug576-ultrascale-gth-transceivers)
recommends LPM for low-loss channels and repetitive, unscrambled 8b/10b
traffic; DFE automatic adaptation can drift with repeated patterns. This is
a candidate explanation for the observed corruption and self-recovery,
not a direct measurement of the equalizer's internal state.

The repository XCI now explicitly selects `RX_EQ_MODE=LPM`. Comparing
Wizard-generated primitive configurations produces exactly these differences:

| Setting | Previous DFE | LPM |
| --- | --- | --- |
| RXLPMEN | 0 | 1 |
| RX_SUM_IREF_TUNE | 0x9 | 0x4 |
| RX_SUM_VCMTUNE | 0xa | 0x6 |

Local evidence is under `build/gem1_debug/stall_investigation/`.
In particular, `rx_aligned_1.csv` and `rx_aligned_2.csv` contain the decoder
faults; `lpm_delta.json` records the Wizard attribute comparison.
The previous image/checkpoint/probes are preserved under `pre_lpm/`.

### Test-host ARP ambiguity

The test workstation has Ethernet `10.0.1.24` (MAC
`c8:ff:bf:0f:6e:4f`) and Wi-Fi `10.0.1.14` (MAC
`88:f4:da:9f:ec:b4`) on the same subnet. With LPM loaded,
`ping -I eth1` to the endpoint initially received 0/300 despite no MAC
errors. Five raw SFP TX captures showed complete, CRC-valid ICMP echo replies
from `10.0.1.140` to `10.0.1.24`, addressed to the workstation's
**Wi-Fi MAC**. These are in `build/gem1_debug/lpm/endpoint_tx_*.csv`.

The host has `arp_ignore=0` on both interfaces and globally, permitting
ARP replies for an address on another interface, as described in the
[Linux IP sysctl documentation](https://kernel.org/doc/html/latest/networking/ip-sysctl.html).
An interface-bound ping can miss replies arriving through the other interface.
Repeating the test without `-I eth1` restores responses; route lookup still
selects Ethernet and source `10.0.1.24` for outgoing requests.
No host network configuration was changed. Earlier interface-bound loss
figures are therefore not reliable measures of FPGA packet loss by
themselves. The independently captured GTH decoder errors remain valid evidence.

### LPM implementation and hardware validation

For a controlled comparison, the first LPM debug image applies precisely the
three Wizard-generated differences above to the preserved routed checkpoint.
RXLPMEN is tied to the same constant-one net as RX8B10BEN. This retains the
existing logic, probes and 900 ps PL0 IDELAY override. Routing and bitstream
DRC passed; setup/hold slack remains +0.018/+0.012 ns. The existing project's
GTH output products and OOC synthesis checkpoint were also regenerated with
LPM explicitly selected.

The LPM image is `build/gem1_debug/lpm/sfp_lpm.bit`, with matching
`sfp_lpm.ltx` and `routed.dcp`. It was loaded using
`software/r5/boot_jtag.tcl`, resetting the receiver and PS through the normal
volatile bring-up sequence. DHCP acquired `10.0.1.214` automatically;
GEM0 and SFP subsequently reported link up (`0x31`).
The first CPU test received 276/300 full-MTU pings: only sequences 2–25 were
lost, with all 26–300 received. This initial interruption remains unexplained.
The next CPU test with full-MTU repeated `0x73` payload passed 300/300.

The unbound endpoint test passed 300/300 full-MTU pings. After at least
60 seconds without generated ping traffic (ordinary LAN background traffic
remained), another simultaneous pair of tests passed 300/300 to the CPU
with the default payload and 300/300 to the endpoint with repeated
`0x00` payload. Thus the settled tests received 600/600 full-MTU replies
from each address, across two payload patterns per target.

Final SFP counters were 5,687 accepted RX frames, zero RX FCS/error counts,
zero overflow and 2,836 TX frames. PCS_STATUS remained 7 and LINK_STATUS
0x31. R5 timers continued advancing at the expected rates and DMA status
showed no errors. Logs are in `build/gem1_debug/lpm/`:
`cpu_large.log`, `cpu_pattern73.log`, `endpoint_unbound.log`,
`cpu_after_idle.log`, `endpoint_after_idle.log`, `mac_final.log`,
`status_final.log` and `uart.log`.

These results support keeping LPM for this module/channel and traffic pattern.
They do not prove DFE adaptation was the sole cause of all prior losses,
nor establish long-duration reliability or explain the brief initial
interruption. The board is left running LPM; persistent boot flash is unchanged.

## Debug instrumentation removed (2026-09-21)

The normal project was rebuilt with LPM and ingress-port exclusion on
destination lookup hits, without inserting ILAs or a debug hub. It was
loaded and passed DHCP plus 300/300 full-MTU pings to each of the CPU and
GEM0 endpoint, with zero SFP MAC receive errors. This supersedes the running
LPM debug image above. See [normal-image validation](verification.md#normal-image-without-debug-ilas-2026-09-21).
Historical debug scripts, images and captures remain available for reference.

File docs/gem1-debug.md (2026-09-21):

# GEM1 transmit ILA bring-up

The development KR260 is at `10.0.1.109:3121` (hardware server), with its
UART telnet bridge at `10.0.1.109:2323`. The DHCP network connects to the
**lower-right Ethernet connector**, identified during bring-up as GEM1,
DP83867 MDIO address 9 on GEM1's shared management bus.

The initial firmware received packets through GEM1 and virtual CPU port 5,
but TX underruns blocked DHCP. ILA captures isolated two faults; correcting
them enabled DHCP acquisition and ping. MM2S descriptor completion alone only
proves delivery to the fabric.

## Instrumentation

`build/debug_gem1.tcl` adds two ILAs to the existing synthesized design,
without adding RTL probe ports or rebuilding the PS block design. It
places/routes a separate image under ignored `build/gem1_debug/` and produces
`kr260_gem1.bit`, `kr260_gem1.ltx`, timing/DRC reports and checkpoints.
The debug hub uses the continuous PS 50 MHz clock. Probe inputs have one
pipeline stage; all signals within each ILA are sampled in their own domain.

| ILA | Clock | Depth | Signals |
| --- | --- | --- | --- |
| `ila_gem1_tx` | GEM1 TX FIFO clock | 8192 | GEM read, valid, SOP, EOP, data-ready, underflow, flushed, completion/ack toggles, byte data, four GEM status bits, XPM FIFO empty, high-byte pending, SOP state, 18-bit FIFO head, FIFO reset-busy and pending-read state |
| `ila_gem1_feed` | 100 MHz fabric clock | 2048 | 18-bit FIFO write data (`EOP`, upper-byte keep, 16-bit data), accepted write enable, FIFO full |

The transmit status outputs were previously unused and optimized out. The
script attaches their PS8 output pins to probe nets. No recovery behavior is
added by the instrumentation. Net names are checked explicitly; if synthesis
changes them, update the probe bindings rather than silently omitting probes.

## Build and capture

From the repository root, after the normal board synthesis and R5 build:

```sh
/tools/Xilinx/2026.1/Vivado/bin/vivado -mode batch -source build/debug_gem1.tcl \
  -log build/gem1_debug/build.log -nojournal
/tools/Xilinx/2026.1/Vitis/bin/xsdb software/r5/boot_jtag.tcl \
  tcp:10.0.1.109:3121 build/gem1_debug/kr260_gem1.bit halt
/tools/Xilinx/2026.1/Vivado/bin/vivado -mode batch -source build/capture_gem1.tcl \
  -log build/gem1_debug/capture.log -nojournal
```

Create `build/gem1_debug` before using it as Vivado's log directory. The boot
command resets the PS, runs the FSBL, programs the debug image, and leaves
R5-0 halted at entry. The capture script arms the fabric ILA on its first
accepted write and the GEM ILA on its first SOP, then starts R5-0. Both captures
retain 128 pre-trigger samples. It exports CSV and native ILA files for analysis.
The separate clock domains have independent sample indices; align them using
packet contents/events, not equal row numbers.

Inspect the byte stream accepted by GEM, its SOP/EOP positions, the first
underflow/status event, FIFO empty and flush/ack behavior. Compare transmitted
bytes against the packet entering the FIFO. This distinguishes input starvation,
byte/framing corruption, and an error occurring despite data availability.

## Captures and regression

The first two captures used identical PL logic and bitstream. Only
`IOU_SLCR.GEM_CLK_CTRL` differed:

| Observation | Original clock select (`0x006`) | PL-loopback clock select (`0x10e`) |
| --- | --- | --- |
| FIFO input / GEM response bytes | 314 / 314, identical | 314 / 314, identical |
| SOP / EOP sample | 128 / 441 | 128 / 449 |
| PL underflow sample | None | 450, immediately after EOP |
| PL flushed sample | None | 451 |
| GEM status | No transition | `0x8` at sample 458, cleared at 461 |
| Completion / acknowledgement toggle | Neither | Samples 458 / 459 |

The original clock configuration did not select the TX FIFO clock returned
through the PL BUFG, despite the generated PS wrapper connecting that return
clock. Firmware now sets GEM0/GEM1 FIFO clock selects (bits 3/8 at `0xff180308`)
while both MACs are disabled, preserving all other register bits. See
[AMD GEM_CLK_CTRL](https://docs.amd.com/r/en-US/ug1087-zynq-ultrascale-registers/GEM_CLK_CTRL-IOU_SLCR-Register).

With the clocks aligned, the capture shows an additional GEM read on the cycle
after EOP. The old adapter unconditionally reported an empty-FIFO read as an
underrun, even between frames. This asserts an error after the complete packet
has been supplied. The adapter now retains a boundary read until the next
permitted frame arrives; only emptiness after SOP is a mid-frame underrun.

A new regression sends a 314-byte frame followed by the observed trailing
read, waits with an empty FIFO, then sends a 17-byte frame. It verifies no
spurious underrun/flush and that the pending read receives exactly the next
SOP byte before further requests. The old RTL fails three checks; the updated
RTL passes the bridge and egress integration suites with both portable and
AMD XPM FIFO models. Existing mid-frame starvation/flush recovery also passes.

`python3 build/analyze_gem1.py [capture_directory]` compares the two captured
byte streams and reports framing, underflow, FIFO emptiness and status events.
Raw baseline captures and summaries are in ignored
`build/gem1_debug/baseline/` and `build/gem1_debug/clock_only/`.

## Corrected hardware result

With the pending-read RTL and loopback clock selection, the first DHCP
transmit capture contains 314 input/output bytes, identical byte for byte.
SOP/EOP occur at samples 128/449, with no underflow or flushed pulse.
GEM completion toggles at sample 461 and acknowledgement at 462; status
remains zero. Raw captures and the comparison are under ignored
`build/gem1_debug/fixed/`.

The UART reports `DHCP IPv4 acquired: 10.0.1.214`. Before ping, a live JTAG
sample records four successful GEM1 TX frames, zero TX underruns and 98 RX
frames. Five ICMP echo requests from host `10.0.1.24` (`eth1`) all succeed,
with 0.684–1.834 ms round-trip times. This verifies bidirectional GEM1 traffic
through the fabric and R5 CPU port, not sustained throughput or fault recovery.
Subsequent cable-move tests passed ping on the other three copper ports;
see [four-port results](verification.md#four-copper-ports-passing-dhcp-address-ping-2026-09-20).
DHCP renewal and fault recovery remain untested.

## Debug-image timing

The corrected RTL plus ILAs initially produced five PL0 RGMII RX hold
violations (worst −0.145 ns). The debug build sets the five existing PL0 RX
IDELAYE3 data/control delays to 900 ps instead of the board RTL default of
700 ps. This changes input sampling for the debug image only; it does not
relax timing constraints. Routed setup/hold slack is +0.018/+0.010 ns under
the existing constraints. The build rejects a negative setup or hold slack.
PL0 was disconnected and disabled during the initial GEM1 test. A later
cable move to PL0 passed 20/20 pings using this 900 ps debug setting. Sustained
receive testing and the remaining unconstrained/CDC paths still require
separate validation. PL1's 750 ps setting is unchanged.

The normal non-ILA bitstream must be rebuilt after changing the bridge RTL;
use the explicit debug bitstream argument above for this session. No flash
image was written.

The timing-corrected image was reloaded and captured again: the same 314-byte
match and successful completion were observed, DHCP again acquired
`10.0.1.214`, and another five pings passed (0.665–2.232 ms, zero loss).
Final evidence is in ignored `build/gem1_debug/final/`; the R5 is left running
this image.

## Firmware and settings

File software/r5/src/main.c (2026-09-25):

#include "board.h"
#include "config.h"
#include "statistics.h"
#include "snmp.h"
#include "web.h"
#include "stp.h"
#include "FreeRTOS.h"
#include "task.h"
static void startup(void *arg)
{
    (void)arg;
    settings_init();
    configASSERT(xTaskCreate(statistics_task,"stats",1024,NULL,3,NULL)==pdPASS);
    configASSERT(xTaskCreate(sensors_task,"sensors",1024,NULL,1,NULL)==pdPASS);
    network_start();
    configASSERT(xTaskCreate(snmp_task,"snmp",4096,NULL,1,NULL)==pdPASS);
    configASSERT(xTaskCreate(web_task,"http",4096,NULL,1,NULL)==pdPASS);
    configASSERT(xTaskCreate(board_link_task,"links",2048,NULL,2,NULL)==pdPASS);
    configASSERT(xTaskCreate(stp_task,"stp",2048,NULL,2,NULL)==pdPASS);
    vTaskDelete(NULL);
}
int main(void)
{
    /* FSBL must initialize PS clocks/DDR/PHY resets and load the fabric first. */
    board_init();
    configASSERT(xTaskCreate(startup,"startup",2048,NULL,5,NULL)==pdPASS);
    vTaskStartScheduler();
    board_assert(__FILE__,__LINE__);
    return 1;
}

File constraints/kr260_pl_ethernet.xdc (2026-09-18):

# kr260_pl_ethernet.xdc
#
# Real pin/bank/electrical constraints for the KR260 carrier's two PL
# RGMII Ethernet ports (PL0/PL1 -- physical ports 2-3 in this project's
# port numbering, see switch_top.sv). Originally built from Vivado's own
# KR260 board files, then independently cross-checked pin-by-pin against
# the real carrier schematic (docs/xtp743/038-05101-01_sck-kr_reva02_SKIT_20211015.pdf,
# sheets 6/7 "SOM240_1/2 Connector", 16 "Clock Gen, Reset", 20/21 "PL
# GEM2/GEM3 RGMII ETHERNET") -- every pin/net below matches both sources
# exactly. One real discrepancy was found and matters even though it
# doesn't change any pin/bank/IOSTANDARD value here: the PHY is a Texas
# Instruments DP83867CSRGZ per the schematic, not the Marvell
# "M88E1111_BAB1C000" Vivado's board file claims (component
# "pl_gem2"/"pl_gem3" in kr260_carrier/2.0/board.xml) -- relevant for any
# future MDIO register-level PHY driver/config code, which would target
# entirely different registers on the two parts.
#
# Sources:
#   - pin/bank/net names (board file):
#     /tools/Xilinx/2026.1/data/xhub/boards/XilinxBoardStore/boards/Xilinx/kr260_carrier/2.0/board.xml
#     (interfaces "pl_gem2_rgmii"/"pl_gem3_rgmii" and their MDIO/reset/
#     25MHz-oscillator siblings -- Xilinx's own board file names the two
#     PL ports "pl_gem2"/"pl_gem3", continuing the PS's GEM0/GEM1
#     numbering; this project calls them PL0/PL1)
#   - SOM-connector-pin -> actual XCK26 package pin resolution:
#     /tools/Xilinx/2026.1/data/xhub/boards/XilinxBoardStore/boards/Xilinx/kr260_som/2.0/part0_pins.xml
#   - PIN_FUNC/BANK confirmation (both RXC pins are genuinely clock-
#     capable ("_GC_"), both ports are each entirely within one I/O bank
#     -- PL0 in bank 66, PL1 in bank 65) and the legal IDELAYE3
#     DELAY_VALUE range for DELAY_FORMAT="TIME" on this part (0-1100,
#     narrower than UG571's general text suggests): both confirmed by
#     actually querying/simulating against this part in Vivado 2026.1,
#     not assumed from documentation alone.
#
# The 25MHz `ref_clk_25m` pins are each one of four buffered taps (a 1:4
# clock buffer, NB3V1104CDTR2G) off a *single* shared 25MHz oscillator
# (schematic sheet 16) -- the other two taps feed the two PHYs' own
# crystal inputs directly, so this pin is phase-related to the same
# oscillator each PHY uses internally, not an independent/arbitrary
# clock (a board.xml reading alone made these look like two fully
# separate per-port oscillator components; the schematic shows they
# share one source).
#
# `phy_reset_n` is not a direct FPGA-to-PHY reset: per schematic sheet
# 16, this net (HPA05_CCN/HPB05_CCN) is a *reset request* input to a
# board-level sequencer IC (U19, SLG7XL45106, an I2C-configurable
# GreenPAK-style part, I2C addr 0x10/0x11) which — combined with
# power-good and whatever its I2C configuration says, not visible in the
# schematic — produces the PHY's actual RESET_B. The pin/bank/IOSTANDARD
# below is still correct (this net, not the PHY's real reset pin, is
# what's actually routed to the FPGA), but don't assume asserting it
# behaves like a simple, immediate, guaranteed-independent-of-the-other-
# port reset without more information about U19's configuration.
#
# Targets a hypothetical future top-level module (not yet built --
# switch_top.sv deliberately stops at the GMII boundary, see
# rgmii_gmii_adapter.sv's header) instantiating two rgmii_gmii_adapter
# instances named following this project's established per-port-prefix
# convention (pl0_/pl1_, matching e.g. switch_top.sv's own sfp_*/
# gtx_clk_pl0 naming) with ports:
#   <port>_rgmii_txd[3:0], <port>_rgmii_tx_ctl, <port>_rgmii_txc (outputs)
#   <port>_rgmii_rxd[3:0], <port>_rgmii_rx_ctl, <port>_rgmii_rxc (inputs)
#   <port>_mdio (inout), <port>_mdc (out), <port>_phy_reset_n (out -- see above)
#   <port>_ref_clk_25m (in, one of four taps off a shared board oscillator -- see above)
# Rename to match whatever that top level actually calls them once built.
#
# NOT included here -- board data doesn't exist for it (see
# docs/inventory.md's SFP transceiver entry): the SFP cage's GTH channel
# location and reference clock. Also not included: the RX skew-
# compensation IDELAYE3's own reference clock (idelay_refclk_i, 200-
# 800MHz-class per UG571) -- no such clock exists anywhere on this board
# per the schematic; a real bring-up needs to generate one (e.g. via an
# MMCM fed from one of the two `ref_clk_25m` pins below, both confirmed
# clock-capable) as a board-integration-level decision, see
# rgmii_gmii_adapter.sv's header.

# ============================== PL0 (pl_gem2) ==============================
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

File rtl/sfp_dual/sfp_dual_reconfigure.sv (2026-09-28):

// Always-on 50 MHz domain. Read/modify/write/readback preserves reserved bits.
// A failed operation holds the datapath in reset; a new request retries it.
module sfp_dual_reconfigure #(
 parameter integer DRP_TIMEOUT=1024, LOCK_TIMEOUT=5000000, RESET_CYCLES=128
)(input wire clk,rst_n,request_10g,retry_toggle,
 input wire power_good,pll_locked,tx_done,rx_done,
 output reg mode_10g,ready,error,
 output wire gt_reset,
 output wire [9:0] drp_addr, output reg [15:0] drp_di,
 output reg drp_en,drp_we,input wire [15:0] drp_do,input wire drp_rdy);
 localparam HOLD=0,READ=1,READ_WAIT=2,WRITE=3,WRITE_WAIT=4,
            VERIFY=5,VERIFY_WAIT=6,NEXT=7,RELEASE=8,LOCK=9,RUN=10,FAILED=11;
 reg [3:0] state;
 reg [23:0] timer;
 reg [5:0] index;
 reg seen_retry,tx_reset_seen,rx_reset_seen;
 wire [15:0] mask,value; wire last;
 sfp_dual_drp_rom rom(index,mode_10g,drp_addr,mask,value,last);
 assign gt_reset=state!=LOCK && state!=RUN;
 always @(posedge clk) begin
   if (!rst_n) begin
     state<=HOLD;timer<=0;index<=0;mode_10g<=1;ready<=0;error<=0;
     drp_en<=0;drp_we<=0;drp_di<=0;seen_retry<=0;tx_reset_seen<=0;rx_reset_seen<=0;
   end else begin
     drp_en<=0;drp_we<=0;
     case(state)
       HOLD: begin
         mode_10g<=request_10g;seen_retry<=retry_toggle;
         if(!power_good) timer<=0;
         else if(timer==RESET_CYCLES-1) begin state<=READ;timer<=0;end else timer<=timer+1'b1;
       end
       READ: begin drp_en<=1;state<=READ_WAIT;timer<=0;end
       READ_WAIT: if(drp_rdy) begin drp_di<=(drp_do & ~mask)|value;state<=WRITE;end
                  else if(timer==DRP_TIMEOUT-1) begin state<=FAILED;error<=1;end else timer<=timer+1'b1;
       WRITE: begin drp_en<=1;drp_we<=1;state<=WRITE_WAIT;timer<=0;end
       WRITE_WAIT: if(drp_rdy) state<=VERIFY;
                   else if(timer==DRP_TIMEOUT-1) begin state<=FAILED;error<=1;end else timer<=timer+1'b1;
       VERIFY: begin drp_en<=1;state<=VERIFY_WAIT;timer<=0;end
       VERIFY_WAIT: if(drp_rdy) begin
                       if((drp_do & mask)!=value) begin state<=FAILED;error<=1;end else state<=NEXT;
                    end else if(timer==DRP_TIMEOUT-1) begin state<=FAILED;error<=1;end else timer<=timer+1'b1;
       NEXT: if(last) begin state<=RELEASE;timer<=0;end else begin index<=index+1'b1;state<=READ;end
       RELEASE: if(timer==RESET_CYCLES-1) begin state<=LOCK;timer<=0;tx_reset_seen<=0;rx_reset_seen<=0;end else timer<=timer+1'b1;
       LOCK: begin
         // Wizard reset-all starts its TX-then-RX sequence on deassertion.
         // Old done flags can remain high until each sub-sequence starts.
         if(!tx_done) tx_reset_seen<=1;
         if(!rx_done) rx_reset_seen<=1;
         if(tx_reset_seen && rx_reset_seen && pll_locked && tx_done && rx_done) begin ready<=1;state<=RUN;end
         else if(timer==LOCK_TIMEOUT-1) begin state<=FAILED;error<=1;end else timer<=timer+1'b1;
       end
       RUN: if(!pll_locked || !tx_done || !rx_done) begin ready<=0;state<=LOCK;timer<=0;tx_reset_seen<=1;rx_reset_seen<=1;end
       FAILED: ready<=0;
       default: begin state<=FAILED;ready<=0;error<=1;end
     endcase
     // Requests are held stable by the digital port until ready. Only change
     // PLL/clock mux controls while the GT is held in reset in HOLD.
     if((state==RUN || state==FAILED || state==LOCK) &&
        (request_10g!=mode_10g || retry_toggle!=seen_retry)) begin
       state<=HOLD;ready<=0;error<=0;timer<=0;index<=0;
     end
   end
 end
endmodule

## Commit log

2026-09-18 Add switch RTL baseline, tests, and architecture inventory
2026-09-19 Add KR260 board build and GEM recovery; update design inventory
2026-09-20 Advance 100 MHz switch datapath and link control; refresh design inventory
    Check in word-wide MAC adapters, DMA prefetch, port flushing, PHY polling, IDELAY reset gating and expanded regression benches. Add the FreeRTOS 202604-LTS submodule reference. Update architecture, register maps, pending work and verification evidence.
    [tb_buf_mgr_core.sv, tb_cpu_port_top.sv, tb_egress_gem_tx_integration.sv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]
2026-09-21 Fix SFP receive equalization and exclude ingress from forwarding
    Select LPM, filter same-port lookup hits with six-port regression coverage, and verify the normal implementation contains no debug cores and meets timing. Document the ILA-free hardware build, DHCP/ping results, and remaining validation limits.
    [tb_mac_forwarding_top.sv]
2026-09-21 Enable R5 data cache with non-cacheable DMA storage
    Reserve a 32 KiB MPU region for DMA descriptors and bounce buffers, validate memory placement and startup attributes, and record hardware verification. Document future review of descriptor and packet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
2026-09-22 Add switch statistics, sensor monitoring and SNMP management
    Implement standard port counters and optional DDR/debug instrumentation, R5 accumulation and environmental sampling, and a read-only SNMPv2c agent with a lab MIB and reader script.
    Document all-counter implementation, board validation and outstanding SFP negotiation and statistics mailbox timeout investigations.
2026-09-22 Add R5 web management, timeout diagnostics and pipelined ingress DMA
2026-09-25 begin partition to ip repo centric flow
2026-09-25 Instantiate catalog IPs in production block design and record board validation
2026-09-25 Add independent IP regression suites and strengthen catalog validation
    [tb_ps_gem_axis_bridge.sv]
2026-09-26 Replace CPU TX override CDC with frame metadata and pipeline CPU writes
    [tb_cpu_dma_pipeline.sv]
2026-09-26 Run switch fabric at 125 MHz and report hardware clock frequency
2026-09-26 Add low-priority MAC table DMA and manual web refresh
    Integrate fabric 1.2 with a fourth HP0 master, preemptible MAC table reads, 16-beat writes, and a cache-safe R5 interface. Add a public manually refreshed web view with isolated DMA and published buf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
    Document routed timing, successful JTAG deployment, 1000-packet CPU and forwarded-endpoint checks, HTTP concurrency, and the current development backlog.
2026-09-27 Support full-duplex 10/100/1000 on PL Ethernet ports
    Add RGMII rate conversion, independent MAC byte pacing, safe PHY advertisement changes, and web/SNMP capability reporting. Document simulation, routed timing, both-port board validation, and the outs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
2026-09-28 Add STP/RSTP, CPU DMA interrupts and KR260 enclosure
    Vendor the pinned mstp-lib engine and integrate persistent STP/RSTP controls,
    port state enforcement, ingress-tag backpressure and regression coverage.
    Use DMA completion/error interrupts for CPU TX/RX task wakeups, retain
    fail-closed ownership, and expose non-cacheable hardware diagnostics.
    Show active IPv4 settings separately from saved preferences and widen the
    configuration address and credential fields.
    Add the carrier-model-based screw-fastened clamshell, printable parts,
    regeneration sources and validation reports. Keep downloaded references local.
    Update architecture, configuration, build and hardware verification records.
    Valid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
    [base.stl, clamshell.step, fit_coupon.stl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]
2026-09-28 Add selectable 10G and runtime dual-rate SFP switch ports
    Package 10GBASE-R and dual 1000BASE-X/10GBASE-R MAC/PCS cores, widen the SFP fabric path, and reconfigure one GTH channel at runtime. Add firmware Auto/forced-rate controls, mode-change recovery, explicit clock constraints, and digital/transceiver regressions.
    Record routed timing acceptance and hardware 1G, hot-swap, 10G host-link and forwarding results. Document observed packet loss, copper-only controls, and remaining rate-conversion qualification.
    [sfp_dual_reconfigure.sv, tb_mac_forwarding_top.sv]
2026-09-29 Add minimal A53 Linux JTAG boot alongside R5 switch firmware

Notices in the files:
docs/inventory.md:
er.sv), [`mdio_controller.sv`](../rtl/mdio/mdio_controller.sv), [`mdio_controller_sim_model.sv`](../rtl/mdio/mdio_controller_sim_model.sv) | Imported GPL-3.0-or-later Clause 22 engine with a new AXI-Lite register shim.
